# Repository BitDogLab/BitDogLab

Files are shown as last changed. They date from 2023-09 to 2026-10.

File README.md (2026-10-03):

<p align="center">
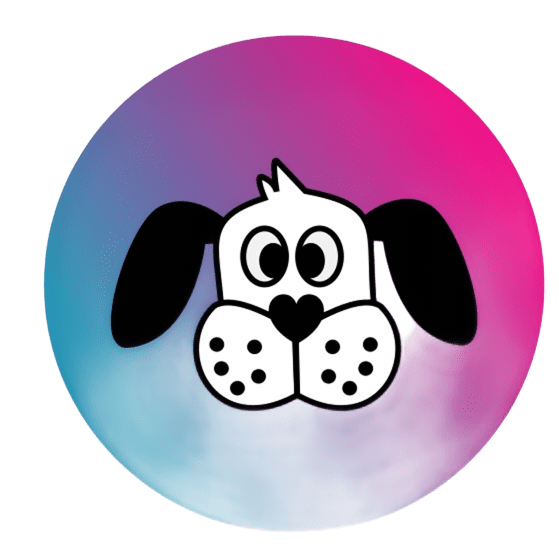
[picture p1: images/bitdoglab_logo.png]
BitDogLab logo
  
</p>

<h1 align="center">BitDogLab V7</h1>

<p align="center">
  Open-source educational hardware for embedded systems, programming, electronics, and physical computing.
</p>

<p align="center">
  <a href="README.md">English</a> |
  <a href="README.pt-BR.md">Português</a>
</p>

<p align="center">
  
  <br>
  <a href="https://comunidade-bitdoglab.web.app">https://comunidade-bitdoglab.web.app</a>
</p>

<p align="center">
  Não é da área de tecnologia? Este repositório é o espaço técnico do projeto — para professores e demais usuários, a <a href="https://comunidade-bitdoglab.web.app"><strong>Comunidade BitDogLab</strong></a> é uma porta de entrada mais amigável, com documentação, códigos e aplicações prontas.
</p>

BitDogLab is an initiative of the **Escola 4.0 project at FEEC/Unicamp**. It brings together the Raspberry Pi Pico ecosystem and the main peripherals used in embedded systems, providing a practical platform for education, experimentation, and project development.

The current board is **BitDogLab Version 7**, with support for Raspberry Pi Pico-compatible modules based on the **RP2040** and **RP2350** microcontrollers.

Its hands-on approach supports the development of scientific thinking, problem solving, collaboration, and digital culture, competencies emphasized by Brazil's National Common Curricular Base (BNCC).

---

## Board and Peripherals

<p align="center">
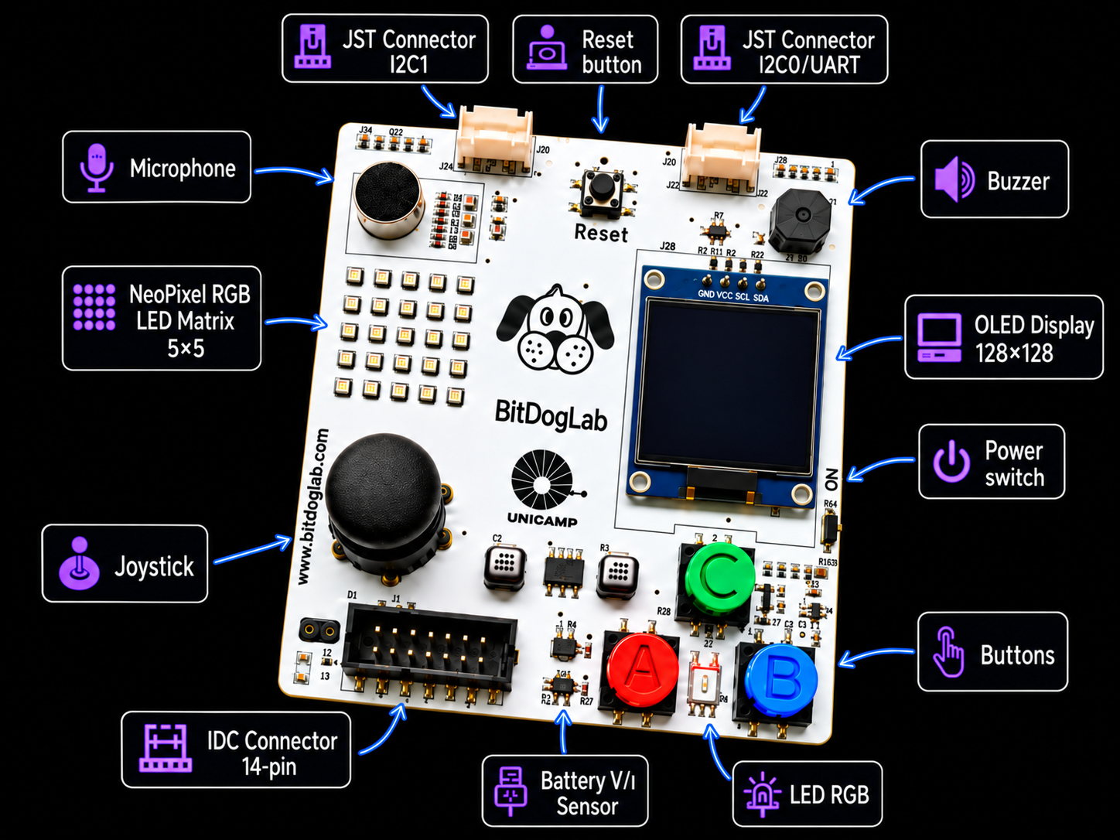
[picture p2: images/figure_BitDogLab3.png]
BitDogLab board and onboard peripherals
  
</p>

The board provides direct access to the main resources used in embedded-system education, including buttons, joystick, RGB LED, LED matrix, OLED display, microphone, buzzer, sensors, and expansion connectors.

---

## Recommended Learning Path

<p align="center">
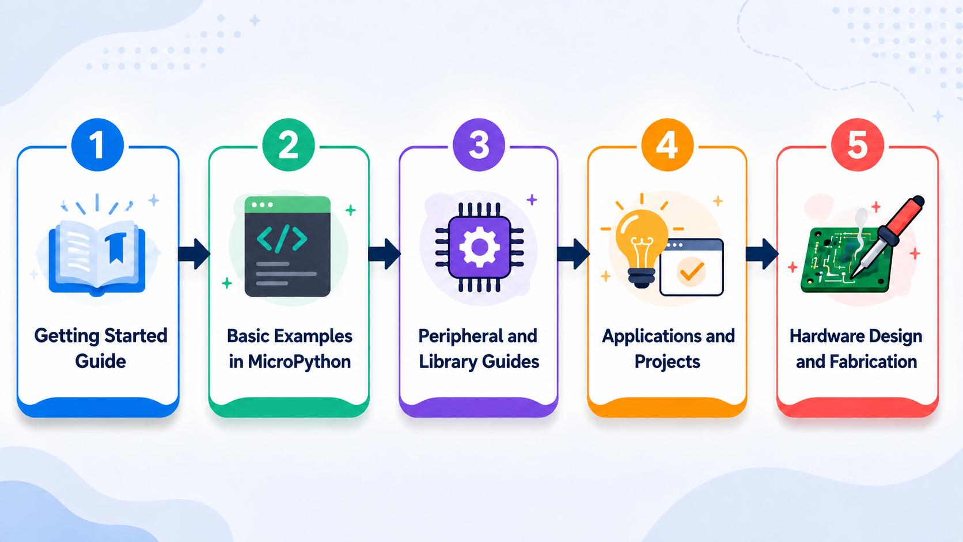
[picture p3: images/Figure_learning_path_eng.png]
Learning Path
  
</p>

```mermaid
flowchart LR
    A[Start Here guide] --> B[Basic MicroPython examples]
    B --> C[Peripheral guides and libraries]
    C --> D[Applications and projects]
    D --> E[Hardware design and fabrication]
```

1. Follow the [Start Here guide](COMECE_POR_AQUI_BitDogLab_V7_MicroPython.md) to prepare the board and run the first test.
2. Study the [`basic-examples/`](basic-examples/) directory, organized from simpler to more advanced peripherals.
3. Use the [V7 peripheral guides](doc/Bitdoglab%20V7/) and reusable [`libs_software/`](libs_software/) modules.
4. Explore and develop applications in [`projects/`](projects/).
5. Study or manufacture the board using the public files in [`pcb-prototyping/`](pcb-prototyping/).

---

## Start Programming

The fastest text-based path is MicroPython with Thonny:

- [Illustrated MicroPython start guide](COMECE_POR_AQUI_BitDogLab_V7_MicroPython.md)
- [60 basic peripheral examples](basic-examples/README.md)
- [Complete peripheral test](testar_perifericos_gerais.py)
- [MicroPython firmware](firmware/)
- [Reusable software libraries](libs_software/README.md)

---

## Active Programming Projects

Below are the tools currently being developed within the BitDogLab ecosystem to support different entry points into programming — from block-based logic to AI-assisted code generation.

### 🧩 Blockly for BitDogLab

Blockly is the easiest way to get started with BitDogLab. It is designed for students and beginners learning programming logic and embedded systems. The tool runs directly in the browser without requiring installation.

To use it:

[Open Blockly for BitDogLab](https://bitdoglab-blocos.github.io/BIPES-BITDOGLAB/ui/)

1. Connect the BitDogLab to the computer using a USB cable.
2. Open Blockly for BitDogLab, preferably in Chrome or Edge.
3. Select the serial port corresponding to the board.
4. Drag and connect blocks to create the program.
5. Click `Run` or `Upload` to send the program to the BitDogLab.

> **Important:** If the board already contains a file named `main.py`, remove it before using Blockly. This file can prevent the tool from communicating correctly with the microcontroller.

<br>

### 📄 BIH — Hardware Information Database

<p align="center">
  <a href="https://docs.google.com/document/d/13-68OqiU7ISE8U2KPRUXT2ISeBl3WPhXjGDFH52eWlU/edit?usp=sharing">
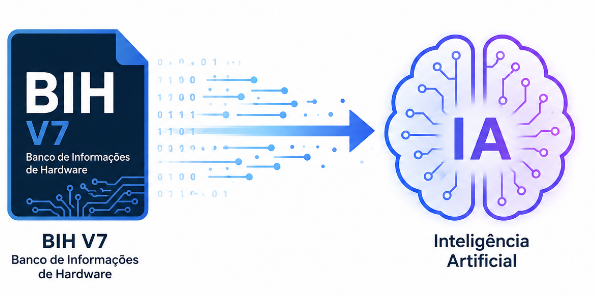
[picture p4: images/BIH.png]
BIH hardware information database for AI-assisted programming
    
  </a>
</p>

The **BIH** is a hardware information database designed to adapt the BitDogLab technical context for Large Language Models (LLMs), including ChatGPT, Gemini, and other AI assistants.

It describes the board's pin assignments, peripherals, interfaces, and hardware constraints. By providing the BIH to an LLM before requesting a program, the model can generate MicroPython or C/C++ code that better matches the BitDogLab hardware.

- [Open the BitDogLab V7 BIH](https://docs.google.com/document/d/13-68OqiU7ISE8U2KPRUXT2ISeBl3WPhXjGDFH52eWlU/edit?usp=sharing)
- [Open the visual hardware database](https://docs.google.com/document/d/1-2Eoo6H1gfTAlxZgFs26p7X4CeaLkS8X8hNTC96PetQ/edit?usp=sharing)

<br>

### 🔀 FluxCode

O BitDogLab FluxCode é um aplicativo Android que usa **IA multimodal** para transformar fluxogramas desenhados à mão em código **MicroPython** pronto para rodar na BitDogLab. A proposta é desplugada: o estudante primeiro desenvolve a lógica no papel usando símbolos de fluxograma, fotografa o desenho pelo app e recebe automaticamente o código correspondente, que pode ser executado ou salvo direto na placa.

Para usar:

[Baixar o BitDogLab FluxCode](https://drive.google.com/drive/folders/12xD7rVUsgQWKkneTLb5EA2QpiOx43nXb?usp=drive_link)

1. Conecte a BitDogLab ao smartphone via USB.
2. Desenhe o fluxograma em papel usando o gabarito de símbolos.
3. No app, toque em **Foto Código** e fotografe o fluxograma.
4. Revise o código MicroPython e o pseudocódigo gerados automaticamente.
5. Toque em **Executar** para rodar na placa, ou salve como `main.py` para execução automática ao ligar.

> Disponível apenas para Android. Requer MicroPython instalado na placa e um cabo USB compatível com transferência de dados (não apenas carregamento).

<br>

### 🎨 Pixel Art Application

**UNDER CONSTRUCTION**

---

## BitDogLab V7 Hardware

BitDogLab V7 integrates an RGB LED, a 5x5 WS2812B matrix, three buttons, analog joystick, buzzer, analog microphone, OLED display, power monitoring, and expansion connections around a Raspberry Pi Pico-compatible module.

The V7 hardware was developed in **Altium Designer**. Source files, schematic, PCB layout, BOM, pick-and-place data, STEP model, and public Gerber files for fabrication are available in [`pcb-prototyping/BitDogLab V7/`](pcb-prototyping/BitDogLab%20V7/).

<p align="center">
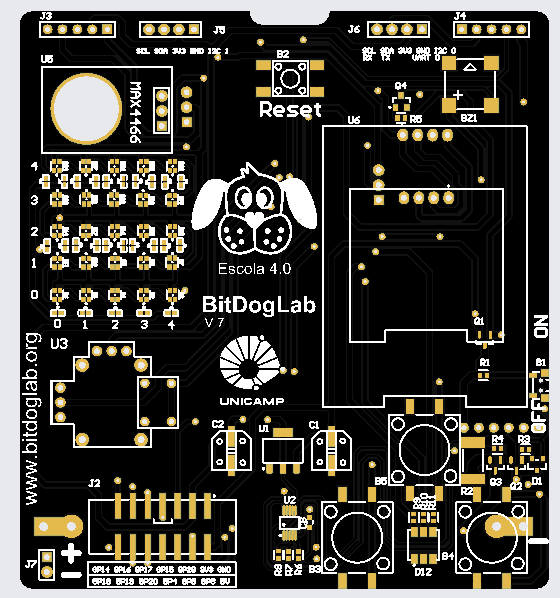
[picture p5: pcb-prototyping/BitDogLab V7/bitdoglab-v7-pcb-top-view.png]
BitDogLab V7 PCB top view
  
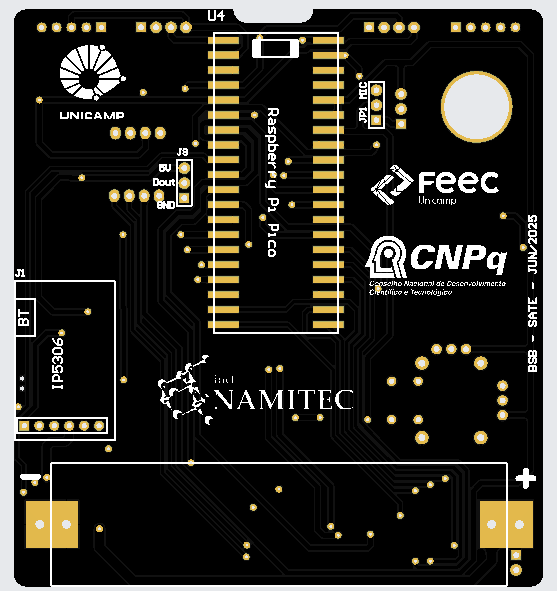
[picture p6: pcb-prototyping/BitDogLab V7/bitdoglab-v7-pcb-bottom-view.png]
BitDogLab V7 PCB bottom view
  
</p>

BitDogLab V6 was developed in **KiCad** and remains available for study and fabrication. See the complete [PCB and fabrication documentation](pcb-prototyping/README.md).

---

## Repository Structure

| Path | Content |
|---|---|
| [`basic-examples/`](basic-examples/) | Beginner-friendly MicroPython examples organized by peripheral. |
| [`doc/`](doc/) | BitDogLab V6 and V7 documentation and peripheral guides. |
| [`firmware/`](firmware/) | MicroPython firmware and installation resources. |
| [`libs_software/`](libs_software/) | Reusable MicroPython drivers and helper modules. |
| [`pcb-prototyping/`](pcb-prototyping/) | PCB source files and public manufacturing files. |
| [`projects/`](projects/) | Applications, sensors, IoT, tools, and hardware expansions. |

---

## Open Hardware and License

BitDogLab is open hardware. Its design and fabrication files are publicly available for study, modification, and manufacturing.

The project is licensed under the **CERN Open Hardware Licence Version 2 - Strongly Reciprocal (CERN-OHL-S v2.0)**. See [`LICENSE`](LICENSE).

---

## Initiative and Contributors

- Initiative: **Escola 4.0 - FEEC/Unicamp**
- Project coordination: **Prof. Dr. Fabiano Fruett**
- Contributors: students and collaborators from Escola 4.0 and FEEC/Unicamp
- Support: IEEE-EDS STEM outreach program and CNPq - INCT Namitec

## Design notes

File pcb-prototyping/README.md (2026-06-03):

# PCB Prototyping / Prototipagem de PCB

[English](#english) | [Portugues](#portugues)

## English

This directory contains the public PCB design and fabrication files for the BitDogLab boards.

The folder name is `pcb-prototyping` because not every file here was created in KiCad. It includes KiCad projects, Altium projects, manufacturing outputs, 3D models, images, BOM files and support libraries.

### Folder Structure

```text
pcb-prototyping/
+-- BitDogLab V6/
|   +-- bitdoglab-through-hole/
|   +-- bitdoglab-smd/
|   +-- component-libraries/
+-- BitDogLab V7/
    +-- Project Outputs for BitDogLab V7/
    +-- __Previews/
    +-- History/
    +-- bitdoglab-v7-pcb-top-view.png
    +-- bitdoglab-v7-pcb-bottom-view.png
```

### BitDogLab V6

BitDogLab V6 was developed in KiCad.

- `bitdoglab-through-hole/`: through-hole/DIY KiCad project files.
- `bitdoglab-smd/`: SMD KiCad project files, schematic, PCB layout, fabrication outputs and board images.
- `component-libraries/`: symbols, footprints, 3D models and support files used by the KiCad projects.

Common KiCad files found here:

- `.kicad_pro`: KiCad project file.
- `.kicad_sch`: schematic file.
- `.kicad_pcb`: PCB layout file.
- `.kicad_mod`: footprint file.
- `.kicad_sym`: symbol library file.
- `.step` / `.stp`: 3D model files.
- `.zip`: fabrication package when available.
- `.csv` / `.xlsx`: BOM or component data when available.

### BitDogLab V7

BitDogLab V7 was developed in Altium Designer.

<p align="center">
  BitDogLab V7 PCB top view
  BitDogLab V7 PCB bottom view
</p>

Main files:

- `BitDogLab V7.PrjPcb`: Altium PCB project.
- `BitDogLab V7.SchDoc`: Altium schematic document.
- `BitDogLab V7.PcbDoc`: Altium PCB layout document.
- `BitDogLab V7.OutJob`: Altium output job configuration.
- `BitDogLab V7.pdf`: exported schematic/documentation PDF.
- `BitDogLab V7_Lista de Materiais com Custo.xlsx`: bill of materials with cost information.
- `BitDogLab V7_Gerber.rar`: Gerber fabrication package.
- `Project Outputs for BitDogLab V7/`: manufacturing outputs exported from the project, including Gerber layers, drill reports, BOM, pick-and-place and 3D STEP model.
- `bitdoglab-v7-pcb-top-view.png`: technical top view image of the PCB.
- `bitdoglab-v7-pcb-bottom-view.png`: technical bottom view image of the PCB.

### Public Fabrication Files

Gerber files are publicly available for fabrication. They can be used by PCB manufacturers to produce the board.

Before ordering a board, review the fabrication package, BOM, drill files and pick-and-place data. Manufacturing settings can vary by supplier, so the files should always be checked in a Gerber viewer or CAM tool before production.

### Notes

- KiCad is recommended for opening and editing the BitDogLab V6 project files.
- Altium Designer is recommended for opening and editing the BitDogLab V7 source project files.
- Gerber and drill files can usually be inspected with vendor tools or independent Gerber viewers.
- Board images are provided as visual references and are not a replacement for fabrication data.

## Portugues

Esta pasta contem os arquivos publicos de projeto e fabricacao das placas BitDogLab.

O nome da pasta e `pcb-prototyping` porque nem todo arquivo aqui foi desenvolvido no KiCad. Ela inclui projetos KiCad, projetos Altium, arquivos de fabricacao, modelos 3D, imagens, listas de materiais e bibliotecas de apoio.

### Estrutura de Pastas

```text
pcb-prototyping/
+-- BitDogLab V6/
|   +-- bitdoglab-through-hole/
|   +-- bitdoglab-smd/
|   +-- component-libraries/
+-- BitDogLab V7/
    +-- Project Outputs for BitDogLab V7/
    +-- __Previews/
    +-- History/
    +-- bitdoglab-v7-pcb-top-view.png
    +-- bitdoglab-v7-pcb-bottom-view.png
```

### BitDogLab V6

A BitDogLab V6 foi desenvolvida no KiCad.

- `bitdoglab-through-hole/`: arquivos KiCad da versao through-hole/DIY.
- `bitdoglab-smd/`: arquivos KiCad da versao SMD, esquematico, layout da placa, saidas de fabricacao e imagens da placa.
- `component-libraries/`: simbolos, footprints, modelos 3D e arquivos de apoio usados pelos projetos KiCad.

Arquivos KiCad comuns nesta pasta:

- `.kicad_pro`: arquivo de projeto KiCad.
- `.kicad_sch`: arquivo de esquematico.
- `.kicad_pcb`: arquivo de layout da PCB.
- `.kicad_mod`: arquivo de footprint.
- `.kicad_sym`: biblioteca de simbolos.
- `.step` / `.stp`: modelos 3D.
- `.zip`: pacote de fabricacao quando disponivel.
- `.csv` / `.xlsx`: BOM ou dados de componentes quando disponiveis.

### BitDogLab V7

A BitDogLab V7 foi desenvolvida no Altium Designer.

<p align="center">
  Vista superior da PCB BitDogLab V7
  Vista inferior da PCB BitDogLab V7
</p>

Arquivos principais:

- `BitDogLab V7.PrjPcb`: projeto PCB do Altium.
- `BitDogLab V7.SchDoc`: documento de esquematico do Altium.
- `BitDogLab V7.PcbDoc`: documento de layout da PCB no Altium.
- `BitDogLab V7.OutJob`: configuracao de saidas do Altium.
- `BitDogLab V7.pdf`: PDF exportado com esquematico/documentacao.
- `BitDogLab V7_Lista de Materiais com Custo.xlsx`: lista de materiais com informacoes de custo.
- `BitDogLab V7_Gerber.rar`: pacote Gerber para fabricacao.
- `Project Outputs for BitDogLab V7/`: saidas de fabricacao exportadas do projeto, incluindo camadas Gerber, relatorios de furo, BOM, pick-and-place e modelo 3D STEP.
- `bitdoglab-v7-pcb-top-view.png`: imagem tecnica da face superior da PCB.
- `bitdoglab-v7-pcb-bottom-view.png`: imagem tecnica da face inferior da PCB.

### Arquivos Publicos para Fabricacao

Os arquivos Gerber estao disponiveis publicamente para fabricacao. Eles podem ser usados por fabricantes de PCB para produzir a placa.

Antes de encomendar uma placa, revise o pacote de fabricacao, a BOM, os arquivos de furo e os dados de pick-and-place. As configuracoes de fabricacao podem variar conforme o fornecedor, entao os arquivos devem sempre ser conferidos em um visualizador Gerber ou ferramenta CAM antes da producao.

### Observacoes

- O KiCad e recomendado para abrir e editar os arquivos da BitDogLab V6.
- O Altium Designer e recomendado para abrir e editar os arquivos fonte da BitDogLab V7.
- Arquivos Gerber e de furo normalmente podem ser inspecionados em ferramentas dos fabricantes ou em visualizadores Gerber independentes.
- As imagens da placa servem como referencia visual e nao substituem os arquivos de fabricacao.

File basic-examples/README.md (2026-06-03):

# Basic Examples - BitDogLab v7

Exemplos curtos em MicroPython, separados por periferico.

As pastas estao numeradas do mais simples para o mais avancado. Dentro de cada pasta, cada exemplo ja e um arquivo `.py` direto.

Para testar, abra o arquivo do exemplo na Thonny e salve na placa como `main.py`.

## Perifericos

- `01-led-rgb`: 10 exemplos
- `02-botoes`: 10 exemplos
- `03-buzzer`: 10 exemplos
- `04-matriz-led`: 10 exemplos
- `05-display-oled`: 10 exemplos
- `06-joystick`: 5 exemplos
- `07-microfone`: 5 exemplos

## Pinagem usada

- LED RGB: vermelho GPIO13, verde GPIO11, azul GPIO12
- Matriz 5x5 NeoPixel: GPIO7
- Display OLED: SDA GPIO2, SCL GPIO3
- Botoes: A GPIO5, B GPIO6, C GPIO10, joystick GPIO22
- Buzzer: GPIO21
- Joystick: X GPIO27, Y GPIO26
- Microfone: GPIO28

## Observacoes

- Exemplos com display usam `ssd1306.py` na placa.
- Exemplos com matriz usam a biblioteca `neopixel`.
- `read_u16()` retorna valores de 0 a 65535.
- `duty_u16()` tambem usa valores de 0 a 65535 para PWM.

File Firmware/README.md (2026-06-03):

# Firmware Beta v0.1 da BitDogLab com Micropython 1.22.1
### O Firmware da BitDogLab foi compilado em 04/02/2024 e já inclui as seguintes libs 3rd:
* ahtx0 (Sensor de temperatura/umidade AHT10 i2c)
* bh1750 (Sensor de luminosidade i2c)
* ssd1306 (Oled i2c)

## [Download do Firmware](https://github.com/Fruett/BitDogLab/tree/main/Firmware)

# Passo a passo para instalar o firmware da BitDogLab

### 1. Baixe o firmware de acordo com a versão da sua Raspberry pi pico
* [BitDogLab.uf2 para a Raspberry Pico](https://github.com/BitDogLab/BitDogLab/blob/main/Firmware/BitDogLab.uf2)  
* [BitDogLab_W.uf2 para a Raspberry Pico W](https://github.com/BitDogLab/BitDogLab/blob/main/Firmware/BitDogLab_W.uf2)

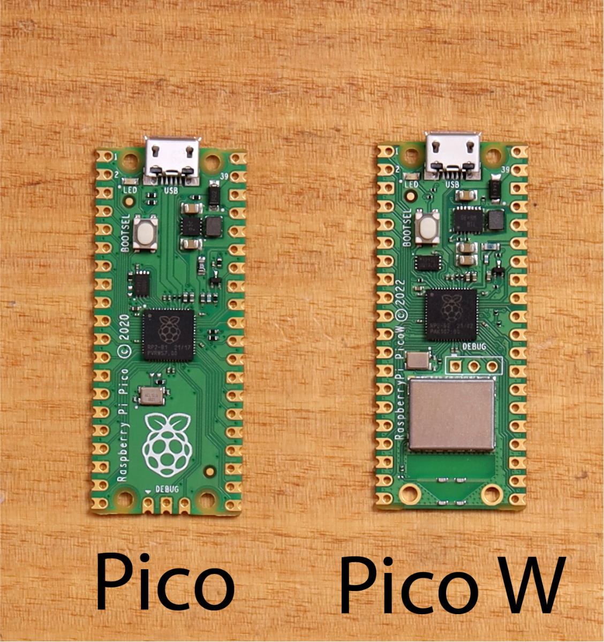
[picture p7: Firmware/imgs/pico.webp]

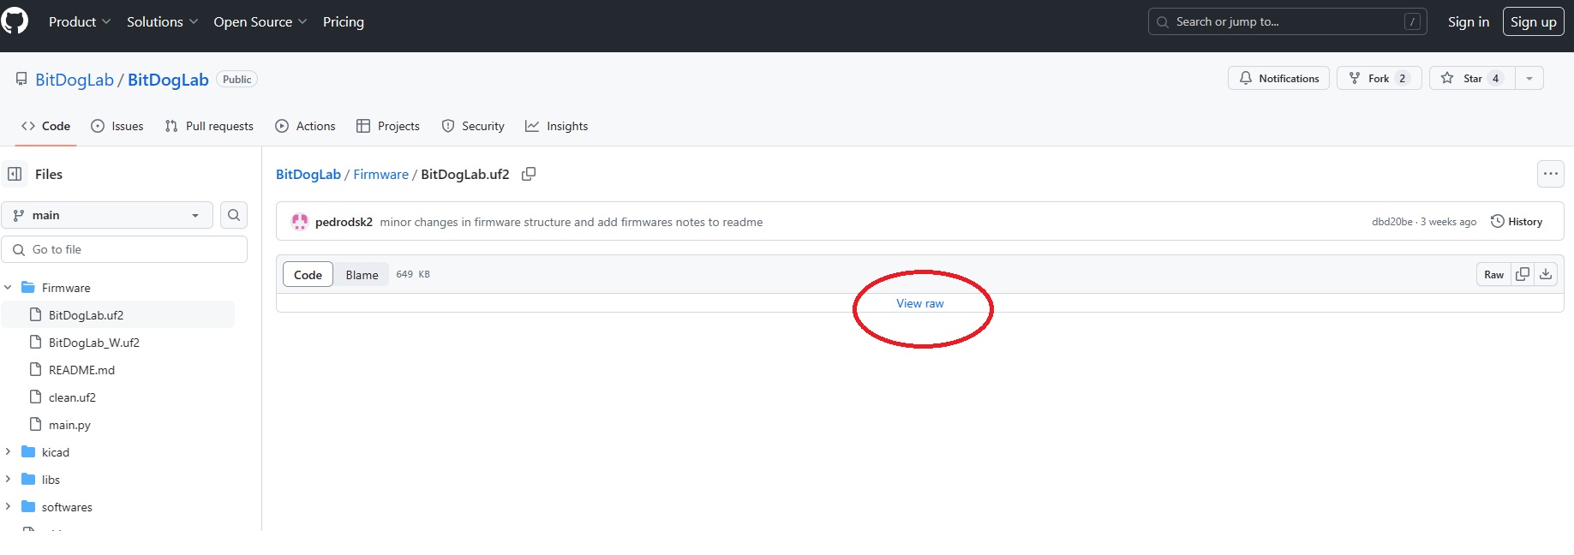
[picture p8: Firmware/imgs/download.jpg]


### 2. Entre no modo bootloader segurando o botão bootsel da raspberry pi, ainda com o botão pressionado, encaixe o cabo micro usb na raspberry pi pico e no computador.

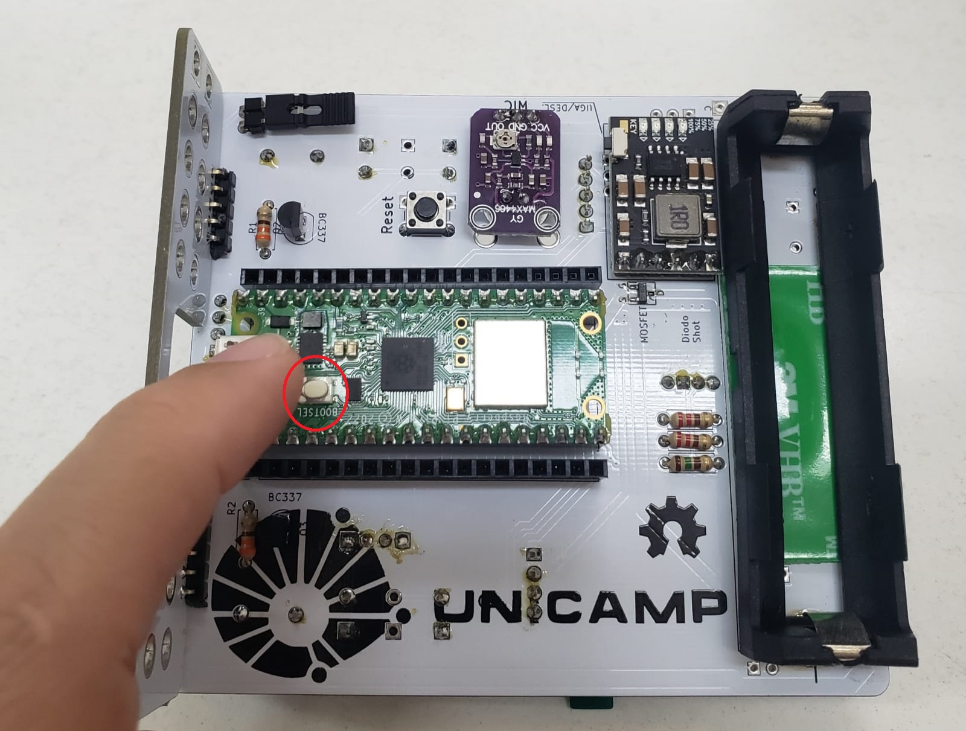
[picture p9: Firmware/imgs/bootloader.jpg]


### 3. Solte o botão e aguarde abrir uma nova janela do windows.

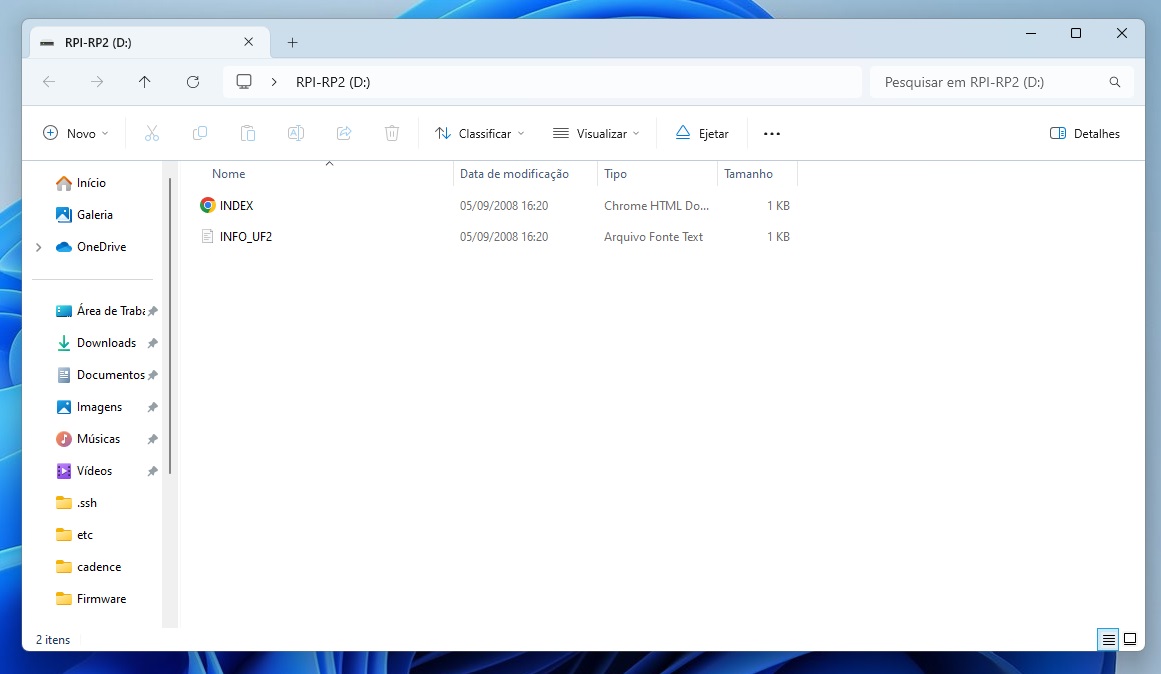
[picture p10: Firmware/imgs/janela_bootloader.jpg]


### 4. Copie o firmware baixado para a janela aberta no passo anterior

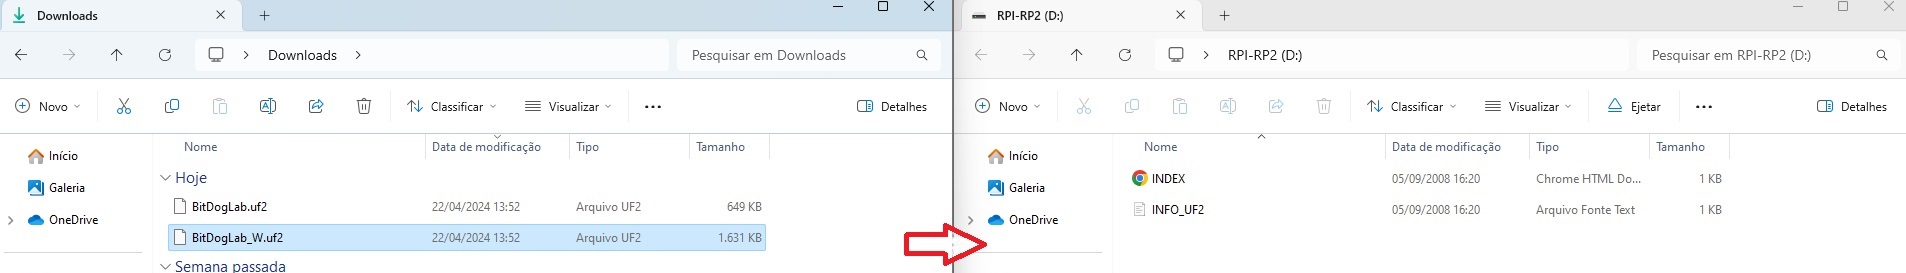
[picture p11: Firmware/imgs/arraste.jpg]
Copie o firmware para pasta de destino


### 5. Desfrute da sua BitDogLab (FIM)

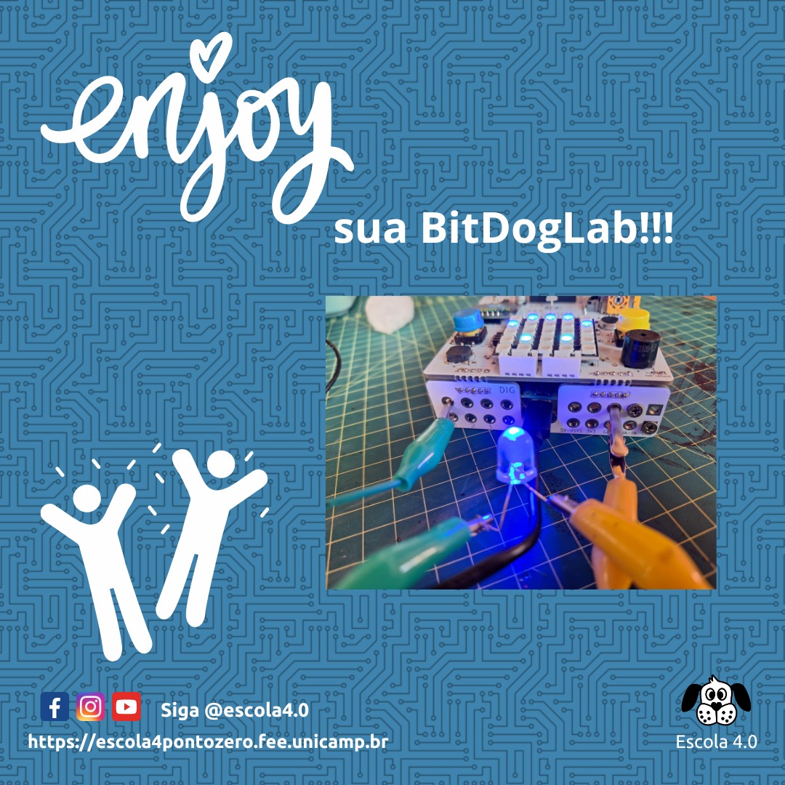
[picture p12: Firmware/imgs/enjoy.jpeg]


# Passo a passo para compilar o firmware da BitDogLab (opcional)
## Estes passos é para um usuário avançado que deseja fazer o build de uma nova versão do firmware com alguma nova personalização.
## Instalar as depedências na rpi4 (Precisa de um raspberry pi 4)
```
sudo apt update -y &
sudo apt install cmake build-essential libffi-dev git pkg-config gcc-arm-none-eabi -y
```
## Clonar os repositórios
```
cd ~/ &
git@github.com:Fruett/BitDogLab.git &
git clone https://github.com/micropython/micropython.git --branch master &
cd micropython &
make -C mpy-cross
```
### 1. Buid - Raspberry PI PICO
```
make -C ports/rp2 BOARD=RPI_PICO clean &
make -C ports/rp2 BOARD=RPI_PICO submodules &
make -C ports/rp2 BOARD=RPI_PICO FROZEN_MANIFEST=~/BitDogLab/libs_software/manifest.py
```
### 2. Build -Raspberry PI PICO W
```
make -C ports/rp2 BOARD=RPI_PICO_W clean
make -C ports/rp2 BOARD=RPI_PICO_W submodules
make -C ports/rp2 BOARD=RPI_PICO_W -j 16 FROZEN_MANIFEST=~/BitDogLab/libs_software/manifest_pico_w.py
```
## Pastas dos Firmwares
* ports/rp2/build-RPI_PICO/firmware.uf2
* ports/rp2/build-RPI_PICO_W/firmware.uf2

# Instalar as libs 3rd em um firmware já existente
```
sudo mpremote mip install github:Fruett/BitDogLab
```

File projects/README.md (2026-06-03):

# Projects

[English](#english) | [Portugues](#portugues)

## English

This folder contains BitDogLab projects, experiments, examples, tools, and hardware expansion projects. It is intended for complete or exploratory code that is larger than a clean beginner example.

Basic, beginner-friendly examples will be kept separately in the root `basic-examples/` folder.

### Folder structure

| Folder | Purpose |
|---|---|
| `hardware-examples/` | Existing examples focused on onboard hardware such as LEDs, buttons, buzzer, joystick, OLED display, microphone, I2C, and the LED matrix. |
| `sensor-examples/` | Existing examples focused on external or onboard sensors, such as accelerometers, light sensors, BME280/BME680, and presence sensors. |
| `hardware-expansion/` | Projects that involve custom hardware, expansion boards, shields, Gerber files, KiCad files, mechanical parts, or dedicated external modules. |
| `iot-communication/` | Projects and experiments related to IoT, LoRa, LoRaWAN, network communication, and connected devices. |
| `application-examples/` | Small application-oriented examples that combine multiple features for a specific use case. |
| `tools/` | Auxiliary software, web tools, visual interfaces, external examples, or support projects. |

### Hardware expansion projects

The `hardware-expansion/` folder includes projects that are not only software examples. These projects may include PCB files, Gerbers, CAD models, custom shields, expansion boards, or mechanical parts.

Current examples:

- `wireless-communication-module/`: wireless communication module previously stored as `WCM`.
- `RoboMovel/`: mobile robot project with code, mechanical files, and custom board files.
- `LoRa_Shield/`: LoRa shield related code and support files.
- `Expansao_PWM/`: software support for a PWM expansion board.

### IoT and communication projects

The `iot-communication/` folder groups projects focused on connectivity and networked applications. This includes LoRa, LoRaWAN, wireless communication experiments, and other IoT-oriented code that does not necessarily include custom hardware files.

### Notes

Some projects in this folder are legacy, experimental, or still being reviewed for BitDogLab v7. Before using them as official v7 examples, check the pin assignments, especially OLED I2C pins, buzzer pins, and any external sensor connections.

## Portugues

Esta pasta contem projetos, experimentos, exemplos, ferramentas e projetos com expansao de hardware da BitDogLab. Ela e destinada a codigos completos ou exploratorios, maiores do que um exemplo basico e limpo para iniciantes.

Os exemplos basicos e didaticos ficarao separados na pasta `basic-examples/`, na raiz do repositorio.

### Estrutura de pastas

| Pasta | Finalidade |
|---|---|
| `hardware-examples/` | Exemplos existentes focados no hardware da placa, como LEDs, botoes, buzzer, joystick, display OLED, microfone, I2C e matriz de LEDs. |
| `sensor-examples/` | Exemplos existentes focados em sensores externos ou embarcados, como acelerometros, sensores de luz, BME280/BME680 e sensores de presenca. |
| `hardware-expansion/` | Projetos que envolvem hardware proprio, placas expansoras, shields, arquivos Gerber, arquivos KiCad, partes mecanicas ou modulos externos dedicados. |
| `iot-communication/` | Projetos e experimentos relacionados a IoT, LoRa, LoRaWAN, comunicacao em rede e dispositivos conectados. |
| `application-examples/` | Pequenos exemplos de aplicacao que combinam varios recursos para um uso especifico. |
| `tools/` | Softwares auxiliares, ferramentas web, interfaces visuais, exemplos externos ou projetos de apoio. |

### Projetos com expansao de hardware

A pasta `hardware-expansion/` inclui projetos que nao sao apenas exemplos de software. Esses projetos podem conter arquivos de PCB, Gerbers, modelos CAD, shields personalizados, placas expansoras ou partes mecanicas.

Exemplos atuais:

- `wireless-communication-module/`: modulo de comunicacao sem fio que antes estava como `WCM`.
- `RoboMovel/`: projeto de robo movel com codigo, arquivos mecanicos e arquivos de placa propria.
- `LoRa_Shield/`: codigo e arquivos de apoio relacionados ao shield LoRa.
- `Expansao_PWM/`: suporte de software para uma placa expansora PWM.

### Projetos de IoT e comunicacao

A pasta `iot-communication/` agrupa projetos focados em conectividade e aplicacoes em rede. Isso inclui LoRa, LoRaWAN, experimentos de comunicacao sem fio e outros codigos voltados a IoT que nao necessariamente incluem arquivos de hardware proprio.

### Observacoes

Alguns projetos nesta pasta sao legados, experimentais ou ainda estao em revisao para a BitDogLab v7. Antes de usa-los como exemplos oficiais v7, confira a pinagem, principalmente os pinos I2C do display OLED, os pinos de buzzer e as conexoes de sensores externos.

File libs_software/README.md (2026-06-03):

# Software Libraries

[English](#english) | [Portugues](#portugues)

## English

This folder contains reusable software libraries for BitDogLab projects, mainly MicroPython modules used by examples, projects, and firmware running on Raspberry Pi Pico/Pico W/Pico 2.

These files are kept separate from project code so they can be copied to the board or imported by multiple examples without duplicating the same drivers in each project.

### Available libraries

- `ssd1306.py`: OLED display driver for SSD1306 displays.
- `neopixel.py`: NeoPixel/WS2812 LED matrix support.
- `matriz_bdl.py`: helper functions for the BitDogLab LED matrix.
- `ahtx0.py`: AHT20/AHTx0 temperature and humidity sensor driver.
- `bh1750.py` and `BH1750_alt.py`: BH1750 light sensor drivers.
- `bme280.py`: BME280 temperature, humidity, and pressure sensor driver.
- `mpu6500.py`, `mpu9250.py`, `ak8963.py`: motion sensor and magnetometer drivers.
- `micropyGPS.py`: GPS parsing library.
- `operator.py`: compatibility/helper module used by some MicroPython code.
- `manifest.py` and `manifest_pico_w.py`: MicroPython manifest files.

### I2C connections on BitDogLab v7

BitDogLab v7 uses two main I2C pin groups:

| Use | Bus | SDA | SCL |
|---|---:|---:|---:|
| External sensors | I2C0 | GPIO0 | GPIO1 |
| OLED display and expansion connector | I2C1 | GPIO2 | GPIO3 |

For the OLED display, use:

```python
from machine import Pin, I2C

i2c_display = I2C(1, sda=Pin(2), scl=Pin(3), freq=400000)
```

For external I2C sensors, use:

```python
from machine import Pin, I2C

i2c_sensors = I2C(0, sda=Pin(0), scl=Pin(1), freq=400000)
```

External sensors can also be connected to GPIO2/GPIO3 through the expansion connector. In BitDogLab v7, the OLED display is already connected to this I2C bus through PCB traces, so any extra device on GPIO2/GPIO3 must share the same bus and use a different I2C address.

When writing new BitDogLab v7 examples, prefer these pin assignments to avoid conflicts with older v6 examples.

## Portugues

Esta pasta contem bibliotecas de software reutilizaveis para projetos da BitDogLab, principalmente modulos MicroPython usados por exemplos, projetos e firmwares executados no Raspberry Pi Pico/Pico W/Pico 2.

Esses arquivos ficam separados dos codigos dos projetos para que possam ser copiados para a placa ou importados por varios exemplos sem duplicar os mesmos drivers em cada projeto.

### Bibliotecas disponiveis

- `ssd1306.py`: driver para display OLED SSD1306.
- `neopixel.py`: suporte para matriz NeoPixel/WS2812.
- `matriz_bdl.py`: funcoes auxiliares para a matriz de LEDs da BitDogLab.
- `ahtx0.py`: driver para sensor AHT20/AHTx0 de temperatura e umidade.
- `bh1750.py` e `BH1750_alt.py`: drivers para sensor de luz BH1750.
- `bme280.py`: driver para sensor BME280 de temperatura, umidade e pressao.
- `mpu6500.py`, `mpu9250.py`, `ak8963.py`: drivers para sensores de movimento e magnetometro.
- `micropyGPS.py`: biblioteca para interpretacao de dados GPS.
- `operator.py`: modulo auxiliar/de compatibilidade usado por alguns codigos MicroPython.
- `manifest.py` e `manifest_pico_w.py`: arquivos de manifesto do MicroPython.

### Conexoes I2C na BitDogLab v7

A BitDogLab v7 usa dois grupos principais de pinos I2C:

| Uso | Barramento | SDA | SCL |
|---|---:|---:|---:|
| Sensores externos | I2C0 | GPIO0 | GPIO1 |
| Display OLED e conector de expansao | I2C1 | GPIO2 | GPIO3 |

Para o display OLED, use:

```python
from machine import Pin, I2C

i2c_display = I2C(1, sda=Pin(2), scl=Pin(3), freq=400000)
```

Para sensores externos I2C, use:

```python
from machine import Pin, I2C

i2c_sensors = I2C(0, sda=Pin(0), scl=Pin(1), freq=400000)
```

Sensores externos tambem podem ser conectados aos GPIO2/GPIO3 pelo conector de expansao. Na BitDogLab v7, o display OLED ja esta conectado a esse barramento I2C pelas trilhas da placa, entao qualquer dispositivo extra em GPIO2/GPIO3 deve compartilhar o mesmo barramento e usar um endereco I2C diferente.

Ao escrever novos exemplos para a BitDogLab v7, prefira essa pinagem para evitar conflitos com exemplos antigos da v6.

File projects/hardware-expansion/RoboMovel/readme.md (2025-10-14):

# 🤖 Robô Móvel Skid-Steer — BitDogLab

Este projeto implementa o controle completo de um **robô móvel 4x4 tipo Skid-Steer** desenvolvido para a **placa BitDogLab (v6 ou v7)**.  
O robô é controlado via **Bluetooth** por aplicativos Android e utiliza um **Raspberry Pi Pico / Pico W** programado em **MicroPython**.

---

> ⚠️ **Importante:**  
> O arquivo no repositório se chama:
> ```
> movimentacaoBluetooth_buzina_luz.py
> ```
>  
> Ao enviar para a placa BitDogLab usando o **Thonny**, salve o arquivo com o nome:
> ```
> main.py
> ```
> Assim, o código será executado automaticamente quando o robô for ligado.

---

## 🧩 Lista de componentes

| Componente | Descrição |
|---|---|
| **Placa BitDogLab** | Versão v6 ou v7 com Raspberry Pi Pico / Pico W |
| **Motores TT DC** | 4 motores 3–6 V com redutor e rodas de 68 mm |
| **Conexões dos motores** | 2 traseiros (master) → JST-SH 2P + jumpers fêmea soldados<br>2 dianteiros (slave) → jumpers macho soldados |
| **Chassis** | Impressão 3D em ABS — modelo v4 |
| **Mãos-francesas (suportes laterais)** | Impressas em ABS — modelo v3<br>Fixadas com **fita dupla-face** |
| **Parafusos e porcas** | 4x M3x25 + 4x M3 |
| **Ponte H** | Módulo **TB6612FNG** (integrado à PCB BitDogLab) |
| **Cabo flat IDC 2x7** | Conecta placa BitDogLab à ponte H |
| **Suporte de bateria** | 2x células 18650 Li-ion |
| **Baterias** | 2x 18650 (3.7 V) — total ~7.4 V |
| **Conector de energia** | XT30 macho |
| **Módulo Bluetooth** | HC-05 |
| **Adesivo dupla-face** | Para fixação dos suportes |

---

## 📱 Aplicativos Android compatíveis

O robô é controlado via **Bluetooth UART** usando os seguintes aplicativos (disponíveis no Google Play):

- **Arduino Bluetooth Controller** (por *Giristudio*)  
- **BT Car Controller - Arduino/ESP** (por *Giristudio*)

Ao apertar botões no aplicativo, ambos enviam comandos seriais simples (`F`, `B`, `L`, `R`, etc.) via Bluetooth.

---

## 🧠 Funcionalidades principais

| Função | Descrição |
|---|---|
| 🔄 **Movimento Skid-Steer 4x4** | Controle diferencial de dois lados independentes (esquerdo e direito). |
| 💡 **Controle de LEDs NeoPixel** | Iluminação RGB com ajuste de brilho e modos de luz. |
| 🔊 **Buzina sonora** | Alterna entre sons “Beep Beep” e “Foon Foon”. |
| 🔌 **Comunicação Bluetooth (UART)** | Recebe comandos em tempo real de um app Android. |
| ⚙️ **Controle de velocidade** | Ajustável de 0 a 9 (PWM). |

---

## 🪄 Sub-rotinas principais no código

O código **`movimentacaoBluetooth_buzina_luz.py`** é estruturado em funções que organizam o comportamento do robô.  
Algumas das subrotinas mais relevantes são:

| Função | Descrição |
|---|---|
| `configura_pwm_motores()` | Inicializa o PWM dos motores e define o duty cycle padrão. |
| `move_frente()`, `move_tras()`, `vira_esquerda()`, `vira_direita()` | Controlam os quatro motores de forma coordenada. |
| `para_motores()` | Envia duty 0 para todos os motores (freio eletrônico). |
| `beep()` e `foon()` | Geram dois tipos distintos de som no buzzer PWM. |
| `alterna_som()` | Alterna entre os modos de buzina (“Beep” ↔ “Foon”). |
| `acende_leds(cor, brilho)` | Define a cor e intensidade dos LEDs NeoPixel. |
| `alterna_modo_luz()` | Cicla entre quatro modos de iluminação: apagado → fraco → apagado → forte. |
| `ajusta_brilho(delta)` | Aumenta ou diminui o brilho manualmente via comandos `+` e `-`. |
| `processa_comando_uart(cmd)` | Lê e executa os comandos recebidos via Bluetooth. |

---

## 🔤 Comandos via Bluetooth

| Comando | Ação |
|---|---|
| `F` | Avança |
| `B` | Recuo |
| `L` | Vira à esquerda |
| `R` | Vira à direita |
| `S` | Para |
| `0–9` | Define velocidade (PWM) |
| `W` | Liga luz branca |
| `i` | Desliga luz |
| `I` / `X` | Alterna modos de luz |
| `+` / `-` | Ajusta brilho manualmente |
| `Y` | Alterna som da buzina |

---

## 🧱 Modelos 3D (impressão)

Os arquivos STL do robô estão disponíveis para **impressão 3D em ABS**:

| Arquivo | Função |
|---|---|
| `ABS_1.0070_chassis_para_4x4_v4.STL` | Chassis principal |
| `ABS_dir_1.0071_suporteBitDog_MaoFrancesa_v3.STL` | Suporte lateral direito (“mão francesa”) |
| `ABS_esq_1.0071_suporteBitDog_MaoFrancesa_v3.STL` | Suporte lateral esquerdo (“mão francesa”) |

As mãos francesas são fixadas ao chassis com **fita dupla-face**.

---

## ⚡ Alimentação

- 2x baterias **Li-ion 18650 (3.7 V)** em série → **7.4 V nominal**
- Conector **XT30**
- Corrente típica: 0.5–2 A total
- Pode ser recarregado externamente com carregador balanceado ou módulo BMS

---

## 🧰 Como gravar o programa

1. Abra o **Thonny IDE**.  
2. Conecte o Raspberry Pi Pico (BitDogLab).  
3. Abra o arquivo `movimentacaoBluetooth_buzina_luz.py`.  
4. Salve-o no dispositivo com o nome **`main.py`**.  
   - Menu: *Arquivo → Salvar como... → Raspberry Pi Pico → main.py*  
5. Reinicie a BitDogLab — o programa iniciará automaticamente.

---

## 🧪 Teste rápido

1. Conecte o módulo **HC-05** ao smartphone Android.  
2. Abra um dos aplicativos Bluetooth acima.  
3. Aperte botões da buzina e luz
4. Observe a resposta luminosa/sonora do robô.
5. Se funcionar, então você pode usar a movimentação normalmente.

---

## 🧑‍🔬 Créditos

**Projeto BitDogLab — Robô Móvel Skid-Steer**  
Campinas – SP 🇧🇷

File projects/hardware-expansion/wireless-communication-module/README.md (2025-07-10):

# Wireless Communication Module

This document aims to describe the open-source hardware of the wireless communication module used in the BitDogLab project.

It is based on the ESP32-C3 microcontroller (RISC-V), developed by Seeed Studio XIAO, as well as an RFM95W LoRa transceiver.

## Github Structure
```bash
└─── Gerber Files "the following files contain the PCB Fabrication data"
```

## Hardware Description

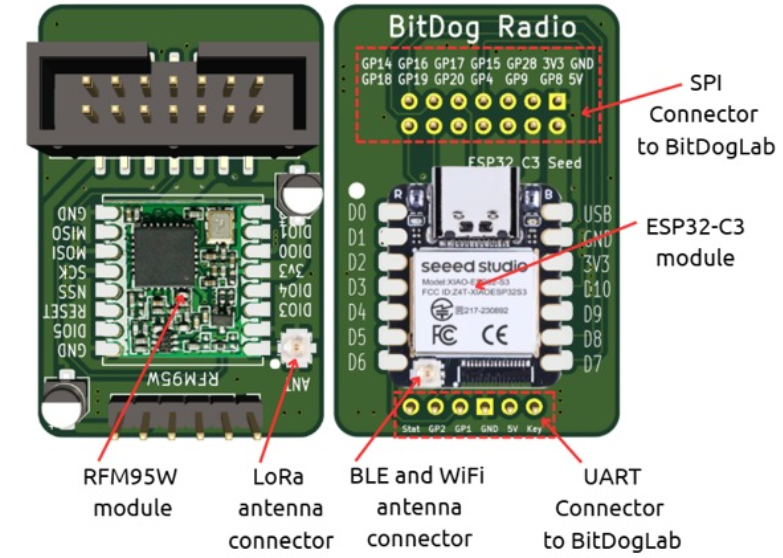
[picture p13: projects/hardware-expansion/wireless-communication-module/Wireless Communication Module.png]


The developed module, based on the ESP32-C3 (RISC-V) and the RFM95W (SX1276 chip), is designed so that both components are connected via the SPI interface (MOSI, MISO, SCK, RST), along with additional auxiliary pins (DIO0, DIO1, and DIO2), all of which are required to enable full LoRaWAN communication functionality.

The following table shows the pin mapping between the ESP32-C3 and the RFM95W.

| ESP32-C3 | RFM95W |
|---|---|
| GND | GND |
| 3,3V | 3,3V |
| D10/MOSI | MOSI |
| D9/MISO | MISO |
| D8/SCK | SCK |
| D0/CS | NSS |
| D2 | RESET |
| D1 | DIO0 |
| D5 | DIO1 |
| D4 | DIO2 |

Regarding the D0/CS pin, it is necessary to use a pull-up resistor (e.g., 10 Ω). This prevents unintended communication with the RFM95W during the ESP32-C3’s startup.

## Physical Connections

The WCM (Wireless Communication Module) enables connection to the BitDogLab through UART and SPI communication when using the 14-pin IDC header, or through UART only when using the 6-pin connector.

For SPI communication, the ESP32-C3 must act as the Master, since the communication between the ESP32-C3 and the RFM95W is SPI-based.

The following table shows the IDC pinout in relation to the ESP32-C3.

<table>
  <tr>
    <td>ESP32-C3</td>
    <td>D8/SCK</td>
    <td>D7/RX</td>
    <td>D6/TX</td>
    <td>D10/MOSI</td>
    <td></td>
    <td>3,3V</td>
    <td>GND</td>
  </tr>
  <tr>
    <td>IDC 14 pins</td>
    <td>GPIO14</td>
    <td>GPIO16</td>
    <td>GPIO17</td>
    <td>GPIO15</td>
    <td>GPIO28</td>
    <td>3,3 V</td>
    <td>GND</td>
  </tr>
  <tr>
    <td></td><td></td><td></td><td></td><td></td><td></td><td></td><td></td>
  </tr>
  <tr>
    <td>IDC 14 pins</td>
    <td>GPIO18</td>
    <td>GPIO19</td>
    <td>GPIO20</td>
    <td>GPIO4</td>
    <td>GPIO9</td>
    <td>GPIO8</td>
    <td>5 V</td>
  </tr>
  <tr>
    <td>ESP32-C3</td>
    <td>D4/SDA</td>
    <td>D5/SCL</td>
    <td></td>
    <td>D3/CS_RP</td>
    <td>D2/RESET_LORA</td>
    <td>D9/MISO</td>
    <td>5 V</td>
  </tr>
</table>

Next, the following table shows the 6-pin connector configuration.

<table>
  <tr>
    <td>Raspberry Pi Pico</td>
    <td>Key</td>
    <td>5 V</td>
    <td>GND</td>
    <td>GPIO1</td>
    <td>GPIO0</td>
    <td>Stat</td>
  </tr>
  <tr>
    <td>ESP32-C3</td>
    <td></td>
    <td>5 V</td>
    <td>GND</td>
    <td>D6/TX</td>
    <td>D7/RX</td>
    <td></td>
  </tr>
</table>

## Wireless Connections

This module supports three types of wireless connections: BLE and Wi-Fi through the ESP32-C3 chip, and LoRa via the RFM95W module. Both the ESP32-C3 and the RFM95W module have antenna connectors, as shown in the "Hardware Description" section.

The RFM95W module is fully connected to the ESP32-C3. Therefore, in order to use it, the ESP32-C3 must run a code that handles this connection. In other words, the ESP32-C3 is responsible for all network management, which is its main function. Developing a unified library capable of managing all networks within the same code is entirely feasible and is one of the main goals of this module.

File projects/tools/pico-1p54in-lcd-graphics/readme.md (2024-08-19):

# BitDogLab Pico Tela LCD 1.54 inch Colorida SPI

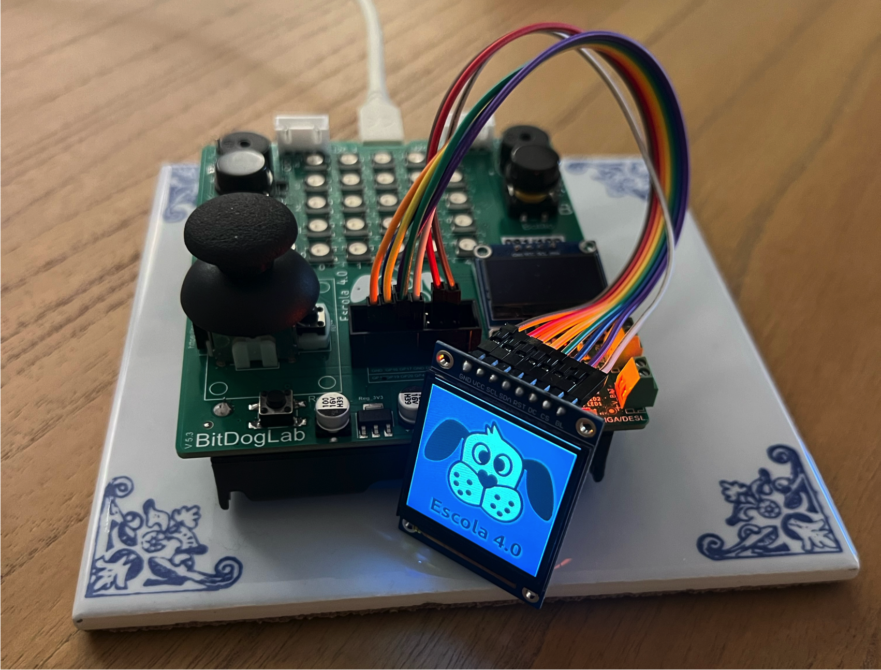
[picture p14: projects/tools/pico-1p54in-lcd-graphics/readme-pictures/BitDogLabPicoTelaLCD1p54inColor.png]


Adicione a sua BitDogLab uma tela de 220 ppi (240x240 pixels) com 16-bit de cores, ou seja 65536 entre RGB (Red/Vermelho, Blue/Azul e Green/Verde) como um display IPS (in plane switching LCD) usando protocolo SPI (serial peripheral interface). 

Devido ao display utilizado nesse artigo possuir comunicação SPI e ser de baixo custo, a empresa [Pimoroni](https://shop.pimoroni.com/products/1-54-spi-colour-square-lcd-240x240-breakout) adaptou um driver que pode ser utilizado para controlar esse display com uma raspberry pi, o driver foi originalmente criado por [Libdriver](https://github.com/libdriver/st7789) que controla o chip ST7786 da empresa [Sitronix](https://github.com/libdriver/st7789/blob/master/datasheet/st7789_datasheet.pdf), um chip capaz de controlar até 240x320 pixels com 18bit de cores (262k cores) com memoria em frame para display TFT (transistor de película fina).

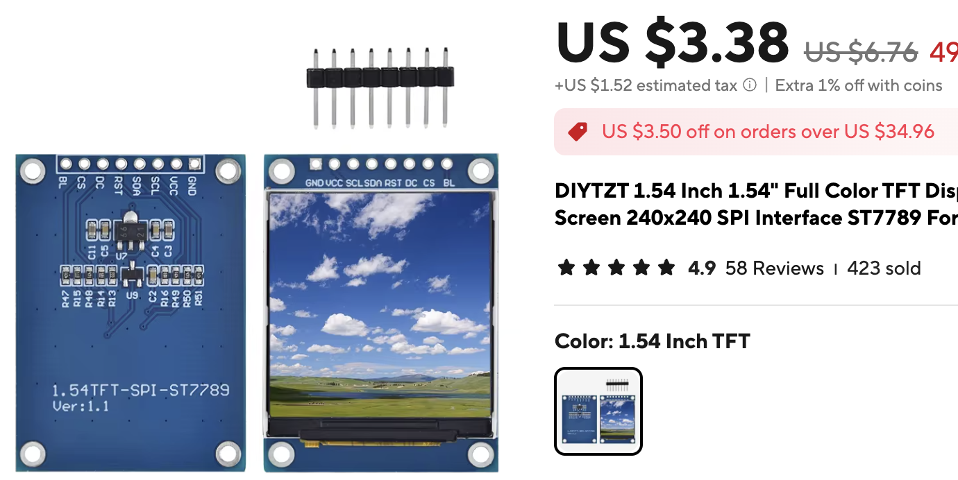
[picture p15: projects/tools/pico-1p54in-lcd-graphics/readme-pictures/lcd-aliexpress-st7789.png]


> [!NOTE]
> Apesar de ser mencionado o baixo custo, a alternativa da Pimoroni é bem cara (**£19.80 ou ~R$139.00 considerando R$7.0=£1.0**), contudo consegui adaptar uma solução realmente de baixo custo [1.54 Inch Full Color TFT Display Module HD IPS LCD LED Screen 240x240 SPI Interface ST7789](https://www.aliexpress.com/item/1005006953775674.html?spm=a2g0o.order_list.order_list_main.16.21ef18022WjQ8F) no Aliexpress ($3.38 ou ~R$18.50 considerando R$5.49=$1.0). 

> [!WARNING]
> É de extrema importância selecionar um display que externalize em seus pinos o chip select (CS), devido a ter opções desse display para Arduino que funcionam sem o pino CS para Raspberry pi pico e/ou variantes é necessário ter o pino CS para que o display funcione corretamente. 

Seguem as características do display: 
* Display LCD colorido de 1.54" (240x240 pixels)
* Interface SPI
* Compatível com 3.3V ou 5V
* Proteção de polaridade reversa
* Compatível com qualquer modelo de Raspberry Pi ([Python library](https://github.com/pimoroni/st7789-python)))
* Compativel com qualquer modelo de Raspberry Pi Pico ([C++/MicroPython libraries](https://github.com/pimoroni/pimoroni-pico))

Seguem as especificações do display:
* 240x240 pixels (~220 PPI)
* Area ativa de 27.72mm x 27.72mm 
* Brilho: 250 cd/m^2
* Razão de contraste 900:1
* Ângulo de visão de 160° (horizontal e vertical)
* Chip driver ST7789V
* Dimensões aproximadas: 44mm x 32mm x 5mm

Esse apaixonante Display é uma das melhores maneiras de adicionar algo pequeno e colorido com boa qualidade de brilho a qualquer projeto usando raspberry pi pico. Como o display usar comunicação 4-wire SPI e possui seu próprio frame buffer endereçado pixel-a-pixel, ele pode ser usado com qualquer micrcontrolador. Mesmo um microcontrolador com memória muito pequena e poucos pinos é possível usar o display de 1.54" display IPS com 240x240 e 16-bit de cores por pixel, as cores se apresentam bem até 80 graus de inclinação da pessoa que visualiza o mesmo em qualquer direção. O driver TFT (ST7789) é bem similar ao popular ST7735 que possui várias bilbiotecas que o suportam bem.

O módulo tem o display soldado a placa (por meio de um conector flexivel) assim como possui um regulador de ultra-baixa voltagem de drop 3.3V e conversores de sinais para lógica e alimentaçào de 3/5V.

## Preparação: 

Neste artigo vamos usar a biblioteca de gráficos open source [pico graphics](https://github.com/pimoroni/pimoroni-pico/tree/main/micropython/modules/picographics) escrita pela Pimoroni, que permite desenhar pixels, linhas, rectângulos, circulos, texto and bitmaps assim como imprimir JPG, PNG, QR-codes. Os exemplos escritos aqui foram feitos em Micropython, dessa forma recomendamos que além dos exemplos o usuário use o [binário da pimoroni](https://github.com/pimoroni/pimoroni-pico/releases) que já está compilado para as diversas versões da raspberry pi pico.

* Pimoroni Raspberry Pi Pico [Compiled uf2 Micropython with picographics and ST7789 Driver](https://github.com/pimoroni/pimoroni-pico/releases/download/v1.23.0-1/pico_usb-v1.23.0-1-pimoroni-micropython.uf2)
* Pimoroni Raspberry Pi Pico W [Compiled uf2 Micropython with picographics and ST7789 Driver](https://github.com/pimoroni/pimoroni-pico/releases/download/v1.23.0-1/picow-v1.23.0-1-pimoroni-micropython.uf2)

> [!WARNING]
> Carregue o firmware acima na bitdoglab executando os passos do [manual de gravação de firwmare](https://github.com/BitDogLab/BitDogLab/tree/main/doc#grava%C3%A7%C3%A3o-do-firmware)

O porte dos códigos desse repositório para compatibilidade com a bitdoglab foi feita por [Juliano Oliveira](https://github.com/jrfo-hwit)

Antes de começar a executar o tutorial sugiro passar antes pelo [manual do BitDogLab](https://github.com/BitDogLab/BitDogLab/tree/main/doc) que vai te ajudar a entender como montar a placa e preparar a mesma para receber os códigos em microphyton desse repositório.

### Conexão de hardware do display com a bitdoglab

Antes de conectar o display com a bitdoglab certifique-se que a barra de pinos macho 1x8 está soldada como na figura abaixo.

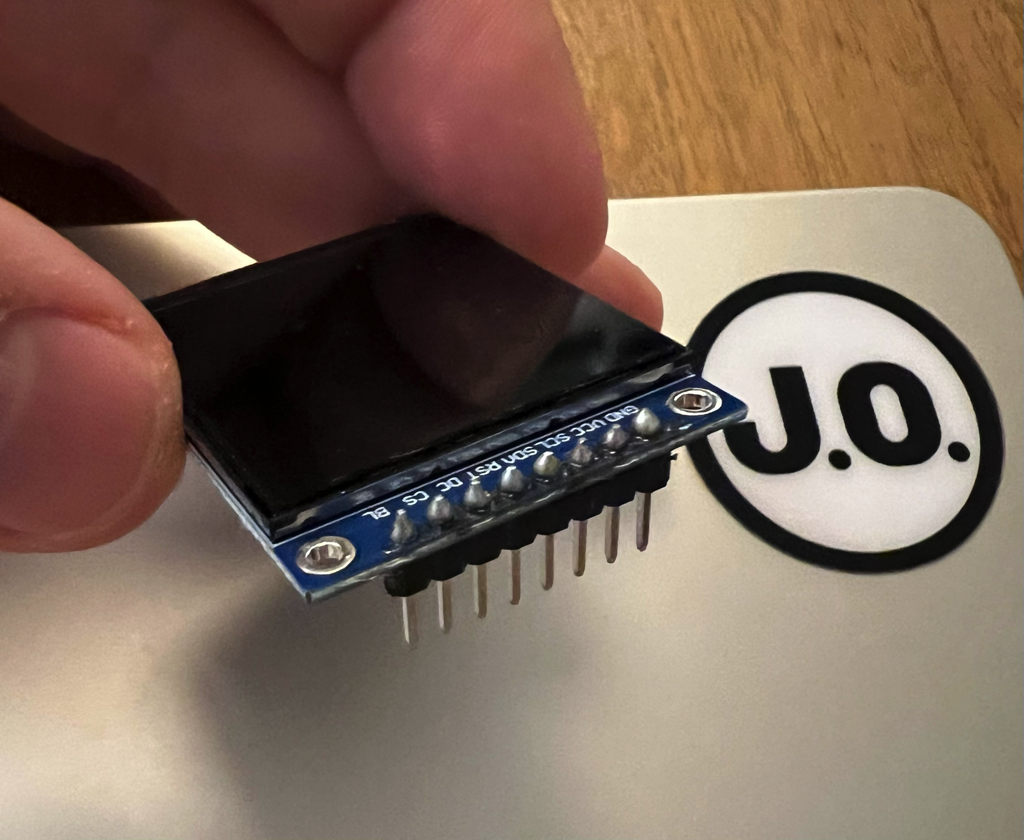
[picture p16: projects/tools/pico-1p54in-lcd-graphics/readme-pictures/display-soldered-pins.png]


Uma vez com a barra de pinos soldada, use jumpers coloridos do tipo [fêmea-fêmea](https://www.makerhero.com/produto/jumpers-femea-femea-x40-unidades/) para conectar o display direto no conector IDC da bitdoglab como ilustrado abaixo.

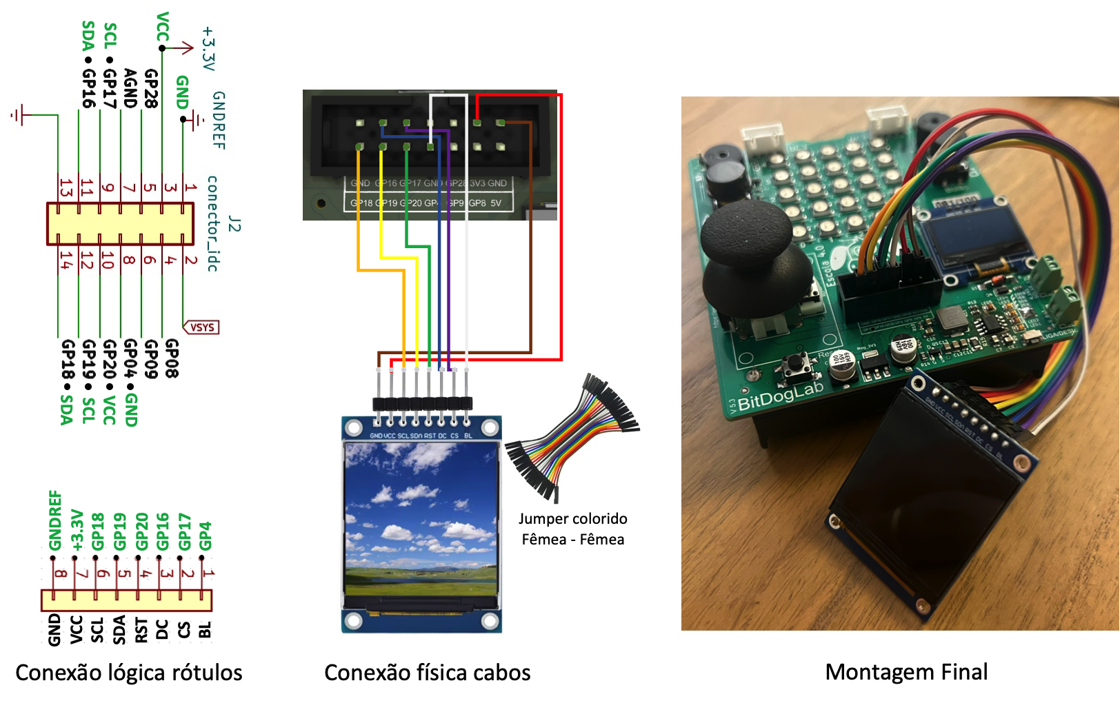
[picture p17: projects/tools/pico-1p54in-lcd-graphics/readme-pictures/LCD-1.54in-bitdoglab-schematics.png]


As conexões são as seguintes (Raspberry pi Pico -> Display):
* GP4 -> Pino IO BackLigth (BL)
* GP16 -> Pino IO Data Command (DC)
* GP17 -> Pino SPI chip select (CS)
* GP18 -> Pino SPI system clock (SCK / SCL) 
* GP19 -> Pino SPI saida de dados (SDA / MOSI)
* GP20 -> Pino IO Reset (RST)
* GND -> GNDREF
* +3v3 -> +3v3

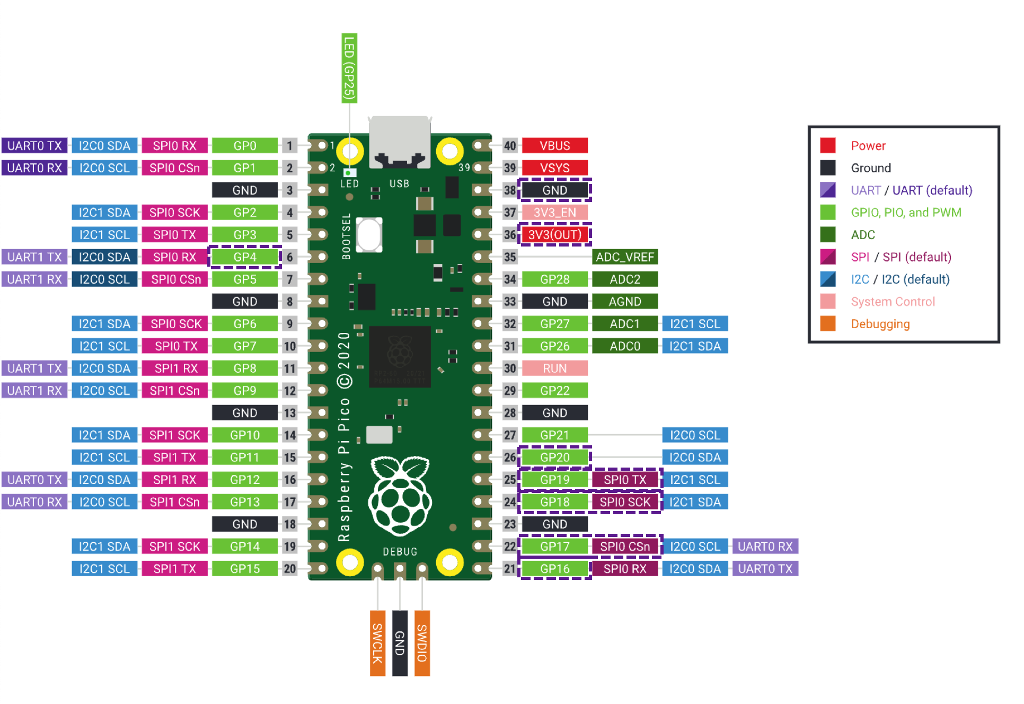
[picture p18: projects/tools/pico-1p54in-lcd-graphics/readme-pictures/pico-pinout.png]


Para concluir a preparação é necessário copiar o arquivo LCD.py (arquivo que contém a diferença do display genérico para o display pimoroni, que basicamete é o procedimento de reset do mesmo) para a sua bitdoglab (raspberry pi pico).

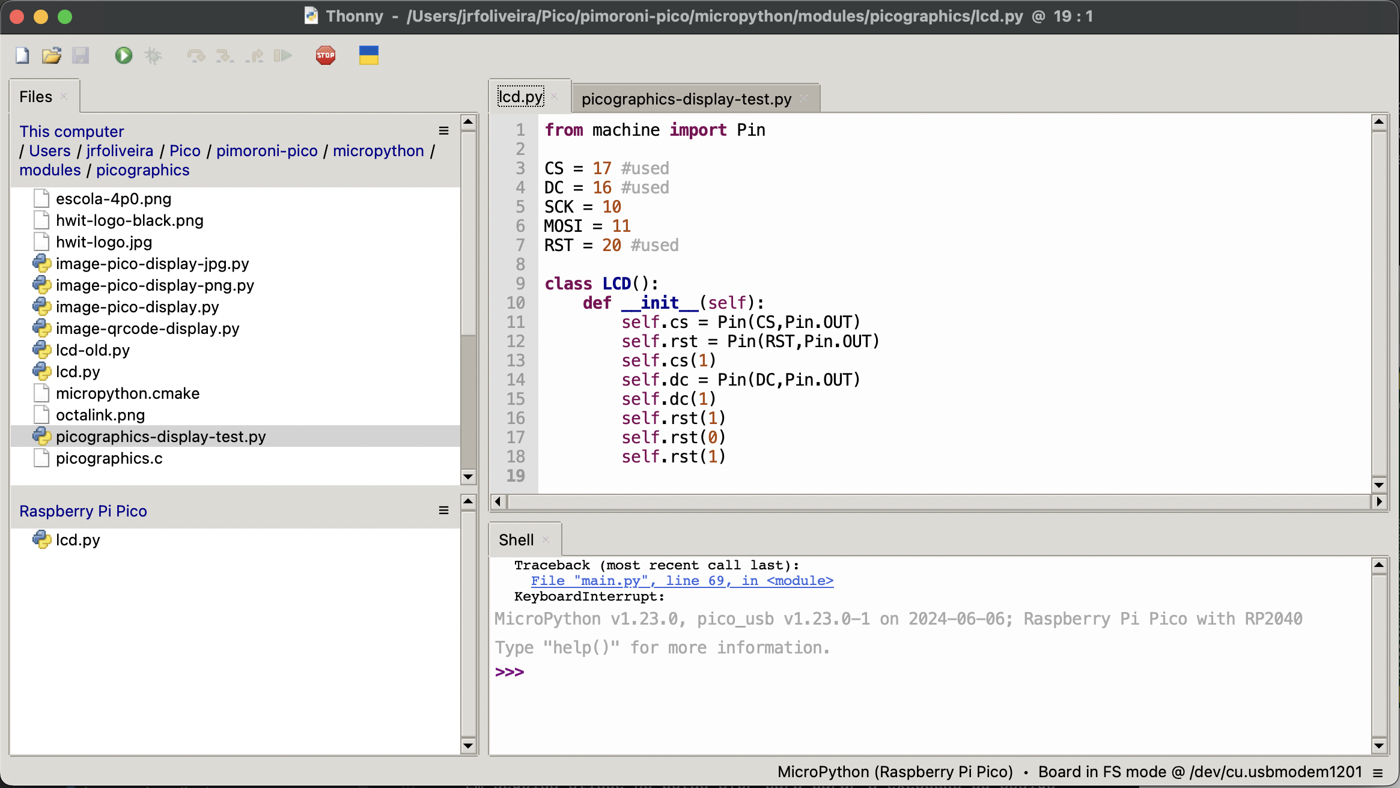
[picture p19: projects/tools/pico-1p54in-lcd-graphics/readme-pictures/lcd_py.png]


Pronto, agora você pode usar os exemplos abaixo para testar como enviar imagens para o display.

## Exemplo 1: PicoGraphics Bouncing Balls (Bolas Saltitantes)

O exemplo picographics-display-test.py basicamente utiliza bibliotecas para criar 100 bolas randômicas tanto em posição quanto em raio na tela, e realizar a animação das mesmas saltitando e mudando de direção ao chocarem-se com as bordas da tela.

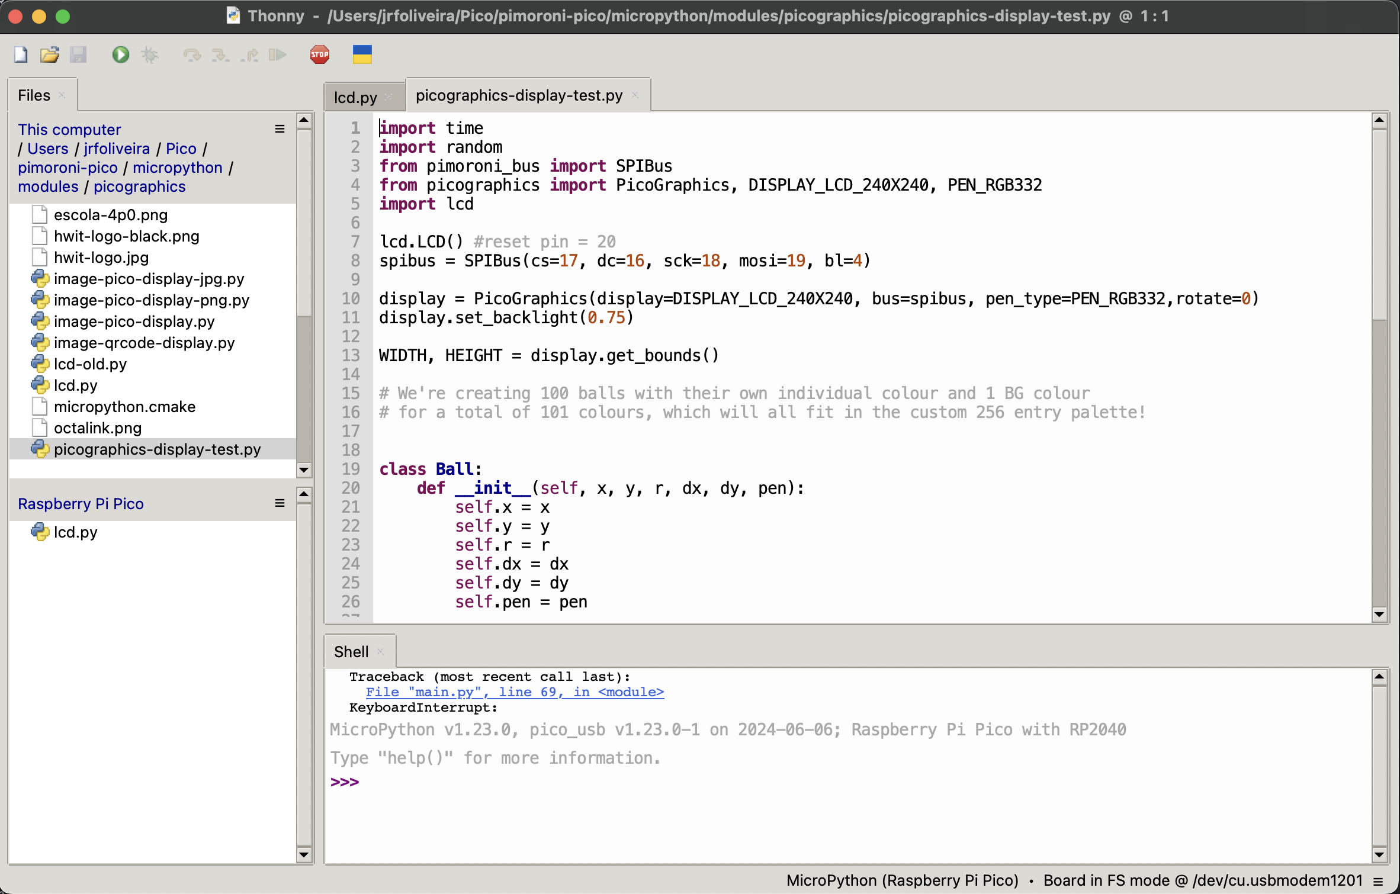
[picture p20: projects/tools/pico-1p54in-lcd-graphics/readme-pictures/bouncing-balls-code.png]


O código inicia com o carregamento das bibliotecas (time, random, SPIBus, PicoGraphics com definição do display usado + tipo de paleta RGB de 8-bits para economizar memoria do framebuffer, e a biblioteca de inicialização do lcd genérico).

```python
import time
import random
from pimoroni_bus import SPIBus
from picographics import PicoGraphics, DISPLAY_LCD_240X240, PEN_RGB332
import lcd
```

Em seguida inicializamos o LCD genérico (basicamente estabelecemos níveis não ativos nos pinos CS e DC, seguido de um pulso de reset RST no LCD), configuramos o barramento SPI (cs=17, dc=16, sck=18, mosi=19, bl=4), inicializamos a biblioteca PicoGraphics com as configurações do nosso display (DISPLAY_LCD_240X240 = 240x240 pixels, PEN_RGB332 = paleta de cores de 8 bits visando economizar memoria da pi pico, sendo 3 bits Red, 3 bits Green e 2 Bits Blue), finalizando com o ajuste do backlight em 75% (0.75, da faixa de 0.0 a 1.0) e leitura dos limites do nosso display (WIDTH, HEIGHT).

```python
lcd.LCD() #reset pin = 20
spibus = SPIBus(cs=17, dc=16, sck=18, mosi=19, bl=4)

display = PicoGraphics(display=DISPLAY_LCD_240X240, bus=spibus, pen_type=PEN_RGB332,rotate=0)
display.set_backlight(0.75)

WIDTH, HEIGHT = display.get_bounds()
```

Em seguida o trecho de código abaixo realiza um loop criando a classe e gerando lógicamente as 100 bolas (Ball: posição x, posição y, raio, velocidade x e velocidade y, cor), considerando posições, raios e cores randômicas, dentro dos limites do nosso LCD, seguindo da definição da cor do background (BG) por meio da função create_pen.

```python
class Ball:
    def __init__(self, x, y, r, dx, dy, pen):
        self.x = x
        self.y = y
        self.r = r
        self.dx = dx
        self.dy = dy
        self.pen = pen

# initialise shapes
balls = []
for i in range(0, 100):
    r = random.randint(0, 10) + 3
    balls.append(
        Ball(
            random.randint(r, r + (WIDTH - 2 * r)),
            random.randint(r, r + (HEIGHT - 2 * r)),
            r,
            (14 - r) / 2,
            (14 - r) / 2,
            display.create_pen(random.randint(0, 255), random.randint(0, 255), random.randint(0, 255)),
        )
    )
BG = display.create_pen(0, 0, 0)
```

Para concluir temos o loop principal que seta a cor do background, e realiza o loop de animação com o dicionário das bolas lógicas criadas anteriormente, ajustando a nova posiçào da bola e desenhando todas por meio da função circle, note que temos dois condicionantes que checam se a bola atingiu a borda do nosso LCD, se isso ocorrer, a velocidade é invertida, gerando o evento de bounce (salto) na borda do LCD. O sleep de 10 ms é inserido para desacelerar a animação e tornar mais agradável para visualização (FPS máximo = 100).

```python
while True:
    display.set_pen(BG)
    display.clear()

    for ball in balls:
        ball.x += ball.dx
        ball.y += ball.dy

        xmax = WIDTH - ball.r
        xmin = ball.r
        ymax = HEIGHT - ball.r
        ymin = ball.r

        if ball.x < xmin or ball.x > xmax:
            ball.dx *= -1

        if ball.y < ymin or ball.y > ymax:
            ball.dy *= -1

        display.set_pen(ball.pen)
        display.circle(int(ball.x), int(ball.y), int(ball.r))

    display.update()
    time.sleep(0.01)
```

Segue a baixo um vídeo demonstrando a aplicação no youtube. 

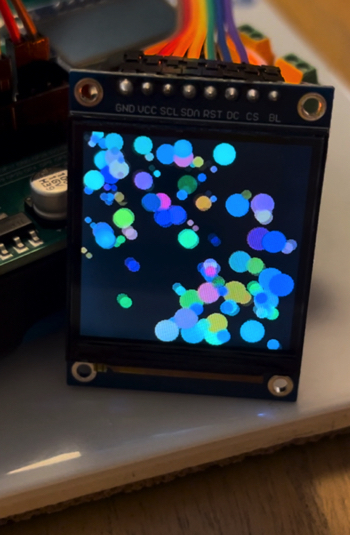
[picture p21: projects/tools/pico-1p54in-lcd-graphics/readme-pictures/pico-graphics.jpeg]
IMAGE ALT TEXT HERE (https://www.youtube.com/shorts/nRjf7dAn3zw)


## Exemplo 2: Gerador e display de código QR

Esse exemplo visa gerar qr-codes e mostrar no display de LCD para aplicações de comunicação visual com reconhecimento da mensagem via celular.

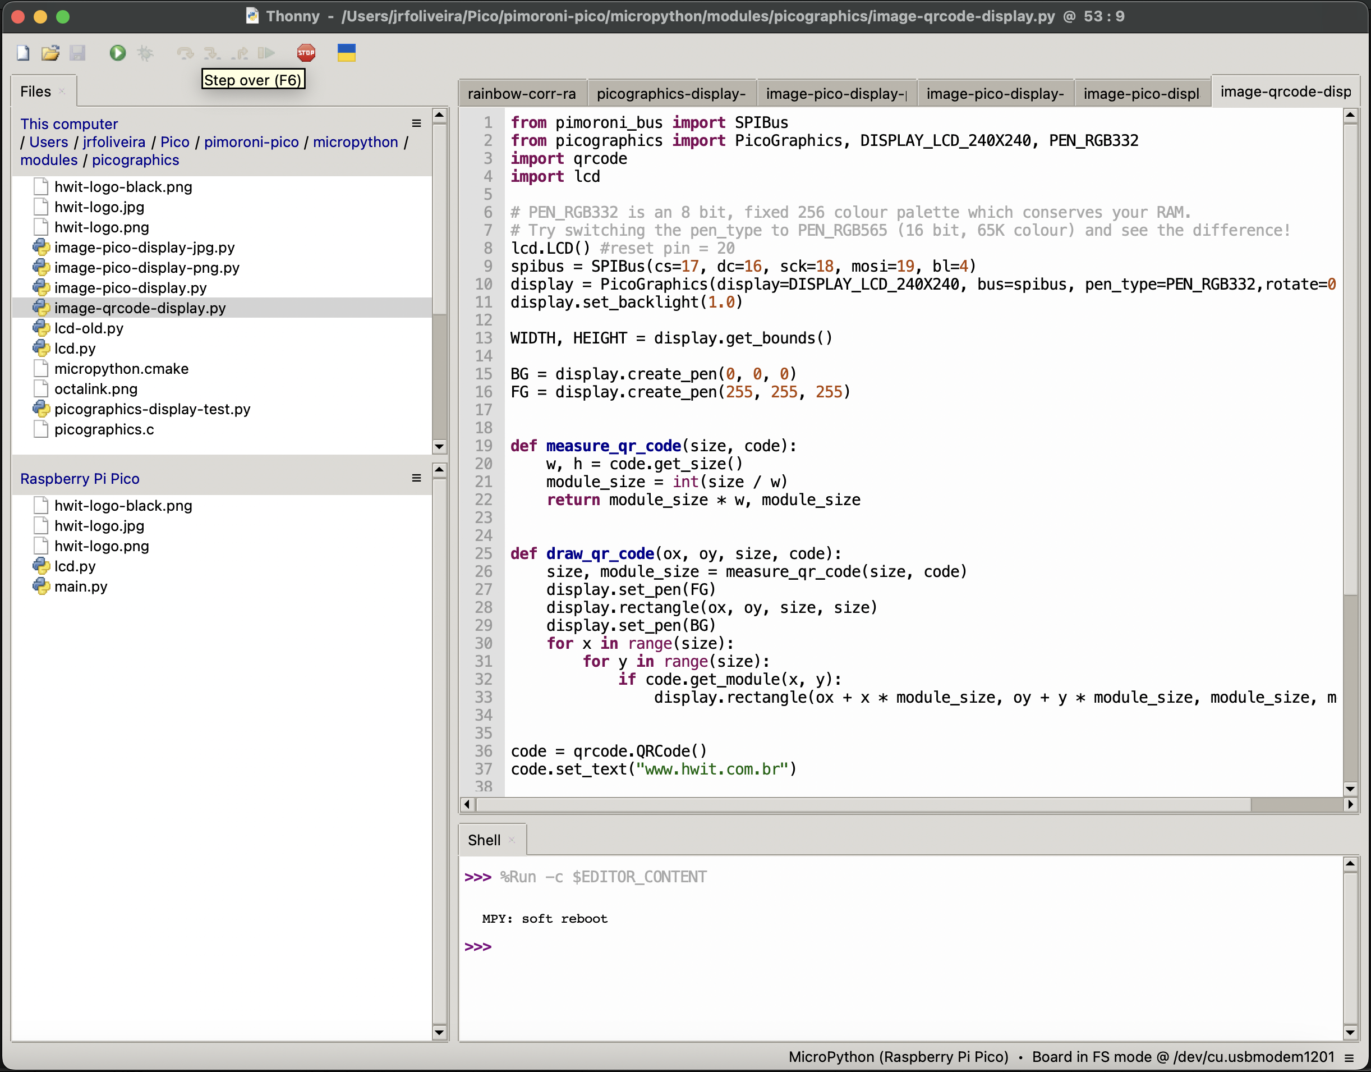
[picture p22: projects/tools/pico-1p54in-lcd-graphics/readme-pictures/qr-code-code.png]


O arquivo image-qrcode-display.py usa a biblioteca LCD para iniciar o LCD genérico que estamos usando, PicoGraphics para configurar o display/paleta de cores e rotação, ajusta o backlight (1.0 = máximo brilho), cria um background preto e foreground branco e define duas funções que medem o qrcode via função _measure_qr_code_ versus o tamanho da tela (retornando medida escalonada), e a função _draw_qr_code_ que pega os pontos e top e left (inicio da imagem a ser desenhada no lcd) e desenha o qr-code no LCD de forma escalonada.

```python
from pimoroni_bus import SPIBus
from picographics import PicoGraphics, DISPLAY_LCD_240X240, PEN_RGB332
import qrcode
import lcd

# PEN_RGB332 is an 8 bit, fixed 256 colour palette which conserves your RAM.
# Try switching the pen_type to PEN_RGB565 (16 bit, 65K colour) and see the difference!
lcd.LCD() #reset pin = 20
spibus = SPIBus(cs=17, dc=16, sck=18, mosi=19, bl=4)
display = PicoGraphics(display=DISPLAY_LCD_240X240, bus=spibus, pen_type=PEN_RGB332,rotate=0)
display.set_backlight(1.0)

WIDTH, HEIGHT = display.get_bounds()

BG = display.create_pen(0, 0, 0)
FG = display.create_pen(255, 255, 255)

def measure_qr_code(size, code):
    w, h = code.get_size()
    module_size = int(size / w)
    return module_size * w, module_size

def draw_qr_code(ox, oy, size, code):
    size, module_size = measure_qr_code(size, code)
    display.set_pen(FG)
    display.rectangle(ox, oy, size, size)
    display.set_pen(BG)
    for x in range(size):
        for y in range(size):
            if code.get_module(x, y):
                display.rectangle(ox + x * module_size, oy + y * module_size, module_size, module_size)
                
code = qrcode.QRCode()
code.set_text("www.hwit.com.br")

display.set_pen(FG)
display.clear()
display.set_pen(BG)

max_size = min(WIDTH, HEIGHT)

size, module_size = measure_qr_code(max_size, code)
left = int((WIDTH // 2) - (size // 2))
top = int((HEIGHT // 2) - (size // 2))
draw_qr_code(left, top, max_size, code)

display.update()

while True:
    pass
```

Em seguida o código cria um qrcode apontando para uma string qualquer, nesse caso colocamos uma string indicando para um site na world wide web.

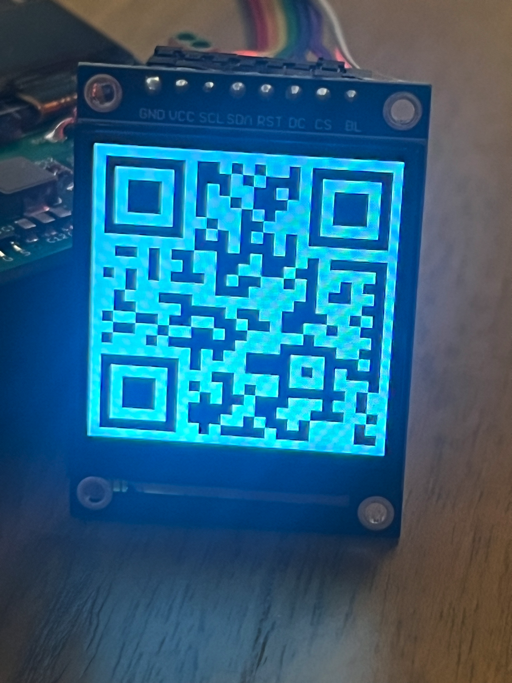
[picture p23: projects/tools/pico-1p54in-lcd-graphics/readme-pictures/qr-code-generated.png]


No caso de um endereço de site o mesmo será reconhecido visualmente por câmeras de celulares android/apple podendo ser aberto diretamente em browse de celulares ou tablets.

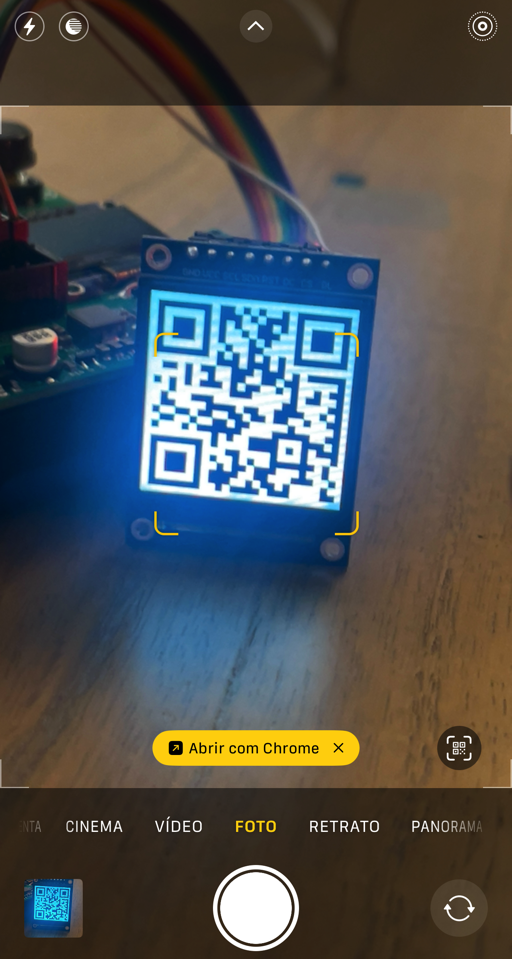
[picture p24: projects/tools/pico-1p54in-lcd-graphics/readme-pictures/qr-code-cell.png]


## Exemplo 3: Display imagens JPG e PNG

Para mostrar imagens JPG e/ou PNG é necessário primeiramente processar a imagem alvo a ser mostrada no display LCD.

Isso pode ser realizado com qualquer processador de imagens, abaixo segue como realizar o processo com o Paint do Windows 11.

Primeiramente abra a imagem alvo de ser processada, selecione toda a imagem com ctrl+a.

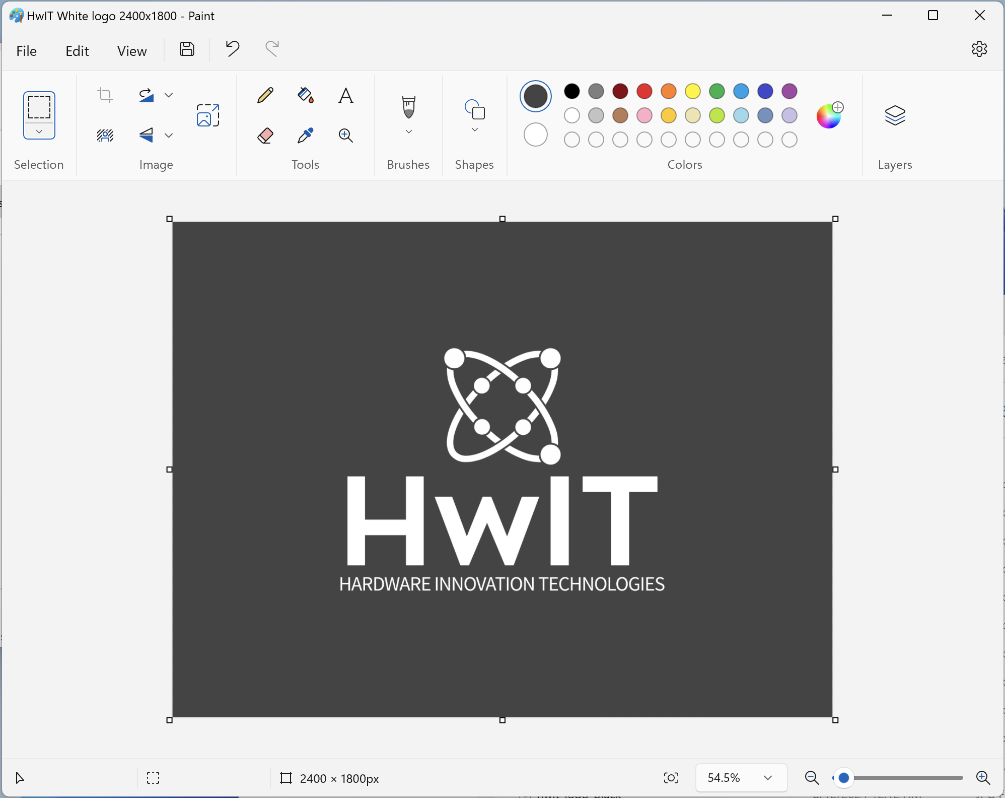
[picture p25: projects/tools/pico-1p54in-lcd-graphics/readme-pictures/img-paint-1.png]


Reposicione relativo ao canto extremo esquerdo, e busque mudar o tamanho da imagem (clique nos limites da mesma e redimensionando manualmente) com objetivo de obter dimensões iguais em x e y (imagem quadrada, tal como nosso LCD).

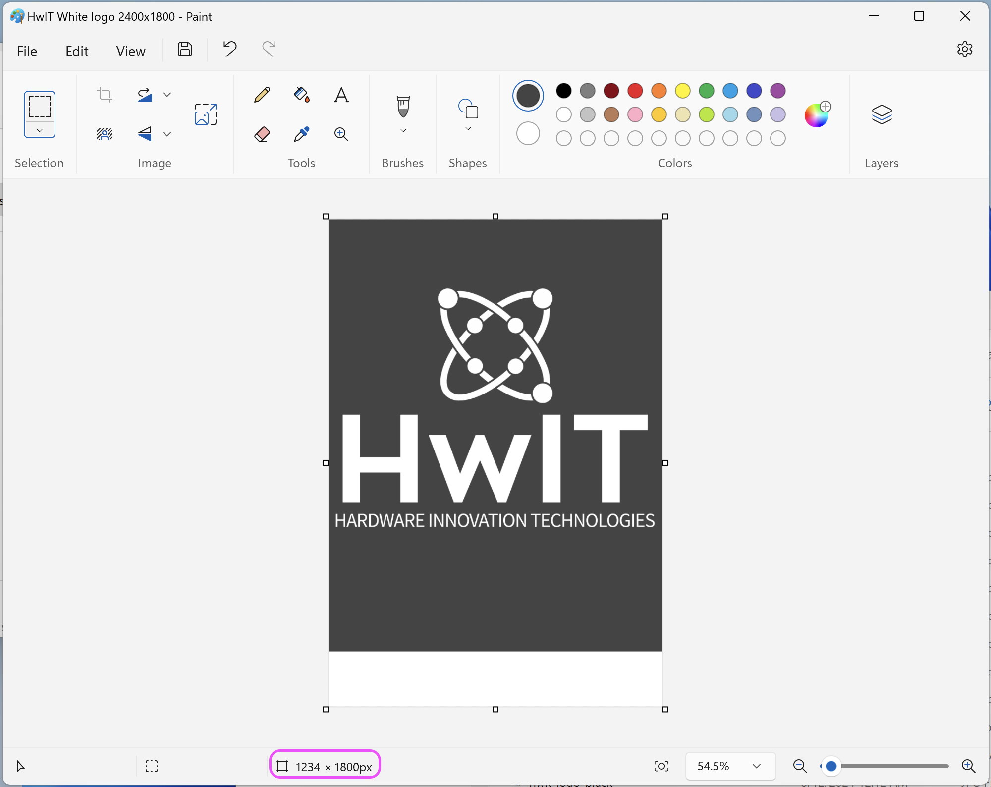
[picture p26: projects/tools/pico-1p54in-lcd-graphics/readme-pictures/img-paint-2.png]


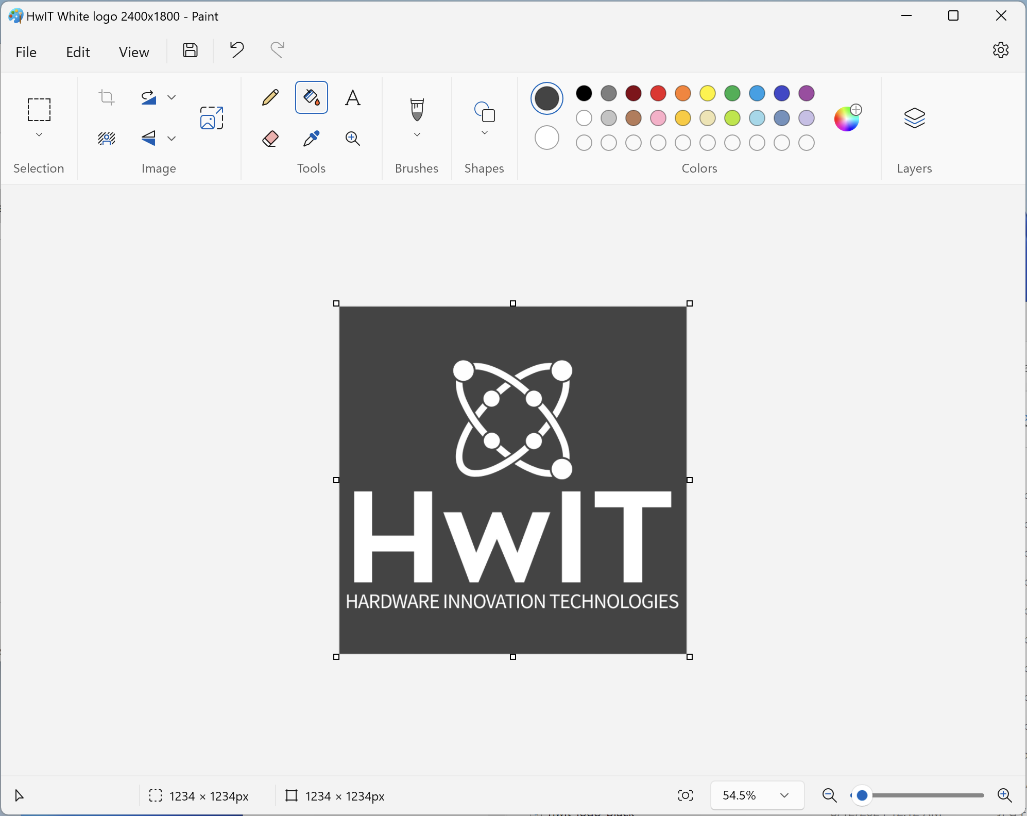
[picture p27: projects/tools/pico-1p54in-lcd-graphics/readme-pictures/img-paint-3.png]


Após conseguir ajustar a imagem em um tamanho quadrado, clique como marcado na ilustração abaixo em redimensionamento de imagem (resize and skew).

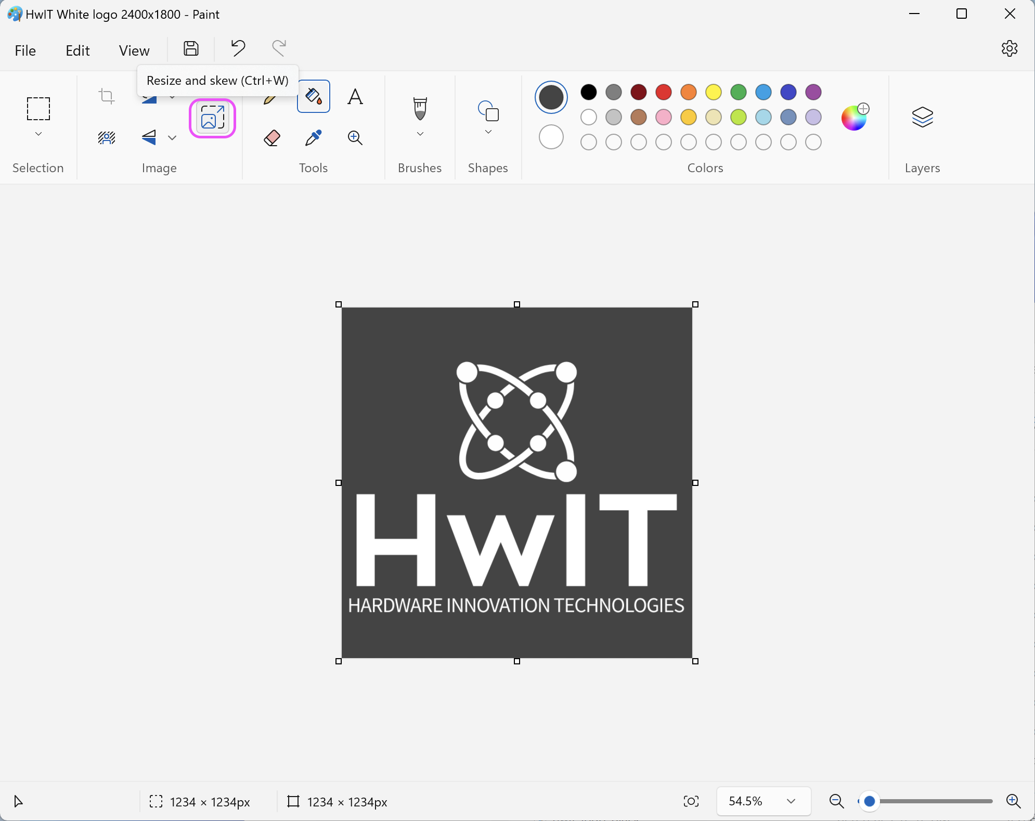
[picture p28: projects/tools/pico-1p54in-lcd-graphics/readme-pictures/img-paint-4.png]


Selecione o resize em pixels e coloque o tamanho igual a nosso display (240x240).

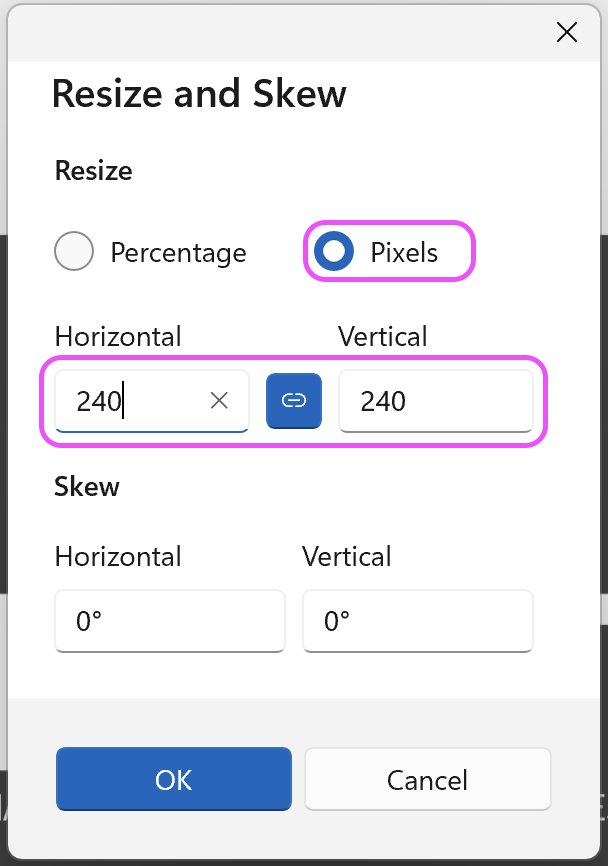
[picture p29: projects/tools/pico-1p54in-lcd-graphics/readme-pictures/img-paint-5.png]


Após redimensionamento, salve a figura como desejar, JPEG ou PNG como ilustrado abaixo no menu arquivo (file). Salve de preferência na mesma pasta onde o thonny visualiza o arquivo do código deste exemplo qr-code.

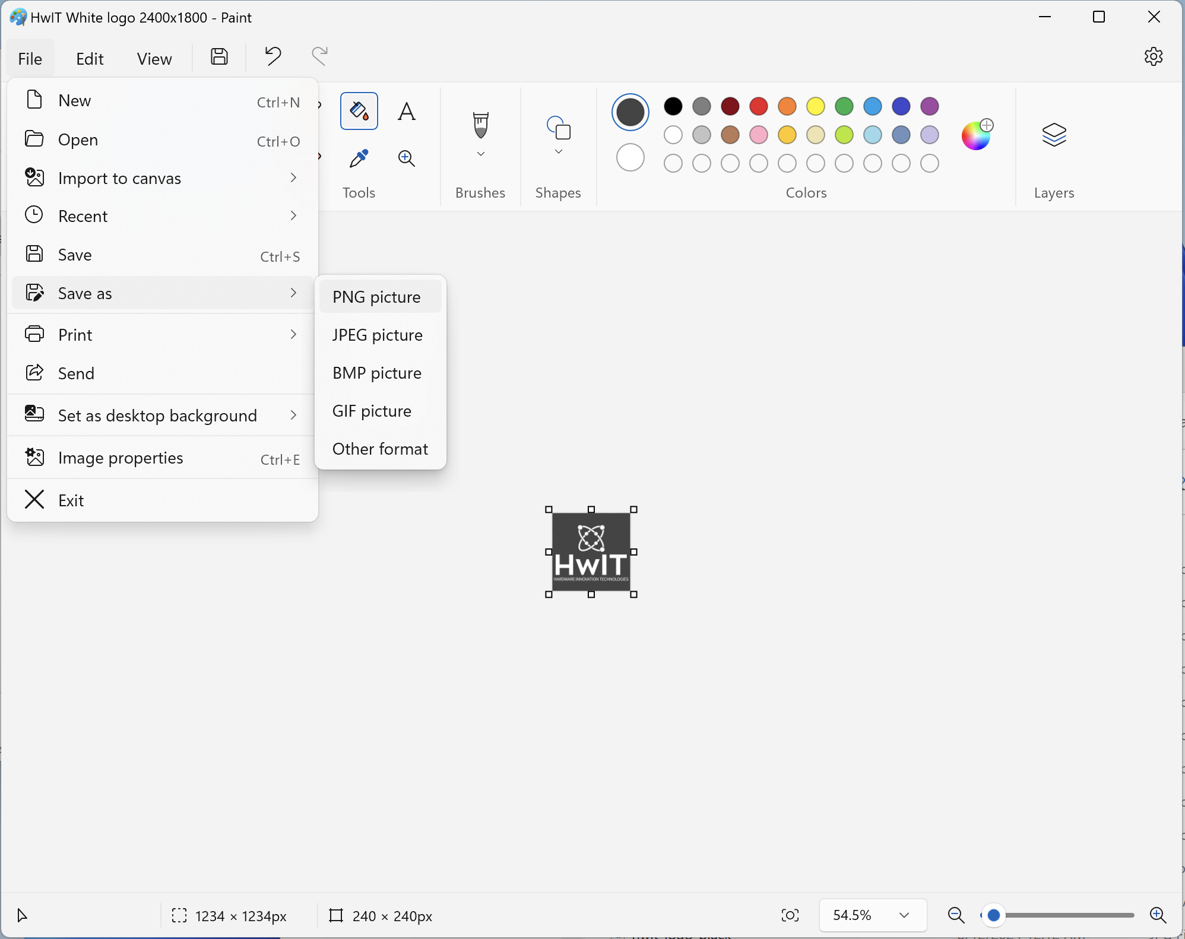
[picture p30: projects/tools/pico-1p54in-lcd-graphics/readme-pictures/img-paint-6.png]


Em seguida use o Thonny para fazer upload da imagem como ilustrado abaixo (clique no botão direito no arquivo _hwit-logo.jpg_ e seleção da _opção Upload to /_).





### Display imagem JPEG

Para mostrar imagens jpeg no display (extensão jpg), devemos fazer o upload da imagem referente com resolução 240x240 pixels na raspberry pi pico da bitdoglab via thonny como mostrado acima, em seguida basta usar o código abaixo indicando o nome da imagem salva corretamente.

O código basicamente importa as bibliotecas SPIBus e PicoGraphics considerando o display 240x240 e paleta de cores RGB332 (3 bits vermelho, 3 bits verde e 2 bits azul), bilbioteca de decodificação de JPEG (jpegdec) e nossa biblioteca de reset do lcd genérico que estamos usando.

Em seguida basicamente resetamos o lcd, criamos o barramento SPI indicando os pinos do nosso LCD conectado na bitdoglab, criamos o display com a biblioteca picographics, e setamos 75% do backlight.

```python
from pimoroni_bus import SPIBus
from picographics import PicoGraphics, DISPLAY_LCD_240X240, PEN_RGB332
import jpegdec
import lcd

# PEN_RGB332 is an 8 bit, fixed 256 colour palette which conserves your RAM.
# Try switching the pen_type to PEN_RGB565 (16 bit, 65K colour) and see the difference!
lcd.LCD() #reset pin = 20
spibus = SPIBus(cs=17, dc=16, sck=18, mosi=19, bl=4)

display = PicoGraphics(display=DISPLAY_LCD_240X240, bus=spibus, pen_type=PEN_RGB332,rotate=0)
display.set_backlight(0.75)

# Create a new JPEG decoder for our PicoGraphics
j = jpegdec.JPEG(display)

# Open the JPEG file
j.open_file("hwit-logo.jpg")

# Decode the JPEG
j.decode(0, 0, jpegdec.JPEG_SCALE_FULL)

# Display the result
display.update()
```

Para decodificar a figura JPEG criamos um objeto j e passamos o objeto display como monitor alvo, então abrimos o arquivo via método open_file do objeto j, executamos a decodificação do jpeg chamando o método decode do objeto j indicando o ponto inicial como o a coordenada 0,0 (canto esquerdo superior) do LCD, em seguida atualizamos o display com a imagem decodificada via método update do objeto display.

Segue a imagem base para demo abaixo.



Segue a imagem no lcd abaixo.



### Display imagem PNG

Para mostrar imagens PNG no display (extensão png), o processo é muito semelhando ao do jpeg mostrado anteriormente, onde devemos fazer o upload da imagem referente com resolução 240x240 pixels na raspberry pi pico da bitdoglab via thonny como mostrado acima, em seguida basta usar o código abaixo indicando o nome da imagem salva corretamente.

O código basicamente importa as bibliotecas SPIBus e PicoGraphics considerando o display 240x240 e paleta de cores RGB332 (3 bits vermelho, 3 bits verde e 2 bits azul), bilbioteca de decodificação de PNG (pngdec) e nossa biblioteca de reset do lcd genérico que estamos usando.

Em seguida basicamente resetamos o lcd, criamos o barramento SPI indicando os pinos do nosso LCD conectado na bitdoglab, criamos o display com a biblioteca picographics, e setamos 100% do backlight (brilho máximo).

```python
from pimoroni_bus import SPIBus
from picographics import PicoGraphics, DISPLAY_LCD_240X240, PEN_RGB332
from pngdec import PNG
import lcd

# PEN_RGB332 is an 8 bit, fixed 256 colour palette which conserves your RAM.
# Try switching the pen_type to PEN_RGB565 (16 bit, 65K colour) and see the difference!
lcd.LCD() #reset pin = 20
spibus = SPIBus(cs=17, dc=16, sck=18, mosi=19, bl=4)

display = PicoGraphics(display=DISPLAY_LCD_240X240, bus=spibus, pen_type=PEN_RGB332,rotate=0)
display.set_backlight(1.0)

png = PNG(display)
png.open_file("escola-4p0.png")
png.decode(0, 0)

# Display the result
display.update()
```

Para decodificar a figura PNG criamos um objeto png e passamos o objeto display como monitor alvo, então abrimos o arquivo via método open_file do objeto png com o endereço da imagem alvo a ser mostrada, executamos a decodificação do jpeg chamando o método decode do objeto png indicando o ponto inicial como o a coordenada 0,0 (canto esquerdo superior) do LCD, em seguida atualizamos o display com a imagem decodificada via método update do objeto display.

Segue a imagem base para demo abaixo.



Segue a imagem no lcd abaixo.



**... a ser documentado ...**

## Exemplo 4: Faixa de cores

...

## Exemplo 5: Fundo de tela arco-iris em degrade

...

## Exemplo 6: Arco-iris degrade com uso reduzido de memoria

...

## Exemplo 7: Display de gráfico de temperatura

...

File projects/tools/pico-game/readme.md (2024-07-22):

# BitDogLab Pico Retro Game



Torne sua BitDogLab em uma ferramenta de desenvolvimento de jogos de video game. 

:warning: Caso queria somente carregar o firmware direto na bitdoglab com todos os arquivos do pico-game já embarcados, execute os passos do [manual de gravação de firwmare](https://github.com/BitDogLab/BitDogLab/tree/main/doc#grava%C3%A7%C3%A3o-do-firmware) e grave o firmware contido [na pasta build](https://github.com/BitDogLab/BitDogLab/blob/main/softwares/pico-game/build/) listado abaixo (raspberry pi pico ou raspberry pi pico W) :warning:

- Raspberry Pi Pico game firmware: [pico-game-rpi-pico.uf2](https://github.com/BitDogLab/BitDogLab/blob/main/softwares/pico-game/build/pico-game-rpi-pico.uf2)
- Raspberry Pi Pico W game firmware: [pico-game-w.uf2](https://github.com/BitDogLab/BitDogLab/blob/main/softwares/pico-game/build/pico-game-w.uf2)

Adaptamos os controles da BitDogLab (joystick analógico, botões e buzzer) e portamos alguns jogos (código fonte disponível nesse repositório) listados abaixo:



- PicoPong.py: Um jogo simples do tipo Pong
- PicoInvaders.py: A simplified Space Invaders game
     - PicoInvadersPnp: Space Invaders por Print N'Play ([código fonte original](https://github.com/printnplay/Pico-MicroPython))
- PicoSnake.py: Jogo da cobra feitor por Twan37 ([código fonte original](https://github.com/Twan37/PicoSnake))
- PicoDino.py: Jogo do dinossauro (parecido com o do google chrome quando está sem internet) por tyrkelko
- Pico2048.py: Jogo 2048 feito por tyrkelko
- PicoTetris.py: Jogo clone de tetris feito por tyrkelko
- PicoFullSpeed.py: Jogo de corrida de moto feito por Kuba & Stepan ([código fonte original](https://github.com/Hellmole/Raspberry-pi-pico-games))
- PicoLunarModule.py: Jogo de pouso de capsula lunar feitor por Kuba & Stepan ([código fonte original](https://github.com/Hellmole/Raspberry-pi-pico-games))
- PicoGame.py: Uma classe facil de usar para escrever jogos para Raspberry Pi Pico RetroGaming System (usado por alguns games listados acima)
ss1306py.py: Driver oficial em MicroPython do OLED display SSD1306 (interfaces I2C e SPI)

Fonte base da maioria dos games portados para o bitdoglab: [Raspberry Pi Pico RetroGaming System](https://github.com/YouMakeTech/PicoRetroGamingSystem)

O porte do controle, botões e buzzer foi feito por [Juliano Oliveira](https://github.com/jrfo-hwit)

Antes de começar a executar o tutorial sugiro passar antes pelo [manual do BitDogLab](https://github.com/BitDogLab/BitDogLab/tree/main/doc) que vai te ajudar a entender como montar a placa e preparar a mesma para receber os códigos em microphyton dos jogos portados nesse repositório.

## Como carregar os jogos

Após ter lido o [manual do BitDogLab](https://github.com/BitDogLab/BitDogLab/tree/main/doc), montado e carregado o firmware micropython na raspberry pi pico da BitDogLab, abra a IDE Thonny, e conecte-se a sua Pi Pico clicando no canto extremo inferior direito, e selecionando sua placa como ilustrado abaixo.



Em seguida clique no botão STOP para parar a execução do código atual e reiniciar o backend como ilustrado abaixo.



Identifique que a placa entrou no modo onde você poderá carregar arquivos e códigos quando a mesma apresentar no "Shell" a mensagem "MPY: soft reboot" e você conseguir visualizar no canto inferior esquerdo os arquivos presentes em sua Pi Pico, como ilustrado abaixo.



Agora comece a criar as pastas onde vamos por os arquivos de suporte aos jogos que estamos carregando na BitDogLab "DinoGame", "P2048", "TetrisGame", clicando no ambiente de arquivos da sua Pi Pico e selecionando "new directory" como indicado abaixo.



Insira o nome do diretório (exemplo "DinoGame"), e clique em "OK" como ilustrado abaixo.



Abra os arquivos que vão ser salvos na pasta "DinoGame" (Bird.py, Cactus.py, Dino.py, Dirt.py e Resources.py) clique no primeiro a ser salvo (Bird.py) e clique no menu arquivo (File) - salvar como (Save as), como ilustrado abaixo.



Selecione para savar na sua Pi Pico como ilustrado abaixo.



Em seguida seleciona a pasta alvo a ser salvo o arquivo (pasta DinoGame), como ilustrado abaixo.



Digite o nome do arquivo a ser salvo na pasta (Bird.py) como ilustrado abaixo.



Em seguida repita os passos anteriores para salvar o restante dos arquivos na pasta DinoGame (Cactus.py, Dino.py, Dirt.py e Resources.py), e execute os mesmos passos para salvar os arquivos nas pastas "P2048" (Logic.py e Resources.py), "TetrisGame" (Logic.py e Resources.py), até que a estrutura de arquivos de suporte esteja na sua Pi Pico como ilustrado abaixo.



Agora abra apenas os arquivos principais dos jogos com o objetivo de salva-los direto na Pi Pico (main.py, P2048.py, PicoDino.py, PicoFullSpeed.py, PicoGame.py, PicoInvaders.py, PicoLunarModule.py, PicoPong.py, PicoSnake.py, PicoTetris.py, ssd1306.py), e vá realizando os memsos passos anteriores para salvar cada arquivo direto na Pi Pico, como ilustrado abaixo.



Em seguida quando, todos os arquivos estiverem carregados, sua estrutura de arquivos na Pi Pico da BitDogLab deve estar como ilustrado abaixo (dentro da caixa verde).



Em seguida basta selecionar o arquivo main.py e executar o botão Run para rodar o código.



### Se divirta e fique a vontade para programar jogos analisando e evoluindo os códigos fontes desse repositório

Video Youtube

IMAGE ALT TEXT HERE (https://www.youtube.com/watch?v=d3d3uuJCRDc)

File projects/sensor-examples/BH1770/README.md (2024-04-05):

# BH1750
Micropython module for BH1750 ambient light sensor.

Just connect your BH1750 board to Arduino, ESP or any other board with MicroPython firmware.

Supply voltage BH1750 3.3 or 5.0 volts! Use four wires to connect (I2C).
1. +VCC (Supply voltage)
2. GND
3. SDA
4. SCL

Upload micropython firmware to the NANO(ESP, etc) board, and then four *.py files: main.py, bh1750.py,
bus_service.py, base_sensor.py. 
Then open main.py in your IDE and run it.

# Pictures
## IDE

## Breadboard


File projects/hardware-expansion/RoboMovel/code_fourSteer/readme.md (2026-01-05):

Codigo de teste FourSteer <br>
Passado de Arthur para Vinicius em 26nov2025 <br>
Este codigo é para BitDogLab conectada ao módulo i2c-pwm pca9685. Serve para testar comandos de movimentação dos servos SG90 e motores tt. <br>
Código criado por Arthur Pereira Sousa Andrade durante seu TCC orientado pro Fabiano Fruett e coorientado por Vinicius Emanoel Ares. <br>
Video de apresentacao final: <br>
https://eduplay.rnp.br/app/video/368232

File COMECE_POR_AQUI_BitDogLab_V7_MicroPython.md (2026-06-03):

# COMECE POR AQUI: BitDogLab v7 com MicroPython

[Português](#português) | [English](#english)

## Português

**Table of Contents**

- [COMECE POR AQUI: BitDogLab v7 com MicroPython](#comece-por-aqui-bitdoglab-v7-com-micropython)
  - [Objetivo](#objetivo)
  - [Antes de começar](#antes-de-começar)
  - [Instalando a Thonny IDE](#instalando-a-thonny-ide)
  - [Configurando o interpretador MicroPython](#configurando-o-interpretador-micropython)
  - [Gravação do firmware](#gravação-do-firmware)
  - [Alternativas de gravação de firmware](#alternativas-de-gravação-de-firmware)
  - [Executando o primeiro teste da placa](#executando-o-primeiro-teste-da-placa)
  - [Salvando o código como main.py](#salvando-o-código-como-mainpy)
  - [O que observar durante o teste](#o-que-observar-durante-o-teste)

## Objetivo

Este guia apresenta o fluxo inicial para começar a usar a **BitDogLab v7** com **MicroPython** e a **Thonny IDE**.

Ao final deste procedimento, a placa estará pronta para receber códigos Python. O primeiro teste recomendado é copiar o código de verificação geral dos periféricos, colar na Thonny IDE e salvar na placa com o nome `main.py`.

Neste repositório, o código de teste está em:

```text
testar_perifericos_gerais.py
```

Esse arquivo funciona como o teste geral de periféricos da BitDogLab v7.

## Antes de começar

Você vai precisar de:

- uma placa BitDogLab v7;
- um cabo USB compatível com a Raspberry Pi Pico/Pico W/Pico 2 usada na placa;
- um computador com Windows, Linux ou macOS;
- a Thonny IDE instalada;
- o arquivo de teste geral dos periféricos.

Antes de instalar o firmware, localize o botão `BOOTSEL` da Raspberry Pi Pico/Pico W/Pico 2 instalada na BitDogLab.



O botão `BOOTSEL` é usado para colocar a placa em modo de gravação de firmware. Para executar programas normalmente, conecte a placa sem pressionar esse botão.

## Instalando a Thonny IDE

Para programar a BitDogLab com MicroPython, o primeiro passo é instalar a Thonny IDE. Ela é o ambiente onde escrevemos, salvamos e executamos o código na placa.

Acesse a página oficial:

https://thonny.org/

Em seguida, escolha a opção correta para o seu sistema operacional.

Windows:



Mac:



Linux:



Com o arquivo baixado, instale a Thonny IDE seguindo os passos do instalador. Assim que a instalação for concluída, abra a IDE.

## Configurando o interpretador MicroPython

A configuração principal da Thonny é a escolha do interpretador usado para executar os códigos.

Na Thonny IDE, acesse:

```text
Tools > Options
```



Na janela de configurações, acesse a aba `Interpreter` e selecione:

```text
MicroPython (Raspberry Pi Pico)
```



A porta serial da placa normalmente é detectada automaticamente pela Thonny. Se houver mais de uma placa conectada, selecione manualmente a porta correspondente à BitDogLab.

## Gravação do firmware

Com a Thonny configurada, é necessário gravar o firmware MicroPython na placa.

Para isso:

1. Desconecte a BitDogLab do computador.
2. Pressione e segure o botão `BOOTSEL`.
3. Mantendo o botão pressionado, conecte o cabo USB ao computador.
4. Depois que a placa for reconhecida, solte o botão.





Esse procedimento faz com que a placa entre em modo de gravação de firmware. O computador deve reconhecê-la como um disco removível chamado `RPI-RP2`.



Com a placa em modo bootloader, volte à aba `Interpreter` da Thonny. A janela deve mostrar a opção para instalar ou atualizar o firmware.



Clique em:

```text
Install or update firmware
```

Na janela seguinte, confira se o dispositivo selecionado é a Raspberry Pi Pico/Pico W/Pico 2 correta.



Em seguida, instale a versão desejada do MicroPython.



Aguarde até que a instalação termine. Ao final, feche a janela de instalação, desconecte a placa e conecte novamente sem pressionar `BOOTSEL`.

Agora a BitDogLab está pronta para receber códigos Python.

## Alternativas de gravação de firmware

Também é possível gravar o firmware manualmente por drag-and-drop.

Nesse método, a placa deve estar em modo bootloader e aparecer como disco `RPI-RP2`. Depois, basta copiar o arquivo `.uf2` do firmware para esse disco.

Firmware oficial MicroPython:

- Raspberry Pi Pico: https://micropython.org/download/RPI_PICO/
- Raspberry Pi Pico W: https://micropython.org/download/RPI_PICO_W/

## Executando o primeiro teste da placa

Com a configuração finalizada e o firmware MicroPython instalado, o próximo passo é executar o teste geral dos periféricos.

Abra o arquivo:

```text
testar_perifericos_gerais.py
```

Copie todo o conteúdo do arquivo e cole na área principal da Thonny IDE.



Esse teste foi pensado para validar, em sequência, os principais recursos da BitDogLab v7, incluindo:

- LED RGB;
- matriz de LEDs RGB 5x5;
- botões A e B;
- botão do joystick;
- joystick analógico;
- buzzer;
- display OLED;
- microfone.

## Salvando o código como main.py

Para que a placa execute o teste automaticamente, salve o código na memória da Raspberry Pi Pico/Pico W/Pico 2 com o nome `main.py`.

Na Thonny, clique em:

```text
File > Save as...
```

Escolha salvar no dispositivo:

```text
Raspberry Pi Pico
```



Na janela de nome do arquivo, digite:

```text
main.py
```



Depois de salvar, confira se o arquivo aparece na lista de arquivos da placa.



O nome `main.py` é importante porque o MicroPython executa automaticamente esse arquivo quando a placa inicia.

## Executando o código

Com o arquivo salvo na placa, pressione o botão `Run` da Thonny para executar o código.



Se o arquivo foi salvo como `main.py`, a BitDogLab também executará esse teste automaticamente sempre que for ligada ou reiniciada.

## O que observar durante o teste

Durante a execução, observe se:

- a matriz de LEDs exibe animações;
- o LED RGB muda de cor;
- o display OLED mostra mensagens;
- o buzzer emite sons;
- os botões A e B respondem quando pressionados;
- o joystick altera o comportamento esperado;
- o botão do joystick responde;
- o microfone altera a visualização de intensidade sonora.

Se algo não funcionar, confira:

- se a placa correta está selecionada na Thonny;
- se o firmware MicroPython foi instalado corretamente;
- se a placa foi reconectada sem pressionar `BOOTSEL`;
- se o arquivo foi salvo exatamente como `main.py`;
- se as bibliotecas necessárias, como `ssd1306.py` e `neopixel.py`, estão disponíveis na placa.

As bibliotecas reutilizáveis do repositório estão organizadas em:

```text
libs_software/
```

Depois de validar a placa com esse teste geral, o próximo passo é estudar exemplos menores e isolados em:

```text
basic-examples/
```

Essa pasta deve conter exemplos curtos, didáticos e focados em um periférico por vez.

## English

**Table of Contents**

- [Start Here: BitDogLab v7 with MicroPython](#start-here-bitdoglab-v7-with-micropython)
  - [Goal](#goal)
  - [Before You Start](#before-you-start)
  - [Installing Thonny IDE](#installing-thonny-ide)
  - [Configuring the MicroPython Interpreter](#configuring-the-micropython-interpreter)
  - [Flashing the MicroPython Firmware](#flashing-the-micropython-firmware)
  - [Alternative Firmware Flashing Method](#alternative-firmware-flashing-method)
  - [Running the First Board Test](#running-the-first-board-test)
  - [Saving the Code as main.py](#saving-the-code-as-mainpy)
  - [What to Check During the Test](#what-to-check-during-the-test)

## Start Here: BitDogLab v7 with MicroPython

This guide shows the initial workflow for using **BitDogLab v7** with **MicroPython** and the **Thonny IDE**.

At the end of this procedure, the board will be ready to receive Python code. The recommended first test is to copy the general peripheral test code, paste it into Thonny IDE, and save it on the board as `main.py`.

In this repository, the test code is:

```text
testar_perifericos_gerais.py
```

This file works as the general peripheral self-test for BitDogLab v7.

## Goal

This guide explains how to:

- install and open Thonny IDE;
- configure Thonny for MicroPython;
- put the board into bootloader mode;
- install or update MicroPython;
- copy the BitDogLab v7 peripheral test code;
- save the code on the board as `main.py`;
- run and observe the first hardware test.

## Before You Start

You will need:

- a BitDogLab v7 board;
- a USB cable compatible with the Raspberry Pi Pico/Pico W/Pico 2 used on the board;
- a Windows, Linux, or macOS computer;
- Thonny IDE installed;
- the general peripheral test file.

Before installing MicroPython, locate the `BOOTSEL` button on the Raspberry Pi Pico/Pico W/Pico 2 installed on BitDogLab.



The `BOOTSEL` button is used to put the board into firmware flashing mode. To run programs normally, connect the board without pressing this button.

## Installing Thonny IDE

To program BitDogLab with MicroPython, first install Thonny IDE. It is the environment used to write, save, and run code on the board.

Open the official page:

https://thonny.org/

Choose the correct installer for your operating system.

Windows:



Mac:



Linux:



After downloading the installer, install Thonny IDE and open it.

## Configuring the MicroPython Interpreter

In Thonny IDE, open:

```text
Tools > Options
```



In the settings window, open the `Interpreter` tab and select:

```text
MicroPython (Raspberry Pi Pico)
```



Thonny usually detects the board serial port automatically. If more than one board is connected, manually select the port that belongs to BitDogLab.

## Flashing the MicroPython Firmware

With Thonny configured, install MicroPython on the board.

1. Disconnect BitDogLab from the computer.
2. Press and hold the `BOOTSEL` button.
3. While holding the button, connect the USB cable to the computer.
4. Once the board is detected, release the button.





The computer should recognize the board as a removable drive named `RPI-RP2`.



With the board in bootloader mode, return to the `Interpreter` tab in Thonny. The window should show the option to install or update the firmware.



Click:

```text
Install or update firmware
```

Confirm that the selected device is the correct Raspberry Pi Pico/Pico W/Pico 2.



Then install the desired MicroPython version.



Wait until the installation finishes. Then close the installation window, disconnect the board, and reconnect it without pressing `BOOTSEL`.

BitDogLab is now ready to receive Python code.

## Alternative Firmware Flashing Method

You can also install firmware manually by drag-and-drop.

In this method, the board must be in bootloader mode and appear as the `RPI-RP2` drive. Then copy the `.uf2` firmware file to that drive.

Official MicroPython firmware:

- Raspberry Pi Pico: https://micropython.org/download/RPI_PICO/
- Raspberry Pi Pico W: https://micropython.org/download/RPI_PICO_W/

## Running the First Board Test

After installing MicroPython, run the general peripheral test.

Open the file:

```text
testar_perifericos_gerais.py
```

Copy the whole file and paste it into the main editor area in Thonny IDE.



This test validates the main BitDogLab v7 resources, including:

- RGB LED;
- 5x5 RGB LED matrix;
- buttons A and B;
- joystick button;
- analog joystick;
- buzzer;
- OLED display;
- microphone.

## Saving the Code as main.py

To make the board run the test automatically, save the code on the Raspberry Pi Pico/Pico W/Pico 2 memory as `main.py`.

In Thonny, click:

```text
File > Save as...
```

Choose:

```text
Raspberry Pi Pico
```



Name the file:

```text
main.py
```



After saving, check that the file appears in the board file list.



The name `main.py` is important because MicroPython automatically runs this file when the board starts.

## Running the Code

With the file saved on the board, press Thonny's `Run` button.



If the file was saved as `main.py`, BitDogLab will also run this test automatically whenever it is powered on or restarted.

## What to Check During the Test

During the test, check whether:

- the LED matrix shows animations;
- the RGB LED changes color;
- the OLED display shows messages;
- the buzzer emits sounds;
- buttons A and B respond when pressed;
- the joystick changes the expected behavior;
- the joystick button responds;
- the microphone changes the sound intensity visualization.

If something does not work, check:

- whether the correct board is selected in Thonny;
- whether MicroPython was installed correctly;
- whether the board was reconnected without pressing `BOOTSEL`;
- whether the file was saved exactly as `main.py`;
- whether required libraries such as `ssd1306.py` and `neopixel.py` are available on the board.

Reusable software libraries from this repository are organized in:

```text
libs_software/
```

After validating the board with this general test, continue with smaller isolated examples in:

```text
basic-examples/
```

This folder should contain short educational examples focused on one peripheral at a time.

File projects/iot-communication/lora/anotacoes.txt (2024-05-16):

LORA LORA - Bitdog SMD IDC
1  - GND -> GND
3  - 3v3 -> 3V3
5  - RESET -> GP28
7  - GND -> GND
9  - NSS -> GP17   (CSn)
11 - MISO -> GP16 (MISO)
13 - GND -> GND
2  - VSYS -> 5V
4  - DIO1 -> GP10
6  - X -> GP9
8  - X -> GP4
10 - DIO0 -> GP20
12 - MOSI -> GP19 (MOSI)
14 - SCK -> GP18  (SCK)

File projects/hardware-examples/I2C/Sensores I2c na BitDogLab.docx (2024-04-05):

Experimento com I2C Scan

Objetivo:

Sensores I2C comerciais:

Programa funcionando.

# Objetivo:

Criar um protocolo para que assim que um sensor for conectado aos slots I2C0 ou I2C1, o reconhecimento seja automático, indicando o tipo de sensor e seu endereço Hexa.

Para isto, já teremos alguns sensores cabeados. O usuário conecta nos slots I2C e a BitDogLab reconhece automaticamente.

# Sensores I2C comerciais:

Tipo | Código | Endereço Hexa
Sensor de Luz (https://www.makerhero.com/produto/sensor-de-luz-bh1750fvi-lux/?gad_source=1) | BH1750FVI (https://www.makerhero.com/img/files/download/BH1750fvi-Datasheet.pdf) GY-302 | 0x23 com ADDR Low or open 0x5C com ADDR Hgh
Sensor De Pressão e Temperatura (https://www.makerhero.com/produto/sensor-de-pressao-e-temperatura-bmp280/) | bmp280 (https://makerhero.com/img/files/download/BMP280-Datasheet.pdf) | 0x76
Acelerômetro e Giroscópio 3 Eixos 6 DOF (https://www.makerhero.com/produto/acelerometro-e-giroscopio-3-eixos-6-dof-mpu-6050/) | MPU-6050 GY-521 | 0x68
Sensor de Temperatura e Umidade (https://www.usinainfo.com.br/sensor-de-temperatura/sensor-aht10-de-alta-precisao-para-medir-temperatura-e-umidade-5691.html) | AHT10 (https://server4.eca.ir/eshop/AHT10/Aosong_AHT10_en_draft_0c.pdf) | 0x38
Acelerômetro 3 Eixos (https://www.makerhero.com/produto/acelerometro-3-eixos-mma8452/) | MMA8452 (https://www.makerhero.com/img/files/download/MMA8452Q-Datasheet.pdf) | 0x1C (SA0 = 0), 0x1D (SA0 = 1)
Sensor de Batimento Cardíaco e Oxímetro (https://www.makerhero.com/produto/sensor-de-batimento-cardiaco-e-oximetro-max30100/) | MAX30100 (https://www.makerhero.com/img/files/download/MAX30100-Datasheet.pdf) | 0xAF Endereço de leitura 0xAE Endereço de escrita
Sensor de Corrente DC (https://www.makerhero.com/produto/sensor-de-corrente-dc-ina219-i2c/) | INA219 (https://www.makerhero.com/img/files/download/INA219-Datasheet.pdf) | 0x40 padrão com A0 e A1 no GND porém permite config. ver datasheet (https://www.makerhero.com/img/files/download/INA219-Datasheet.pdf) p.14.
Sensor de Temperatura e Umidade (https://www.makerhero.com/produto/sensor-de-temperatura-e-umidade-hdc1080-alta-precisao/) precisão | HDC1080 (https://www.makerhero.com/img/files/download/HDC1080-Datasheet.pdf) | 0x40 padrão
Bússola Eletrônica (https://www.makerhero.com/produto/modulo-bussola-eletronica-hmc5883l/) | HMC5883L (https://www.makerhero.com/img/files/download/QMC5883L-Datasheet.pdf) | 0x0D padrão
Sensor de Cor (https://www.makerhero.com/produto/sensor-de-cor-tcs34725/) | TCS34725 (https://makerhero.com/img/files/download/datasheet-modulo-sensor-de-cor-tcs34725.pdf)
Sensor de Luz e Proximidade (https://www.makerhero.com/produto/sensor-de-gestos-e-proximidade/) | APDS-9900 (https://makerhero.com/img/files/download/APDS-9900-Datasheet.pdf)
Sensor de Temperatura IR (https://www.makerhero.com/produto/sensor-de-temperatura-ir-mlx90614/) | MLX90614 (https://www.makerhero.com/img/files/download/MLX90614-Datasheet.pdf)
Acelerômetro e Giroscópio 9 Eixos 10 DOF (https://www.makerhero.com/produto/acelerometro-e-giroscopio-9-eixos-10-dof-mpu-9250-com-bmp180/) | MPU-9250 (https://www.makerhero.com/img/files/download/Datasheet_MPU9250_REV1.0.pdf) com BMP280
Sensor de Distância a Laser (https://pt.aliexpress.com/item/1005006035148235.html?curPageLogUid=NSeEdo0cJFgF) | VL53L0X (https://www.st.com/en/imaging-and-photonics-solutions/vl53l0x.html)
Sensor de Dióxido De Carbono, Sensor De Gás, TVOC Qualidade Do Ar (https://pt.aliexpress.com/item/1005003980133652.html?curPageLogUid=n5SNRIwBOBeX) | CJMCU-811, CCS811, CO2, eCO2
ADC 4 Canais com Amplificador Pro Gain | ADS1115

# Programa funcionando. (https://drive.google.com/open?id=189uN20G1-Iwpo2TuFN-r0aV5dVbA8M0q&usp=drive_fs)

Programa pata a BitDogLab fazer a varredura dos canais I2C:

from machine import Pin, I2C

i2c0 = I2C(0, scl=Pin(1), sda=Pin(0), freq=400000)

i2c1 = I2C(1, scl=Pin(3), sda=Pin(2), freq=400000)

devices0 = i2c0.scan()

devices1 = i2c1.scan()

print("Endereços dos dispositivos I2C conectados:")

print("I2C0:")

for device in devices0:

print(" ",hex(device))

print("I2C1:")

for device in devices1:

print(" ",hex(device))

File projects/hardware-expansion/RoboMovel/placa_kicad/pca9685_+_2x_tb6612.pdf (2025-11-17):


pwm servo direção roda 1
pwm servo direção roda 2
pwm servo direção roda 3
pwm servo direção roda 4

tração
roda 1 | tração
| roda 2

tração
roda 3

tração
roda 4
tb6612fng (1) | tb6612fng (2)

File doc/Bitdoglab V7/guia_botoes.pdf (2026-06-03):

Guia Rapido - Botoes Tacteis | BitDogLab

# Guia Rapido - Botoes Tacteis

### Chip: Omron B3F | Tactile Switch SPST-NO 6x6mm

## 1. O que e esse hardware?

Chaves tacteis (push button) Omron B3F do tipo SPST-NO (Normalmente Aberto). Os terminais ficam DESCONECTADOS em repouso e se CONECTAM ao pressionar. O RP2040 usa resistor de pull-up interno: pino le HIGH solto e LOW pressionado.

Solto: | pino = HIGH (3.3V via pull-up interno do RP2040)
Pressionado: pino = LOW (curto com GND da placa)

Logica: value() == 0 -> pressionado
| value() == 1 -> solto

## 2. Conexao na BitDogLab

Botao | GPIO | Observacao
Botao A | GPIO5 | Uso geral
Botao B | GPIO6 | Uso geral
Botao C | GPIO10 | Disponivel somente na v7
Botao RESET | RUN | Reinicia o RP2040 (pino 30)

## 3. O problema do bounce (trepidacao)

Ao pressionar um botao mecanico, o contato vibra por alguns ms antes de estabilizar (bounce time maximo: 5ms segundo datasheet). Isso gera multiplas leituras falsas. Solucao: aguardar 10-20ms apos detectar a primeira borda.

import time

def debounce(pin, ms=15):
if pin.value() == 0: | # detectou pressionado
time.sleep_ms(ms) | # aguarda estabilizar
return pin.value() == 0 | # confirma leitura
return False

## 4. Codigo base em MicroPython

from machine import Pin
import time

btn_a = Pin(5, Pin.IN, Pin.PULL_UP)
btn_b = Pin(6, Pin.IN, Pin.PULL_UP)
btn_c = Pin(10, Pin.IN, Pin.PULL_UP) # v7 apenas

while True:
if btn_a.value() == 0:

Guia Rapido - Botoes Tacteis | BitDogLab

print('Botao A pressionado!') time.sleep_ms(200) # debounce simples if btn_b.value() == 0:
print('Botao B pressionado!') time.sleep_ms(200)

## 5. Usando interrupcao (IRQ)

### Para reagir ao botao sem bloquear o loop principal, use IRQ:

def ao_pressionar(pin):
print('Acionado!')

btn_a.irq(trigger=Pin.IRQ_FALLING, handler=ao_pressionar)
# IRQ_FALLING = borda de descida (HIGH -> LOW = botao pressionado) # IRQ_RISING = borda de subida (LOW -> HIGH = botao solto)

## 6. Caracteristicas Omron B3F

Parametro | Valor
Tipo de contato | SPST-NO (Normalmente Aberto)
Corrente / tensao max | 50mA, 24VDC
Resistencia de contato | 100 mohm max (inicial)
Bounce time | 5ms max
Durabilidade | 1.000.000 operacoes minimo
Forca de acionamento | 0.98 N a 2.55 N
Temperatura de operacao | -25 a +70 graus C

## 7. Aplicacoes praticas

- Contador de cliques: incrementar variavel a cada pressionada confirmada.
- Navegacao de menu: A=proximo item, B=selecionar/confirmar.
- Pausar/retomar: alternar flag bool com cada pressionada.
- Dois botoes simultaneos: verificar btn_a.value()==0 and btn_b.value()==0.
Ref: Omron B3F Datasheet | BitDogLab v7: A=GPIO5, B=GPIO6, C=GPIO10 | v6: A=GPIO5, B=GPIO6 (sem C)

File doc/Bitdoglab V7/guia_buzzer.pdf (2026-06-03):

Guia Rapido - Buzzer Passivo | BitDogLab

# Guia Rapido - Buzzer Passivo

### Tipo: Buzzer Piezoeletrico Passivo | Controlado por PWM

## 1. O que e esse hardware?

O buzzer da BitDogLab e um buzzer PASSIVO (piezoeletrico). Diferente do buzzer ATIVO (que bipa sozinho ao receber 3.3V), o passivo precisa de um sinal PWM oscilando na frequencia desejada para gerar som. Isso permite tocar qualquer nota musical ou criar efeitos sonoros variando a frequencia do PWM.

Buzzer ATIVO: recebe 3.3V -> bipa em frequencia fixa (sem controle de tom)
Buzzer PASSIVO: recebe PWM -> frequencia do PWM = frequencia do som gerado

Regra: freq(440) -> LA (nota A4)
freq(262) -> DO (nota C4)
duty_u16(0) -> silencio (sem cortar o PWM)

## 2. Conexao na BitDogLab

Buzzer | GPIO | Versao | Observacao
Buzzer A | GPIO21 | v7 | Via transistor NPN (maior potencia)
Buzzer B | GPIO10 | v7 | Conexao direta ao GPIO
Buzzer | GPIO10 | v6 | Unico buzzer (GPIO10 nao e botao C)

O Buzzer A usa um transistor como amplificador de corrente: o GPIO21 aciona a base do transistor, que por sua vez aciona o buzzer com mais corrente do que o GPIO sozinho forneceria. O Buzzer B e controlado diretamente pelo GPIO10.

## 3. Como o PWM gera som

O buzzer piezoeletrico vibra na mesma frequencia do sinal eletrico aplicado. Essa vibracao mecanica move o ar e gera o som. O duty cycle (largura do pulso) controla o VOLUME: 50% (32768) e o ponto de maior amplitude, valores acima ou abaixo reduzem o volume. duty_u16=0 = silencio total sem desligar o pino.

Frequencia (freq) -> define o TOM (nota musical)
Duty cycle (duty) -> define o VOLUME

50% duty (32768) = volume maximo
25% duty (16384) = volume medio
duty_u16(0) | = silencio (buzzer quieto, PWM ativo)

## 4. Codigo base em MicroPython

from machine import Pin, PWM
import time

buzzer = PWM(Pin(21)) # Buzzer A (v7)
# buzzer = PWM(Pin(10)) # Buzzer B (v7) ou unico (v6)

def tocar(freq_hz, duracao_ms, volume=32768): buzzer.freq(freq_hz)
buzzer.duty_u16(volume)
time.sleep_ms(duracao_ms)
buzzer.duty_u16(0) | # silencio entre notas
time.sleep_ms(20)

def silencio():
buzzer.duty_u16(0)
tocar(440, 300) | # LA por 300ms
tocar(523, 300) | # DO
tocar(659, 300) | # MI
silencio()

## 5. Notas musicais - frequencias

Nota | Freq (Hz) | Nota | Freq (Hz) | Nota | Freq (Hz)
DO (C4) | 262 | FA (F4) | 349 | SI (B4) | 494
RE (D4) | 294 | SOL (G4) | 392 | DO (C5) | 523
MI (E4) | 330 | LA (A4) | 440 | --- | ---

# Dicionario de notas para facil uso:

NOTAS = {
'C4':262, 'D4':294, 'E4':330, 'F4':349, 'G4':392, 'A4':440, 'B4':494, 'C5':523, 'C3':131, 'G3':196, 'A3':220, 'B3':247, }

# Exemplo: toca a melodia de Parabens

melodia = [('C4',200),('C4',200),('D4',400),('C4',400), ('F4',400),('E4',800)]
for nota, ms in melodia:
tocar(NOTAS[nota], ms)

## 6. Efeitos sonoros uteis

# Alarme (dois tons alternados) for _ in range(5):

tocar(880, 200) | # tom agudo
tocar(440, 200) | # tom grave

# Bip de confirmacao

tocar(1000, 100)

# Bip de erro (tom descendente) for f in [800, 600, 400]:

tocar(f, 150)

# Sirene (sweep de frequencia) import time

for f in range(300, 1500, 20): buzzer.freq(f)
buzzer.duty_u16(32768)
time.sleep_ms(10)
buzzer.duty_u16(0)

## 7. O que ajustar na pratica

- Se o som estiver muito fraco: aumentar volume (duty_u16 ate 32768 = 50%).
- Frequencias audiveis: 100Hz (grave) a 4000Hz (agudo). Acima de 4kHz pode nao ser audivel no buzzer.
- Faixa mais clara na maioria dos buzzers piezo: 1kHz a 4kHz.
- Use duty_u16(0) para silencio (mantem PWM ativo) em vez de deinit() entre notas.
- Para musica: deixe um pequeno intervalo entre notas (20-50ms) para separa-las.
Ref: BitDogLab HDB (Unicamp) | v7: BuzzerA=GPIO21(transistor), BuzzerB=GPIO10 | v6: Buzzer=GPIO10

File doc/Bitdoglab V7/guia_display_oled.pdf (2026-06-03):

Guia Rapido - Display OLED | BitDogLab

# Guia Rapido - Display OLED 128x64

Chip: SSD1306 (Solomon Systech) | I2C | 0.96 polegadas

### 1. O que e esse hardware?

Display OLED monocromatico de 128x64 pixels controlado pelo chip SSD1306. Cada pixel pode ser ligado (branco) ou desligado (preto). A comunicacao e feita via I2C com apenas 2 fios (SDA e SCL). O SSD1306 possui GDDRAM (memoria grafica interna): voce escreve na RAM e chama show() para transferir para o display.

Display: 128 colunas x 64 linhas = 8192 pixels
Coordenadas: x=0..127 (esquerda->direita), y=0..63 (topo->base)
I2C address: 0x3C (60 decimal)
Biblioteca: ssd1306.py (deve estar no RP2040)

### 2. Conexao na BitDogLab

Sinal | v7 (GPIO) | v6 (GPIO) | Funcao
SDA | GPIO2 | GPIO14 | Dados I2C
SCL | GPIO3 | GPIO15 | Clock I2C
VCC | 3.3V | 3.3V | Alimentacao
GND | GND | GND | Terra

Frequencia I2C recomendada: 400kHz (Fast mode). O barramento I2C do RP2040 e hardware (I2C0 na v7, I2C1 na v6).

### 3. Como funciona o GDDRAM

O SSD1306 tem um framebuffer interno (GDDRAM). A biblioteca ssd1306.py mantem uma copia desse buffer em RAM. Voce desenha/escreve no buffer e so quando chamar oled.show() os dados sao enviados via I2C para o display. Isso evita flickering e melhora a performance.

Fluxo: oled.fill(0) | # limpa buffer
oled.text('Ola!', 0, 0) # escreve no buffer
oled.show() | # envia para o display

### 4. Codigo base em MicroPython

from machine import Pin, I2C
from ssd1306 import SSD1306_I2C

# BitDogLab v7

i2c = I2C(0, scl=Pin(3), sda=Pin(2), freq=400000)
# BitDogLab v6

# i2c = I2C(1, scl=Pin(15), sda=Pin(14), freq=400000)

oled = SSD1306_I2C(128, 64, i2c)

oled.fill(0) | # limpa tela

Guia Rapido - Display OLED | BitDogLab
oled.text('BitDogLab', 0, 0) | # texto na linha 0
oled.text('OLED 128x64', 0, 10) | # texto na linha 10
oled.rect(0, 20, 128, 30, 1) | # retangulo
oled.hline(0, 32, 128, 1) | # linha horizontal
oled.pixel(64, 48, 1) | # pixel individual
oled.show() | # envia para o display

### 5. Primitivas graficas disponiveis

Funcao | Parametros | Descricao
oled.fill(c) | c: 0=preto, 1=branco | Preenche tela inteira
oled.pixel(x,y,c) | x,y: coordenada | Acende/apaga pixel
oled.text(s,x,y,c) | s: string, x,y: posicao | Texto 8x8 pixels
oled.hline(x,y,w,c) | w: largura | Linha horizontal
oled.vline(x,y,h,c) | h: altura | Linha vertical
oled.rect(x,y,w,h,c) | w,h: dimensoes | Retangulo (contorno)
oled.fill_rect(x,y,w,h,c) | w,h: dimensoes | Retangulo preenchido
oled.show() | - | Envia buffer para display

### 6. Caracteristicas SSD1306

Parametro | Valor
Resolucao | 128 x 64 pixels
Interface | I2C (ou SPI)
Endereco I2C | 0x3C (padrao BitDogLab)
Tensao de alimentacao | 1.65V a 3.3V (logica)
Memoria GDDRAM | 128x64 / 8 = 1024 bytes
Tamanho da fonte padrao | 8x8 pixels por caractere

### 7. O que observar na pratica

- Sempre chamar oled.fill(0) antes de redesenhar para evitar sobreposicao de texto.
- oled.show() e lento (~50ms): evite chamar a cada frame em animacoes rapidas.
- Texto padrao: 16 colunas (128/8) e 8 linhas (64/8). y=0,8,16,24,32,40,48,56.
- Se o display nao inicializar, verifique a versao (v6 vs v7) e os pinos I2C.
- Use i2c.scan() para confirmar que o endereco 60 (0x3C) aparece na lista.
Ref: SSD1306 Datasheet Rev 1.1 Solomon Systech 2008 | v7: I2C0 GPIO2/3 | v6: I2C1 GPIO14/15

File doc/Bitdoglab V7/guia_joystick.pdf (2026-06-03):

Guia Rapido - Joystick Analogico | BitDogLab

# Guia Rapido - Joystick Analogico

### Modulo: KY-023 | 2 eixos analogicos + botao digital

## 1. O que e esse hardware?

O joystick KY-023 e composto por dois potenciometros (resistores variaveis) para os eixos X e Y, mais um botao digital (SW) que e acionado ao pressionar o cabo. Os potenciometros geram tensoes analogicas entre 0V e 3.3V conforme a posicao. O RP2040 le esses valores via ADC (conversor analogico-digital).

Centro (repouso): VRx = VRy = ~1.65V -> ADC = ~32767
Maximo (eixo +): VRx ou VRy = 3.3V -> ADC = 65535
Minimo (eixo -): VRx ou VRy = 0V -> ADC = 0

SW (botao): PULL_UP interno -> 1 = solto, 0 = pressionado

## 2. Conexao na BitDogLab

Sinal | GPIO | Tipo | Descricao
VRy | GPIO26 | ADC0 (analogico) | Eixo Y (vertical) 0-3.3V
VRx | GPIO27 | ADC1 (analogico) | Eixo X (horizontal) 0-3.3V
SW | GPIO22 | Digital (entrada) | Botao de pressao (pull-up)

GPIO26=ADC0 e GPIO27=ADC1 sao os unicos pinos ADC disponiveis para o joystick. GPIO28=ADC2 e usado pelo microfone.

## 3. Zona morta (deadzone)

O centro mecanico do joystick raramente le exatamente 32767. Ha uma variacao natural de +/-2000 a +/-5000 unidades mesmo em repouso. Sempre implemente uma zona morta para evitar movimento involuntario quando o joystick esta solto.

CENTER = 32767
DEADZONE = 4000

def em_zona_morta(valor):
return abs(valor - CENTER) < DEADZONE

## 4. Codigo base em MicroPython

from machine import Pin, ADC import time

jx = ADC(Pin(27)) | # eixo X
jy = ADC(Pin(26)) | # eixo Y
jsw = Pin(22, Pin.IN, Pin.PULL_UP) # botao

CENTER = 32767
DEADZONE = 4000

Guia Rapido - Joystick Analogico | BitDogLab

while True:
x = jx.read_u16() # 0 a 65535
y = jy.read_u16()
sw = jsw.value() | # 0 = pressionado
dx = x - CENTER | # deslocamento X (-32767 a +32767)
dy = y - CENTER | # deslocamento Y

if abs(dx) > DEADZONE:
print('X:', 'direita' if dx > 0 else 'esquerda') if abs(dy) > DEADZONE:
print('Y:', 'baixo' if dy > 0 else 'cima')
if sw == 0:
print('Botao pressionado!') time.sleep(0.05)

## 5. Mapear para faixa customizada

### Para converter o valor ADC para uma faixa util (ex: posicao 0-4 numa matriz 5x5):

def mapear(valor, min_in, max_in, min_out, max_out):
return int((valor - min_in) / (max_in - min_in) * (max_out - min_out) + min_out)
col = mapear(jx.read_u16(), 0, 65535, 0, 4) | # 0 a 4
lin = mapear(jy.read_u16(), 0, 65535, 0, 4) | # 0 a 4

## 6. Especificacoes do modulo KY-023

Parametro | Valor
Eixos analogicos | 2 (X e Y), potenciometros
Faixa de saida | 0V a VCC (0 a 65535 no ADC)
Resolucao ADC (RP2040) | 12-bit (0-4095) interno, 16-bit via read_u16()
Botao SW | SPST-NO, pull-up, ativo em LOW
Tensao de operacao | 3.3V (compativel com RP2040)

## 7. Aplicacoes praticas

- Mover cursor ou personagem numa matriz/display.
- Controlar velocidade: velocidade proporcional ao deslocamento do eixo.
- Selecionar opcao de menu: direita/esquerda para navegar.
- Controle de angulo: mapear ADC para graus (0-180) para servomotor.
Ref: BitDogLab HDB | v7 e v6: VRy=GPIO26 (ADC0), VRx=GPIO27 (ADC1), SW=GPIO22

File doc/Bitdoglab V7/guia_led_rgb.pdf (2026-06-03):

Guia Rapido - LED RGB | BitDogLab

# Guia Rapido - LED RGB

Chip: Kingbright WP154A4SUREQBFZGC | Catodo Comum 5mm Full Color

### 1. O que e esse hardware?

LED de 5mm com tres cores (R/G/B) num unico encapsulamento de catodo comum. Cada cor e controlada de forma independente via PWM, permitindo misturar qualquer tonalidade do espectro RGB. Catodo comum = pino negativo compartilhado, conectado ao GND.

Pino 1 (mais comprido) = Catodo Comum (GND)
Pino 2 = Anodo VERMELHO
Pino 3 = Anodo AZUL
Pino 4 = Anodo VERDE

### 2. Conexao na BitDogLab v7

Cor | GPIO | Resistor | Vf tipico @ 20mA | Comprimento onda
VERMELHO | GPIO13 | 220 ohm | 1.9 V (max 2.5V) | 645 nm
VERDE | GPIO11 | 220 ohm | 3.3 V (max 4.1V) | 515 nm
AZUL | GPIO12 | 150 ohm | 3.3 V (max 4.0V) | 460 nm
GND | GND | - | Catodo comum | -

Corrente maxima: Vermelho=30mA, Verde=25mA, Azul=30mA. Angulo de visao: 50 graus.

### 3. Como funciona o controle PWM

O RP2040 usa PWM (modulacao por largura de pulso) para variar o brilho de cada cor. duty_u16=0 = apagado, duty_u16=65535 = brilho maximo. Combinando as tres cores obtem-se 16 milhoes de cores possiveis.

### 4. Codigo base em MicroPython

from machine import Pin, PWM

led_r = PWM(Pin(13)); led_r.freq(1000) led_g = PWM(Pin(11)); led_g.freq(1000) led_b = PWM(Pin(12)); led_b.freq(1000)

def cor(r, g, b): | # r, g, b: 0 a 255
led_r.duty_u16(r * 257)
led_g.duty_u16(g * 257)
led_b.duty_u16(b * 257)
cor(255, | 0, | 0) # vermelho
cor( 0, 255, | 0) # verde
cor( 0, | 0, 255) # azul
cor(255, 255, | 0) # amarelo
cor(255, 255, 255) # branco
cor( 0, | 0, | 0) # apagado

Guia Rapido - LED RGB | BitDogLab

### 5. Aplicacoes praticas

Aplicacao | Logica
Indicador de status | verde=ok, amarelo=aviso, vermelho=erro
Fade suave de cor | incrementar duty_u16 em loop com time.sleep
Ciclo arco-iris | variar R->G->B ciclicamente
Reagir ao microfone | brilho proporcional ao volume captado

### 6. Parametros importantes

Parametro | Vermelho | Azul | Verde
Intensidade tipica (mcd) @ 20mA | 1300 | 900 | 3600
Corrente maxima (mA) | 30 | 30 | 25
Dissipacao maxima (mW) | 75 | 120 | 102.5

### 7. O que observar na pratica

- Azul e verde aparecem mais fracos que vermelho (Vf similar a VCC=3.3V, menos corrente).
- Para branco equilibrado: ajuste empiricamente, ex. cor(255, 120, 80).
- freq(1000) e suficiente. Minimo recomendado: 50Hz para evitar flickering visivel.
- Nao conecte sem resistor em serie - pode queimar o LED e o pino GPIO.
Ref: Kingbright WP154A4SUREQBFZGC Datasheet Rev V.11 2025 | BitDogLab v7: R=GPIO13, G=GPIO11, B=GPIO12

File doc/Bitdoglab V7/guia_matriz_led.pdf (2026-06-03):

Guia Rapido - Matriz LED 5x5 | BitDogLab

# Guia Rapido - Matriz de LED 5x5

Chip: WS2812B (WorldSemi) | NeoPixel RGB Inteligente 5050

### 1. O que e esse hardware?

A matriz 5x5 da BitDogLab e composta por 25 LEDs WS2812B. Cada LED e um modulo completo com chip de controle integrado, LEDs R/G/B e driver de corrente tudo num pacote SMD 5050. Todos os 25 LEDs sao controlados por um UNICO pino digital usando protocolo serie NZR (1 fio).

Cascata: GPIO7 -> LED[0] -> LED[1] -> ... -> LED[24]

Cada LED recebe 24 bits de dados: 8 bits G + 8 bits R + 8 bits B Ordem dos dados: GRB (atencao: NAO e RGB!)
Resolucao: 256 niveis por canal = 16.777.216 cores possiveis

### 2. Conexao na BitDogLab

Sinal | GPIO | Descricao
DIN (dados) | GPIO7 | Sinal de controle NZR para o primeiro LED
VDD | 5V | Alimentacao dos LEDs (via placa)
VSS | GND | Terra

O protocolo NZR opera a 800kbps. O RP2040 usa o bloco PIO (I/O programavel) para gerar os pulsos com timing preciso - tudo gerenciado automaticamente pela biblioteca neopixel.

### 3. Mapeamento da matriz 5x5

Os 25 LEDs sao numerados de 0 a 24 em ordem serpentina (snake) ou linear, dependendo do layout fisico da placa. Na BitDogLab o mapeamento e:

Linha 0: LED 0 1 2 3 4 (topo)
Linha 1: LED 5 6 7 8 9
Linha 2: LED 10 11 12 13 14
Linha 3: LED 15 16 17 18 19
Linha 4: LED 20 21 22 23 24 (base)

Formula: indice = linha * 5 + coluna
Exemplo: linha=2, coluna=3 -> indice = 2*5+3 = 13

### 4. Codigo base em MicroPython

import neopixel
from machine import Pin
import time

NUM_LEDS = 25
np = neopixel.NeoPixel(Pin(7), NUM_LEDS)

# Acender LED individual (linha, coluna, R, G, B)

Guia Rapido - Matriz LED 5x5 | BitDogLab

def pixel(linha, col, r, g, b): np[linha * 5 + col] = (r, g, b) np.write()

# Apagar todos

def limpar():
np.fill((0, 0, 0))
np.write()
pixel(0, 0, 255, 0, 0) | # LED [0,0] vermelho
pixel(2, 2, 0, 255, 0) | # LED central verde
np.fill((0, 0, 50)) | # todos azul fraco
np.write()

### 5. Controle de brilho

O brilho e controlado diretamente pelos valores R, G, B (0-255). Para brilho geral, escale os valores. Evite usar brilho 255 em muitos LEDs ao mesmo tempo: cada WS2812B consome ate 60mA em brilho maximo (todos brancos = 25 x 60mA = 1.5A!).

BRILHO = 30 # 0 a 255 (30 = ~12%, seguro para uso escolar)

def pixel_brilho(linha, col, r, g, b):
escala = BRILHO / 255
np[linha*5+col] = (int(r*escala), int(g*escala), int(b*escala)) np.write()

### 6. Caracteristicas WS2812B

Parametro | Valor
Tensao de alimentacao | 3.5V a 5.3V (VDD)
Corrente por LED (max) | 60mA (branco total)
Protocolo | NZR serial, 800 kbps
Dados por pixel | 24 bits (GRB, 8 bits cada)
Frequencia de varredura | minimo 400 Hz
Temperatura de operacao | -25 a +80 graus C

### 7. Aplicacoes praticas

- Emojis e icones: definir matriz de pixels com cores.
- Animacoes: atualizar np e chamar np.write() em cada frame.
- Indicador de direcao: acender linha ou coluna conforme joystick.
- Jogo da vida ou Snake: logica celular com refresh a cada 100-200ms.
Ref: WS2812B Datasheet (WorldSemi) | BitDogLab v7 e v6: GPIO7 | 25 LEDs (5x5)

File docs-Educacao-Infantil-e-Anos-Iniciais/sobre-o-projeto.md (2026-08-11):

🚀 Desafio na Lua

**Status do Projeto:** 🚧 Em desenvolvimento

Sobre o projeto

Com a implementação da **BNCC da Computação** nas escolas brasileiras, torna-se cada vez mais importante oferecer recursos pedagógicos que auxiliem professores no desenvolvimento das competências previstas para a Educação Infantil e o Ensino Fundamental – Anos Iniciais.

Pensando nisso, estamos desenvolvendo um conjunto de materiais didáticos voltados para crianças de **4 a 9 anos**, utilizando uma abordagem lúdica, investigativa e baseada em desafios. O objetivo é promover o desenvolvimento do **Pensamento Computacional**, estimulando também habilidades relacionadas à resolução de problemas, raciocínio lógico, criatividade, colaboração, comunicação, autonomia, pensamento científico e matemático.

A proposta busca integrar conceitos da Computação com outras áreas do conhecimento, favorecendo experiências significativas de aprendizagem por meio do brincar, da experimentação e da construção coletiva do conhecimento.

---

🎮 Gamificação como estratégia de aprendizagem

O projeto utiliza princípios da **gamificação** para tornar a aprendizagem mais envolvente e motivadora.

Os estudantes são convidados a resolver desafios progressivos, trabalhar em equipe, elaborar estratégias, testar hipóteses e encontrar diferentes soluções para um mesmo problema. Dessa forma, cada atividade transforma-se em uma missão, incentivando a participação ativa, a cooperação e o protagonismo dos alunos.

Mais do que alcançar respostas corretas, o foco está no processo de investigação, na experimentação e no desenvolvimento das competências previstas pela BNCC da Computação.

---

🌕 Kit Desafio na Lua

O material, atualmente em desenvolvimento, será composto por três recursos principais:

* 🌕 Tapete Desafio na Lua;
* 🃏 Cartas de Desafios;
* 👨‍🚀 Personagens.

Os três elementos trabalham de forma integrada para proporcionar atividades desplugadas de Computação, podendo ser utilizados em diferentes espaços da escola.

---

🌕 1. Tapete Desafio na Lua

O **Tapete Desafio na Lua** é um recurso pedagógico desenvolvido para ensinar conceitos iniciais de Robótica Educacional e Pensamento Computacional de maneira concreta, divertida e acessível.

Por meio da movimentação sobre o tapete, as crianças exploram conceitos como:

* sequenciamento;
* algoritmos;
* planejamento;
* orientação espacial;
* lateralidade;
* decomposição de problemas;
* identificação de padrões;
* elaboração e teste de estratégias;
* resolução de problemas.

O principal objetivo é garantir que a aprendizagem aconteça **sem deixar de lado o brincar**, respeitando as características da infância e valorizando a exploração, a curiosidade e a interação entre os estudantes.

---

🃏 2. Cartas de Desafios

O kit contará com **12 cartas de desafios**, organizadas para estimular diferentes níveis de complexidade.

As atividades deverão ser realizadas em equipes de **2 ou 3 estudantes**, dependendo da quantidade de alunos da turma.

Cada desafio incentiva os participantes a:

* analisar situações-problema;
* planejar soluções;
* construir algoritmos;
* discutir estratégias;
* testar possibilidades;
* identificar erros e realizar correções;
* trabalhar de forma colaborativa;
* comunicar suas ideias e justificar suas decisões.

Essa dinâmica fortalece competências cognitivas, sociais e emocionais, promovendo uma aprendizagem significativa e colaborativa.

---

👨‍🚀 3. Personagens

Os personagens fazem parte da estratégia de **gamificação** do projeto.

O professor poderá imprimir os personagens (preferencialmente plastificados) e posicioná-los sobre diferentes quadrantes do tapete para representar os objetivos de cada desafio.

Como são móveis, esses elementos permitem criar inúmeras configurações, aumentando a variedade das atividades e possibilitando novos desafios sem necessidade de modificar o tapete.

Além de tornar as aulas mais envolventes, os personagens contribuem para o desenvolvimento de competências previstas na BNCC da Computação, como:

* Pensamento Computacional;
* resolução de problemas;
* criação e execução de algoritmos;
* abstração;
* decomposição de problemas;
* reconhecimento de padrões;
* raciocínio lógico;
* criatividade;
* colaboração;
* comunicação;
* tomada de decisões;
* persistência diante de desafios;
* autonomia;
* cultura digital.

---

🎯 Público-alvo

* Pré-Escola (4 e 5 anos)
* Ensino Fundamental – Anos Iniciais (1º ao 4º ano)

---

📚 Alinhamento

O projeto foi concebido considerando as competências da **BNCC da Computação**, integrando atividades desplugadas, aprendizagem baseada em desafios, cultura maker, robótica educacional e metodologias ativas.

Nosso objetivo é oferecer um material acessível, divertido e fundamentado pedagogicamente, auxiliando professores na implementação da Computação na Educação Básica.

---

🚧 Em desenvolvimento

Este repositório encontra-se em constante evolução. Novos materiais, desafios, personagens, orientações pedagógicas e recursos para impressão serão disponibilizados nas próximas versões.

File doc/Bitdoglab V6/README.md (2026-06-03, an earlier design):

# [PT-BR] Manual BitDogLab (Iniciando com Micropython)

**Table of Contents**

- [[PT-BR] Manual BitDogLab (Iniciando com Micropython)](https://github.com/BitDogLab/BitDogLab/tree/main/doc#pt-br-manual-bitdoglab-iniciando-com-micropython)

	- [Conteúdo material](https://github.com/BitDogLab/BitDogLab/tree/main/doc#conte%C3%BAdo-material)

	- [Montando a BitDogLab](https://github.com/BitDogLab/BitDogLab/tree/main/doc#montando-a-bitdoglab)

	- [Especificação/Periféricos da BitDogLab v5.3](https://github.com/BitDogLab/BitDogLab/tree/main/doc#especifica%C3%A7%C3%A3operif%C3%A9ricos-da-bitdoglab-v53)

	- [Iniciando com MicroPython](https://github.com/BitDogLab/BitDogLab/tree/main/doc#iniciando-com-micropython)

		- [Gravação do firmware](https://github.com/BitDogLab/BitDogLab/tree/main/doc#grava%C3%A7%C3%A3o-do-firmware)

			- [Alternativas de gravação de firmware](https://github.com/BitDogLab/BitDogLab/tree/main/doc#alternativas-de-grava%C3%A7%C3%A3o-de-firmware)

	- [Executando primeiro exemplo de código](https://github.com/BitDogLab/BitDogLab/tree/main/doc#executando-primeiro-exemplo-de-c%C3%B3digo)

A **BitDogLab**, é uma iniciativa que partiu do projeto escola 4.0 na Unicamp, uma ferramenta educacional voltada para o aprendizado de computação embarcada e eletrônica. Baseada no dispositivo Raspberry Pi Pico H ou W (wifi/bluetooth), a BitDogLab permite ao usuário explorar, montar e programar usando componentes montados nesta placa além de componentes adicionais externos (periféricos) conectados em uma forma organizada e estruturada. Meticulosamente selecionados, os componentes fomentam o aprendizado com "mãos na massa", encorajando os usuários a evoluírem suas habilidades em programação embarcada e eletrônica de forma progressiva e sinérgica. Essa plataforma rica oferece uma experiência vibrante, This enriching platform offers a vibrant experience, provendo imersão dos usuários em um ambiente de aprendizado colorido, autoral e sinestésico. Adicionalmente a BitDogLab é otimizada para programação assistida por meio de large language models (LLM), como o GPT-4o, facilitando uma aprendizagem mais intuitiva guiada por um tutor incansável.

Objetivando a educação pré-universitária (12+), BitDogLab busca catalizar e incorporar a educação tecnológica, provendo uma ferramenta robusta e flexível únicamente integrada com a jornada de aprendizado dos estudantes.

## Conteúdo material

A bitdoglab vem uma caixa padrão de correio (16x11x5 cm) como a ilustrada abaixo.



Dentro da caixa você encontra a BitDogLab envolta em um envelope anti-estático, um cabo tipo micro-usb para usb-a e a capa do joystick analógico da BitDogLab.



Cabo tipo micro-usb para usb-a



Capa do joystick



## Montando a BitDogLab

Retire a placa do envelope anti-estático.



Plugue a capa do joystick na BitDogLab como ilustrado abaixo.



Dessa forma a BitDogLab estará pronta para uso



## Especificação/Periféricos da BitDogLab v5.3

A placa BitDogLab possui as seguintes dimensões: 99 x 89 x 25 mm (comprimento, largura e altura).




A Placa BitDogLab é uma plataforma completa indicada para ensino de software/sistemas embarcados.
O módulo Microcontrolador é o cérebro da placa, composto pelo microcontrolador [Raspberry Pi Pico W](https://www.raspberrypi.com/documentation/microcontrollers/raspberry-pi-pico.html "Raspberry Pi Pico W") com as seguintes especificações:
- Microcontrolador RP2040 microcontroller
- Módulo castelado para soldagem direta na placa base BitDogLab
- Processador Dual-core Arm Cortex-M0+, clock flexivel até 133 MHz
- 264kB SRAM e 2MB QSPI flash embarcado
- Rede sem fio do tipo LAN 2.4GHz 802.11n
- Bluetooth 5.2
- 26 pinos multifuncionais (GPIO), incluindo 3 pinos analógicos
- Controladores: 2 × UART, 2 × SPI, 2 × I2C e 16 canais PWM 
- Controlador USB 1.1 com PHY, suportando modos host e device
- 8x I/Os programáveis (PIO) por meio de máquinas de estado para periféricos customizados
- Tensão de entrada de 1.8–5.5V DC
- Temperatura de operação de -20°C to +70°C
- Programação do tipo Drag-and-drop usando mass storage USB
- Modo de operação de baixo consumo e dormente
- Clock preciso e sensor de temperatura embarcado
- Bibliotecas de aceleração de cálculos inteiros e de ponto flutuante no chip

Pinout Raspberry Pi Pico W



Lista de periféricos embarcados na placa BitDogLab:
1) A BitDogLab possui uma Bateria 3.7V 2200Mah Li-Ion CR18650 e seu devido suporte de bateria.



2) LED Colorido (SMD5050 RGB LEDs ROHS)



3) Display OLED (0.96 polegadas I2C 128x64 oled display)



4) Matriz de LEDs coloridos (LED-RGB 5x5 5050 WS2812)



5) Microfone com amplificador de áudio (MAX4466EXK)



6) Joystick Analógico (Plugin 13x13mm Multi-Dir ROHS)



7) Botões (A e B) - Chave Táctil 12x12x7.5 mm



8) Buzzers (Esquerdo e Direito) - 80dB Externally Driven Magnetic 2.7kHz SMD, 8.5x8.5mm Buzzers ROHS



9) Conectores de sensores de expansão I2C (1 e 0) - 2.5mm Plugin,P=2.5mm Wire To Board Connector ROHS
- I2C1 (pino 1 – esquerda)
	- 1: GP3 (SCL I2C1)
	- 2: GP2 (SDA I2C1)
	- 3: 3.3V
	- 4: GND referencia
- I2C0 (pino 1 – esquerda)
	- 1: GP1 (SCL I2C0)
	- 2: GP0 (SDA I2C0)
	- 3: 3.3V
	- 4: GND referencia



10) Circuito de gerenciamento de energia - IP5306 ESOP-8 Battery Management ICs ROHS (Fully-Integrated Power Bank System-On-Chip with 2.1A charger, 2.4A discharger)



11) Conector de expansão de GPIOs (pino 1 canto superior esquerdo) - 2.54mm Straight Gold Brass 2x7P 7 Push - Pull P=2.54mm IDC Connectors ROHS
- 1: GND referencia
- 2: VSYS (5V)
- 3: 3.3V
- 4: GP8
- 5: GP28
- 6: GP9
- 7: AGND
- 8: GP4
- 9: GP17
- 10: GP20
- 11: GP16
- 12: GP19
- 13: GND referencia
- 14: GP18



12) Botão de reset - 8mm Round Button Brick nogging SPST SMD Tactile Switches ROHS



13) Conector para painel solar (6V) - 1x2P -40℃~+105℃ 8A 130V Green 18~26 Straight 2.54mm 0.5~1 1 2 Plugin,P=2.54mm Screw terminal ROHS


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

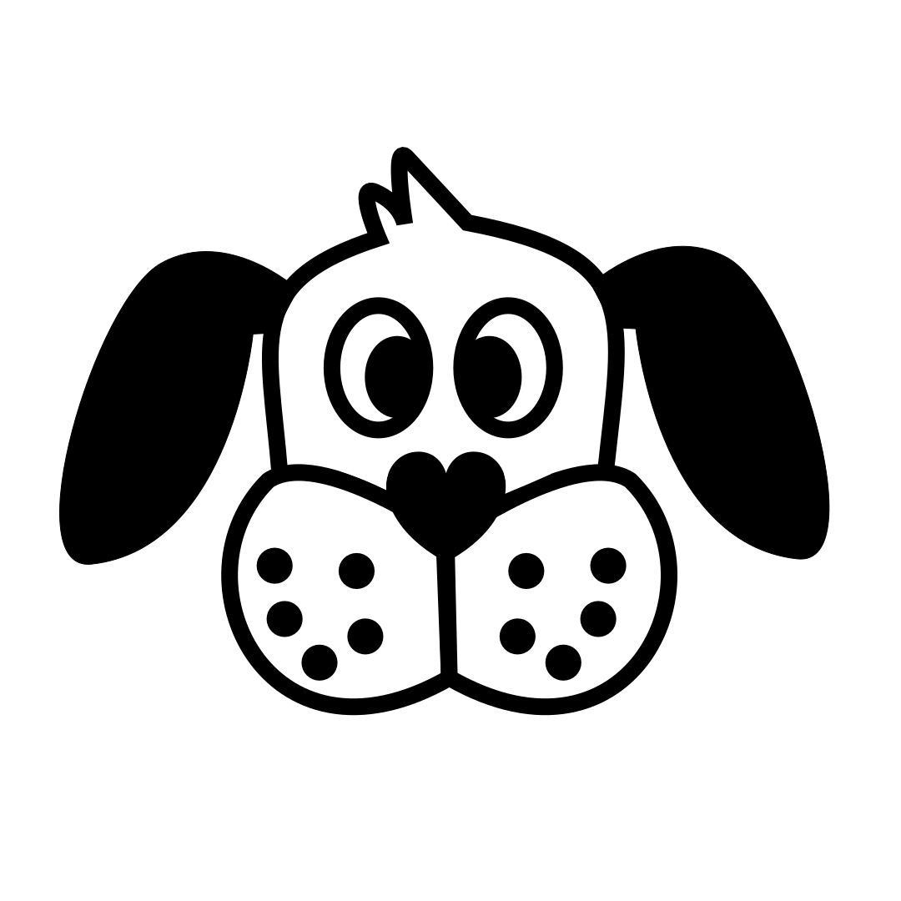
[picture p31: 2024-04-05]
projects/hardware-examples/Display OLED/Figuras/exemplo.png

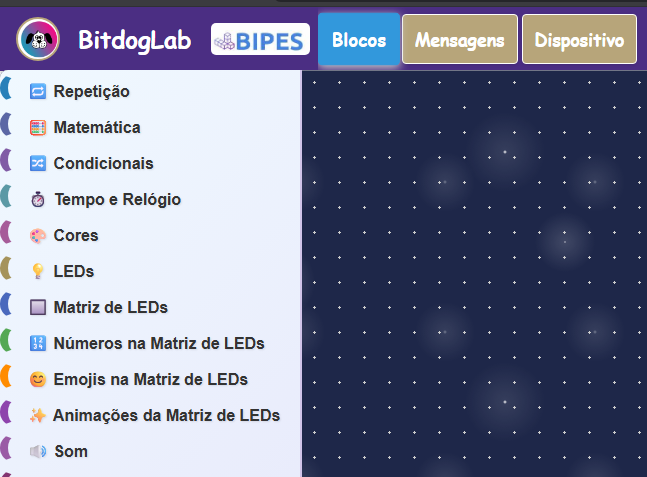
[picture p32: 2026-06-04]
images/Bipes-bitdoglab.png

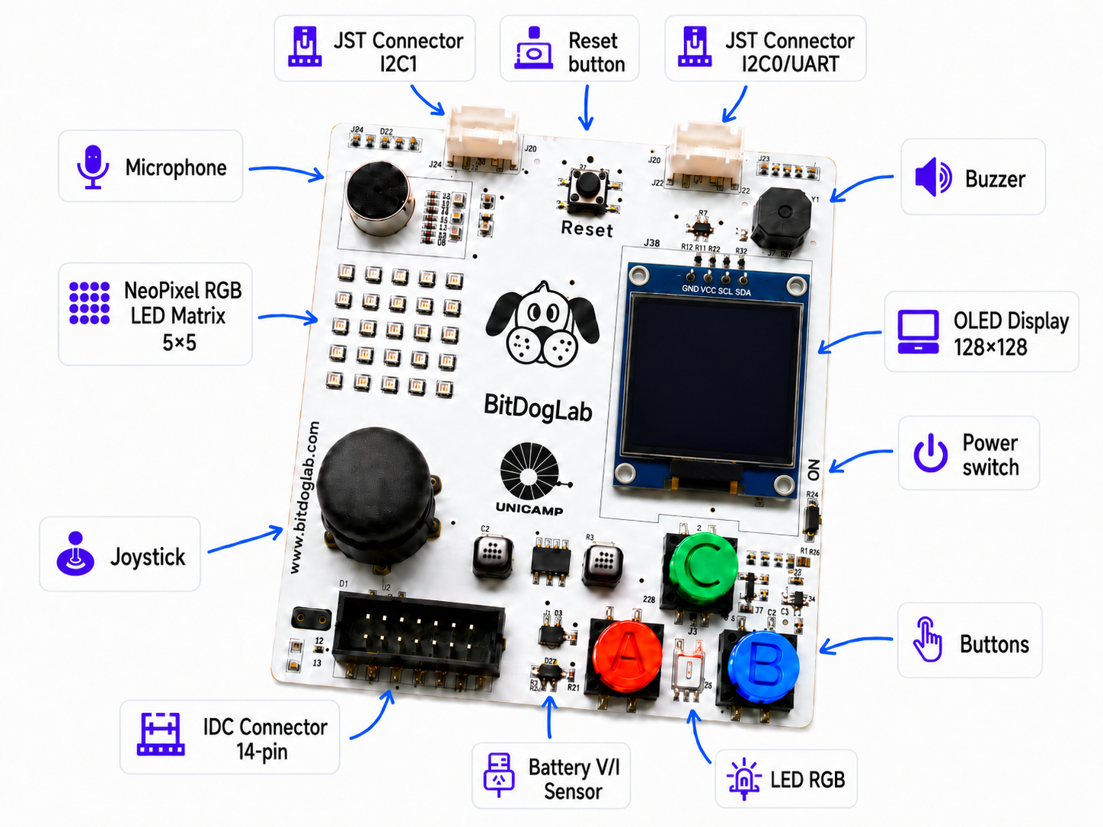
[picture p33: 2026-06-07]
images/bitdoglab figure.png

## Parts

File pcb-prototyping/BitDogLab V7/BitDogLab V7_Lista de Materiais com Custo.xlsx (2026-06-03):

Quantity | Description | Value | Fornecedor
1 | Placa BitDogLab V7 (SMD's soldados) | 120.47 | Omni Eletrônica
1 | Placa BitDogLab Placa B | ?
2 | BARRA DE PINOS - Barra de Pinos Header Fêmea SMD - 2,54mm - 20 pinos curta - Tipo 1 | 2.22 | Curto Circuito
1 | Bateria 18650 3,7V | 14.99 | Casa da Robótica
1 | Suporte para Bateria 18650 SMT - PCI | 20.55 | A.C. Compcell
1 | Múdulo de Carga Bateria | 36.67 | Nilson Benatto
1 | Joystick Analógico (Resistivo e de Efeito Hall) | 11.90 | Cinestec
1 | Raspberry Pi Pico Rp2040 | 30.00 | Mercado Livre
1 | Módulo de Microfone | 11.90 | Cinestec
1 | Display OLED '0.96" 128 X 64 | 19.90 | Cinestec
2 | Conector JST 4 Pinos | 0.80 | Cinestec
 | Total | 269.40

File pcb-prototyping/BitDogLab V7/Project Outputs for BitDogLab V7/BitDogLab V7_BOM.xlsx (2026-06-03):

Designator | Quantity | Comment | Description | Footprint | LibRef | LCSC Part Name
2 | 1 | Comment |  | logo bitDog 25mm | logo bitDog 25mm
B1 | 1 | Desliga | Botão Desliga Placa | CHAVE TÁCTIL SMD 90 | Push Buttom SMD 90 graus | C393942
B2 | 1 | RESET | Botão Reset | CHAVE TÁCTIL SMD | SW-PB | C7470150
B3 | 1 | BOTÃO A | CHAVE TÁCTIL 12mm - SMD | CHAVE TÁCTIL 12mm - SMD | SW-PB | C455234
B4 | 1 | BOTÃO B | CHAVE TÁCTIL 12mm - SMD | CHAVE TÁCTIL 12mm - SMD | SW-PB | C455234
B5 | 1 | BOTÃO C | CHAVE TÁCTIL 12mm - SMD | CHAVE TÁCTIL 12mm - SMD | SW-PB | C455234
BT1 | 1 | FP-1043P-MFG | Bateria 18650 3,7V | Bateria 18650 - SMD | Battery
BZ1 | 1 | MLT-8530 | Buzzer SMD | Buzzer SMD - MLT-8530 | Buzzer | C94599
C1, C2 | 2 | Capacitor Eletrolítico SMD,D6.3xL5.4mm | Capacitor Eletrolítico 100uF SMD 6.3 x 5.4 mm | Capacitor SMD - 6.3 x 5.4mm | Cap Pol1 | C7469977
C3, C4, C5, C6, C7, C9, C10, C11, C12, C13, C14, C15, C16, C17, C18, C19, C20, C21, C22, C23, C24, C25, C26, C27, C28 | 25 | Cap | Capacitor SMD 0402 | Capacitor SMD 0402 | Cap | C105883
C8 | 1 | Cap | Capacitor SMD 0402 | Capacitor SMD 0603 | Cap | C30926
D1 | 1 | BAT54S | Diodo Schottky SOT23 | FP-6_541-5014_01-4-MFG | CMP-02539-000028-1 | C47546
D2, D3, D4, D5, D6, D7, D8, D9, D10, D11, D13, D14, D15, D16, D17, D18, D19, D20, D21, D22, D23, D24, D25, D26, D27 | 25 | XINGLIGHT XL-1615RGBC-WS2812B | LED RGB Endereçável | LED RGB - XL-1615RGBC-WS2812B | LED RGB XL-1615RGBC-WS2812B | C5349954
D12 | 1 | HL-AF-5060H271BU46FU79GC-S1-THL | LED RGB 5050 | LED RGB SMD 5050 | LED_RGB_5050 - HL-AF-5060H271BU46FU79GC-S1-THL | C2843868
J1 | 1 | IP5306 Battery Charger | Múdulo de Carga Bateria | Charger Module IP5306 | Header 6
J2 | 1 | Conector IDC | Conector IDC 14 Pinos SMT | Conector IDC 14 Pinos | Header 7X2 | C601968
J3, J4 | 2 | Header 5 | Saídas de Expansão | HDR1X5 | Header 5
J5, J6 | 2 | Header 4 | Header, 4-Pin | Connector XH 1x4 | Header 4
J7 | 1 | KRE | Entrada Bateria Externa | HDR1X2 3D Macho | Header 2
J8 | 1 | Header 3 | Saída LED Endereçáveis | HDR1x3 3D Macho | Header 3
JP1 | 1 | Jumper | Liga Microfone | HDR1x3 3D Macho | Jumper
Q1, Q2, Q3 | 3 | DMG2305UX-7 | MOSFET P-CH 20V 4.2A SOT23 | FP-SOT23-IPC_B | CMP-1693-00002-4 | C150470
Q4 | 1 | BC817 | General Purpose Transistor, NPN Silicon, 3-Pin SOT-23, Pb-Free, Tape and Reel | ONSC-SOT-23-3-318-08_V | CMP-1048-00736-1 | C52801
R1, R6, R7, R8 | 4 | 10K | RES Thick Film, 10kΩ, 1%, 0.1W, 100ppm/°C, 0603 | FP-CRCW0603-e3-IPC_C | CMP-2000-03059-2 | C98220
R2 | 1 | 0R1 | RES 0.1 OHM 1% 1W 2512 | FP-RL2512-MFG | CMP-03412-013102-1 | C160587
R3, R4 | 2 | 100K | RES Thick Film, 100kΩ, 1%, 0.1W, 100ppm/°C, 0603 | FP-CRCW0603-e3-IPC_C | CMP-2000-03059-2 | C25803
R5 | 1 | 330R | RES Thick Film, 330Ω, 1%, 0.1W, 100ppm/°C, 0603 | FP-CRCW0603-e3-IPC_C | CMP-2000-03059-2 | C23138
R9, R10 | 2 | 220R | RES Thick Film, 220Ω, 1%, 0.1W, 100ppm/°C, 0603 | FP-CRCW0603-e3-IPC_C | CMP-2000-03059-2 | C2907014
R11 | 1 | 150R | RES Thick Film, 150Ω, 1%, 0.1W, 100ppm/°C, 0603 | FP-CRCW0603-e3-IPC_C | CMP-2000-03059-2 | C2907103
U1 | 1 | LM1117MP-3.3/NOPB | 800mA Low-Dropout Linear Regulator, 4-pin SOT-223, Pb-Free | DCY0004A_L | CMP-0062-01638-4 | C9662
U2 | 1 | INA226 - Power Meter I2C | Ultra-Precise I2C Output Current, Voltage, and Power Monitor | MSOP 10 Pinos | INA226 | C49851
U3 | 1 | JoyStick 2 Eixos COM-09032 | Joystick Analógico (Resistivo e de Efeito Hall) | JoyStick PCB - PS5 3.0 | JoyStick COM-09032
U4 | 1 | Raspberry Pi Pico | RP2040 Raspberry Pi Pico - ARMÂ® CortexÂ®-M0+ MCU 32-Bit Embedded Evaluation Board | Raspberry Pi Pico W - Header SMD Tipo 1 e 2 | Raspberry Pi Pico W
U5 | 1 | Mic MAX4466 | Módulo de Microfone | MAX4466 | MAX4466 - Módulo Microfone
U6 | 1 | SSD1306 | 0.96" 128 X 64 MONOCHROME GRAPHIC OLED DISPLAY MODULE - I2C | DISPLAY OLED 128x128 e 128x64 | SSD1306 - DISPLAY OLED

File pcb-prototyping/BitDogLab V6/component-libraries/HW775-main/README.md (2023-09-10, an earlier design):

# HW775
Item Type: Lipo Battery Module
Material: ABS + Chip
Input Voltage: DC 4.65V-5.5V
Overcharge Protection Voltage: 4.2V±1%
Overdischarge Protection Voltage: 3±1%V
Charging Current: 0-2.1A
Discharge Current: 0-2.4A
Output Voltage: 5V
Input Protection: Over Current, Over Voltage, Short Circuit Protection

https://fr.aliexpress.com/item/32986237635.html
3D files (STEP and Solidworks) + KICAD LIB/Footprint



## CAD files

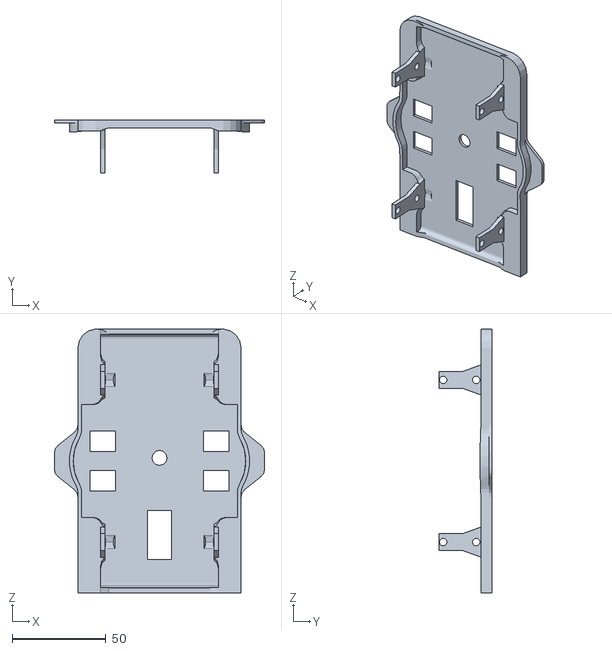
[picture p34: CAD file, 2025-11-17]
projects/hardware-expansion/RoboMovel/cad_impressao3d/ABS_1.0070_chassis_para_4x4_v4.STL
112.3 x 28.5 x 141.0

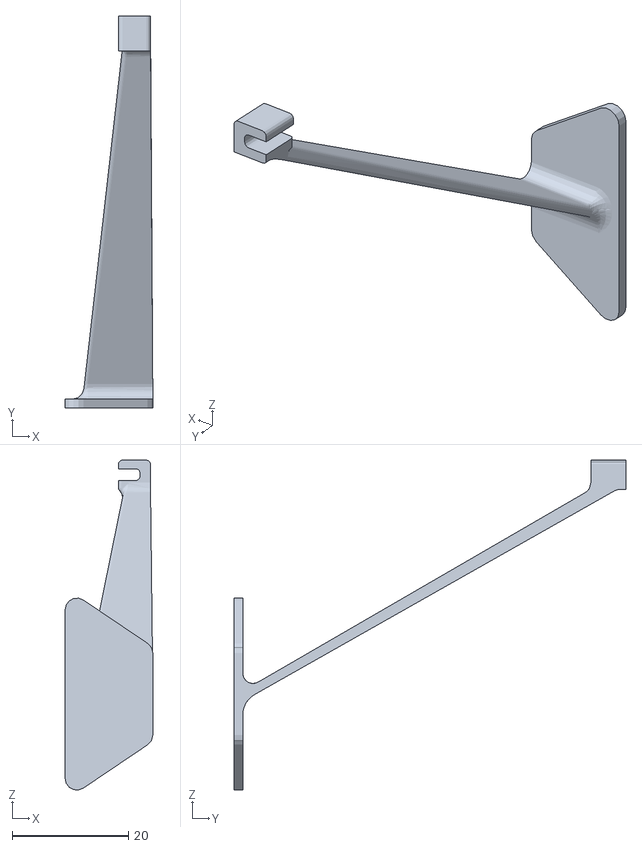
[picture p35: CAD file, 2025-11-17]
projects/hardware-expansion/RoboMovel/cad_impressao3d/suporteBitDog_MaoFrancesa_v3_ladoB.STL
15.1 x 67.5 x 56.8

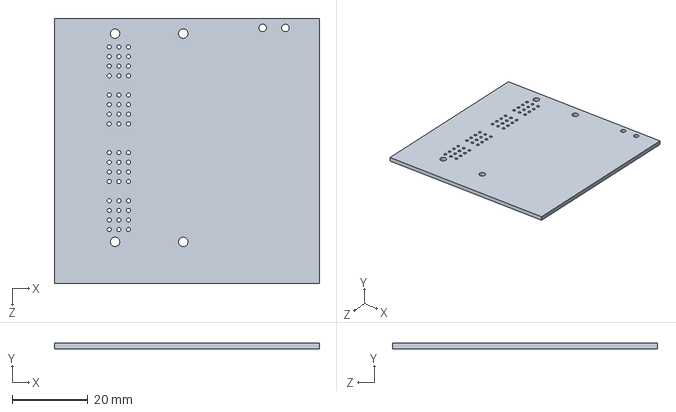
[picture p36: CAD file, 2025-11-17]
projects/hardware-expansion/RoboMovel/cad_impressao3d/PCB_4steer_Arthur.SLDPRT
70.0 x 1.50 x 70.0 mm

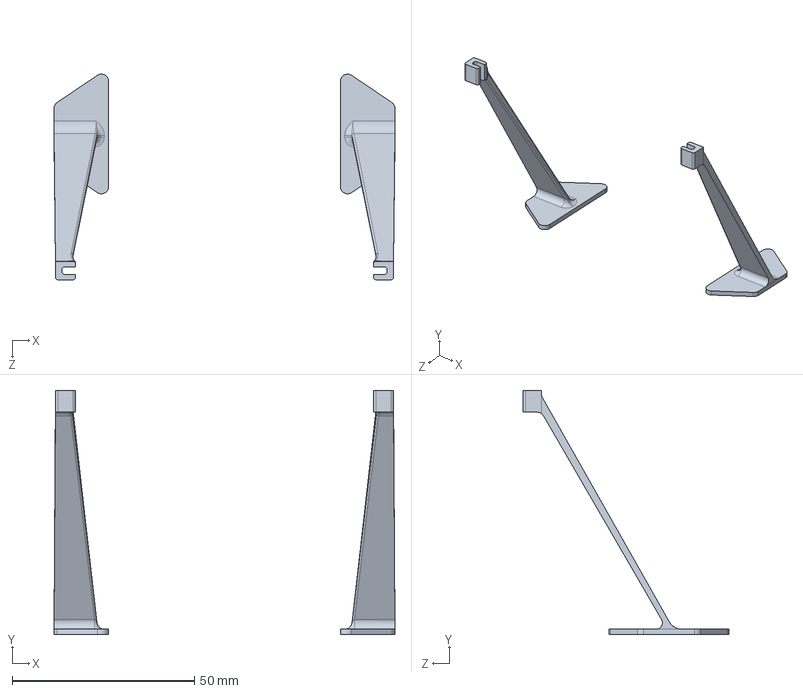
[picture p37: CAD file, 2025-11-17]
projects/hardware-expansion/RoboMovel/cad_impressao3d/suporteBitDog_MaoFrancesa_v3.SLDPRT
93.5 x 67.0 x 56.4 mm

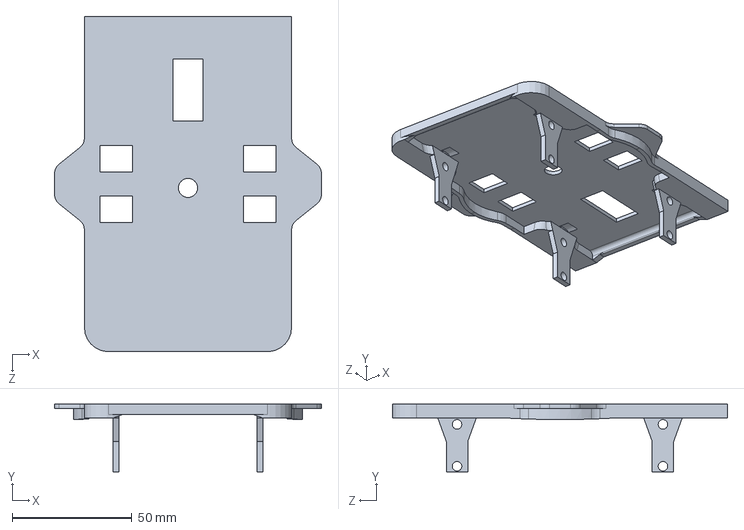
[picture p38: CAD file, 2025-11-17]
projects/hardware-expansion/RoboMovel/cad_impressao3d/chassis_para_4x4_v4.SLDPRT
111.5 x 28.3 x 140.0 mm

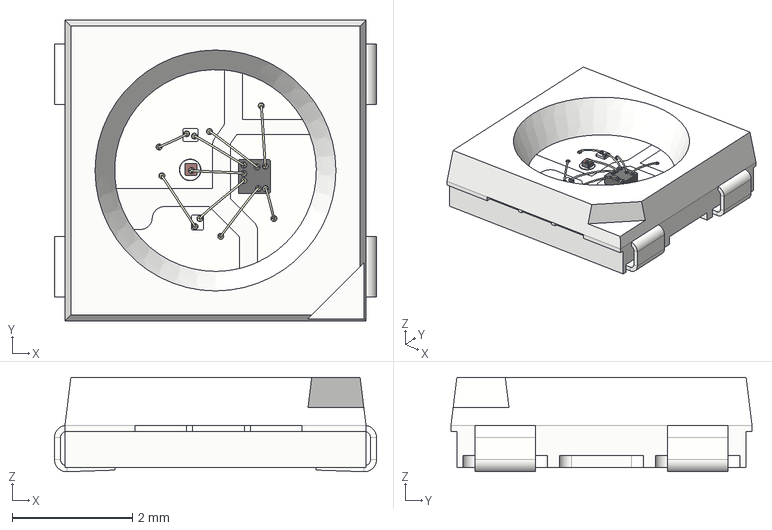
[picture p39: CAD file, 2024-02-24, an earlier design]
pcb-prototyping/BitDogLab V6/bitdoglab-smd/bitdoglab_main/3D/3D_1/WS2812B.step
5.35 x 5.00 x 1.57 mm

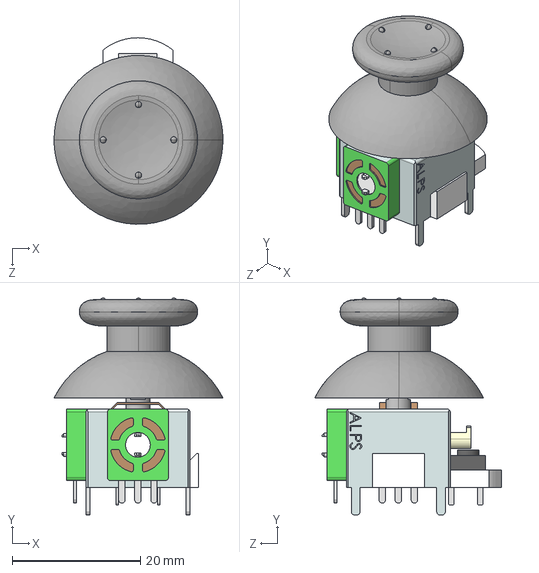
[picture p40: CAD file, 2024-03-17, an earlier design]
pcb-prototyping/BitDogLab V6/bitdoglab-smd/bitdoglab_main/3D/ALPS JOYSTICK.STEP
26.3 x 33.8 x 29.0 mm
User Library-Joystick_Asm_Left_Joystick_b
User Library-alps joystick module

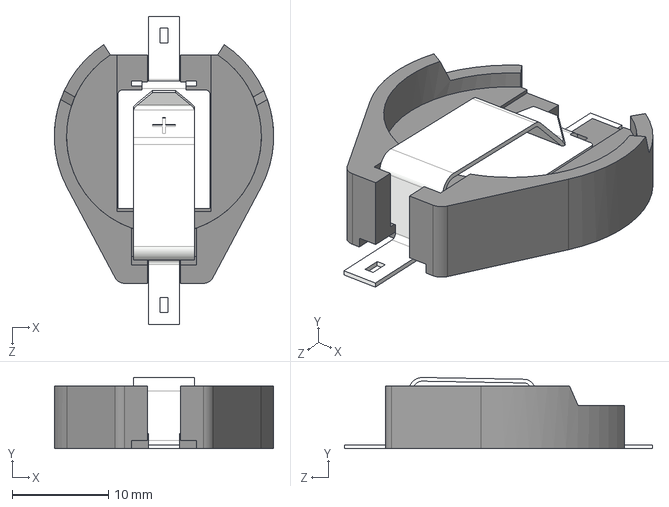
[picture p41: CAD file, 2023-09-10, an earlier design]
pcb-prototyping/BitDogLab V6/component-libraries/1063/1063.step
22.7 x 7.37 x 31.9 mm

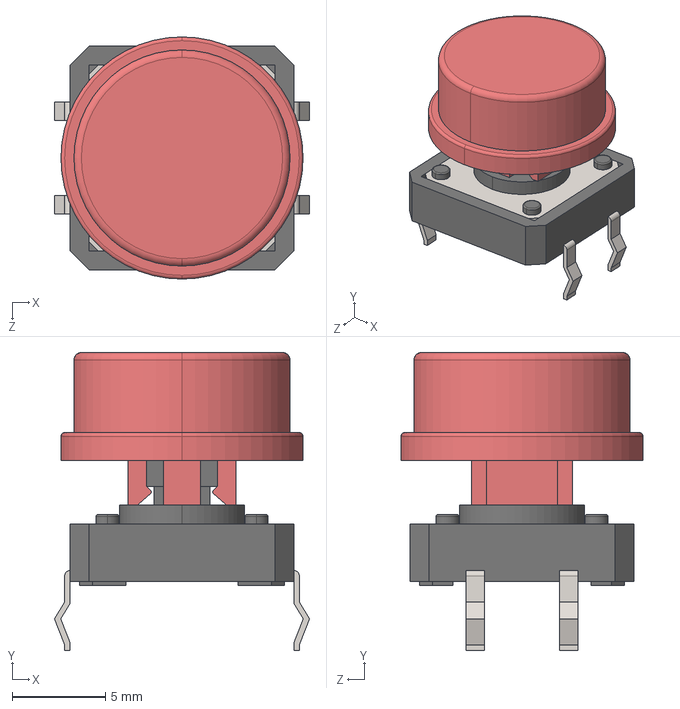
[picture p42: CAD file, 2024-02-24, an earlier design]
pcb-prototyping/BitDogLab V6/component-libraries/12mm Push Button with Cap.STEP
13.7 x 16.0 x 13.0 mm
12mm Push Button
12mm Push Button Cap

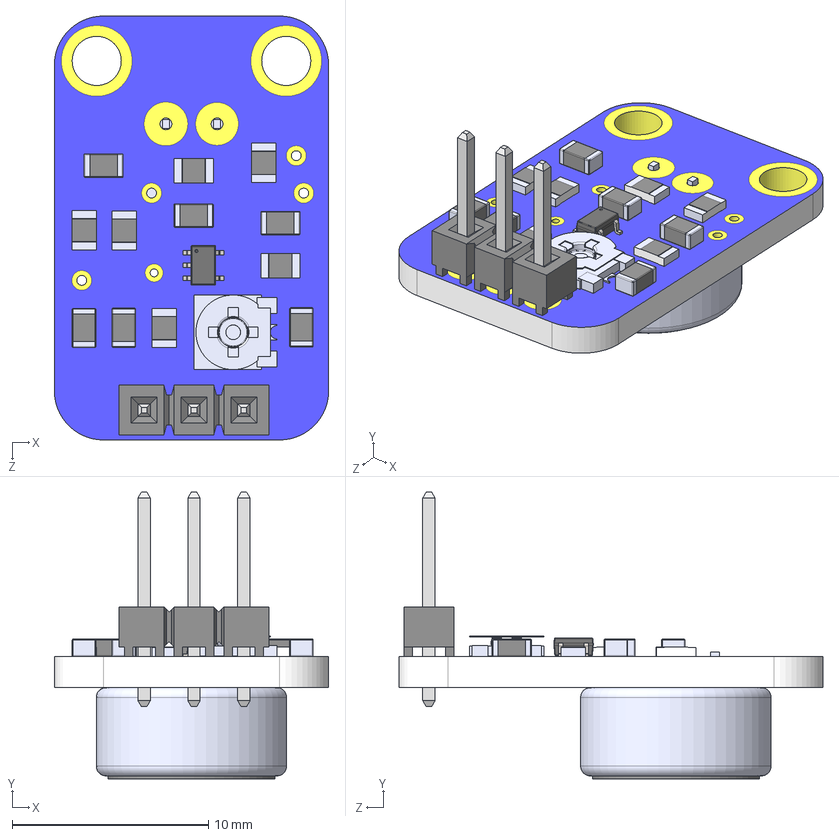
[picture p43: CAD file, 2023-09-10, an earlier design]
pcb-prototyping/BitDogLab V6/component-libraries/adafruit-max4466-module-1.snapshot.5/Max4466.STEP
14.0 x 14.6 x 21.6 mm

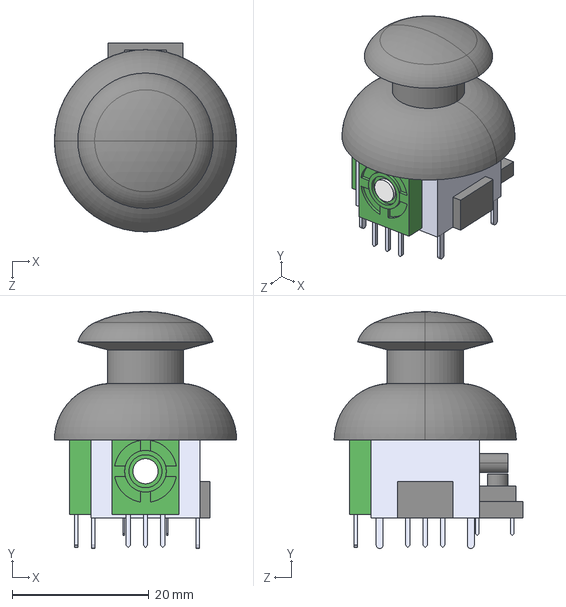
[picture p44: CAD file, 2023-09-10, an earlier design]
pcb-prototyping/BitDogLab V6/component-libraries/COM-09032/COM-09032.step
26.7 x 34.7 x 27.6 mm

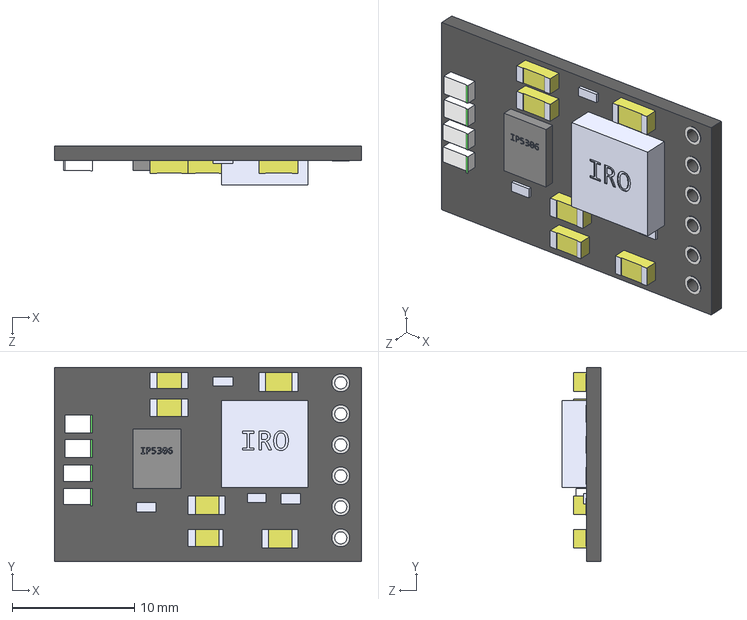
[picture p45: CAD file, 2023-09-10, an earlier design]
pcb-prototyping/BitDogLab V6/component-libraries/hw-775-lipo-module-1.snapshot.2/charger2ANewCS.STEP
25.2 x 15.9 x 3.20 mm

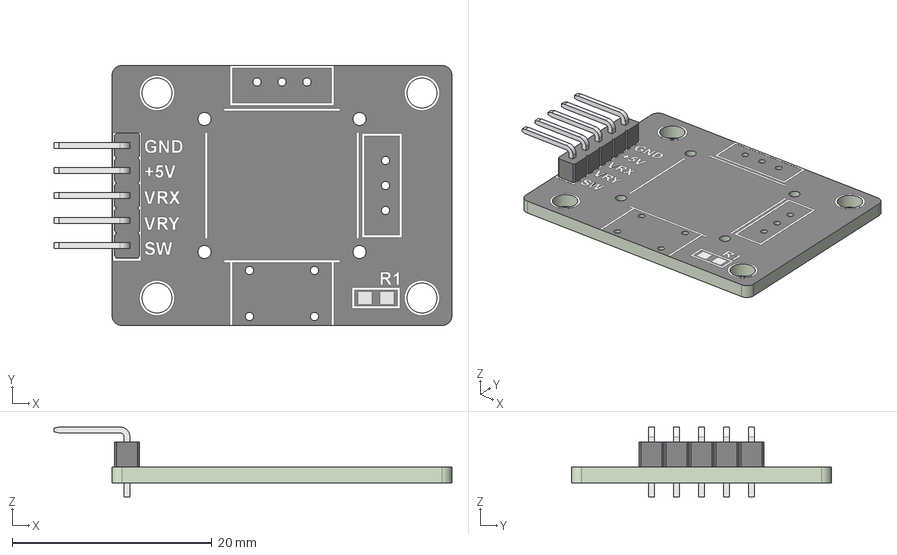
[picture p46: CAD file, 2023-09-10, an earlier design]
pcb-prototyping/BitDogLab V6/component-libraries/ky-023-joystick-module-1.snapshot.4/Base-Board.step
39.8 x 26.0 x 7.00 mm
PCB
5x_Ang_Conn

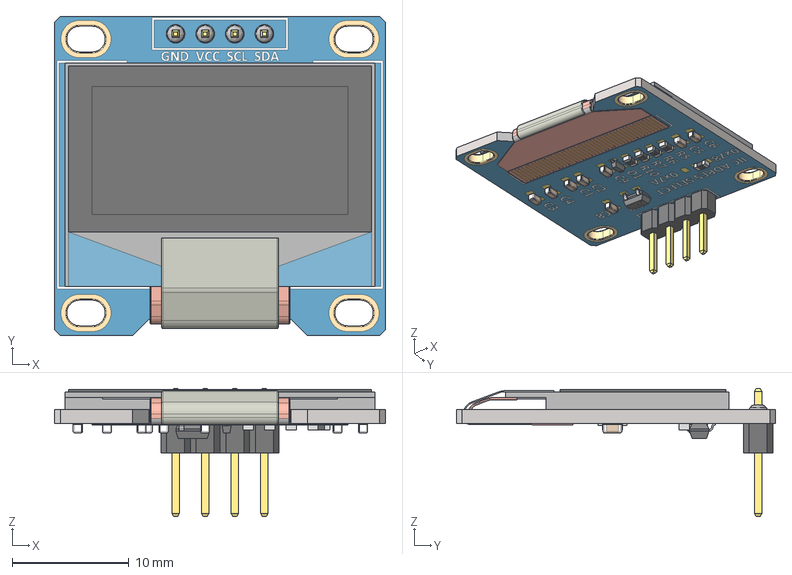
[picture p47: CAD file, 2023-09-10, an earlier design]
pcb-prototyping/BitDogLab V6/component-libraries/pantalla-oled-0-96-128x64-1.snapshot.7/Pantalla OLED 0.96'' 128x64.stp
28.4 x 27.4 x 11.0 mm
SOT-23_TOR
RES_CR16_MTK_1 x 4
RES_CR16_MTK
SOD323F_DIO

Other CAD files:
projects/hardware-expansion/RoboMovel/cad_impressao3d/suporteBitDog_MaoFrancesa_v3_ladoA.STL
pcb-prototyping/BitDogLab V6/component-libraries/HW775-main/charger2A.STEP
pcb-prototyping/BitDogLab V6/component-libraries/ws2812b-rgb-led-adafruit-neopixel-1.snapshot.9/WS2812_RGB_LED_updated.stp
pcb-prototyping/BitDogLab V6/bitdoglab-smd/bitdoglab_main/3D/3D_1/mypushbutton.stp
pcb-prototyping/BitDogLab V6/bitdoglab-smd/bitdoglab_main/3D/0603 Chip SMD LED (1.6x0.8mm).STEP
pcb-prototyping/BitDogLab V6/bitdoglab-smd/bitdoglab_main/3D/18650 Battery and Holder 02 v2.step
pcb-prototyping/BitDogLab V6/bitdoglab-smd/bitdoglab_main/3D/2x6 shrouded header v2.step
pcb-prototyping/BitDogLab V6/bitdoglab-smd/bitdoglab_main/3D/3D_1/0603 Chip SMD LED (1.6x0.8mm) - Copia.STEP
pcb-prototyping/BitDogLab V6/bitdoglab-smd/bitdoglab_main/3D/3D_1/0603 Chip SMD LED (1.6x0.8mm).STEP
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

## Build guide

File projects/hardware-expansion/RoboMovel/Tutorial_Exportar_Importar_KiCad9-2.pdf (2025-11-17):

# Tutorial: Exportar e Importar Projetos no KiCad 9 (Incluindo Bibliotecas)

Este tutorial ensina passo a passo como exportar e importar projetos no KiCad 9.0 de forma correta, garantindo que esquemáticos, PCBs, bibliotecas personalizadas e modelos 3D sejam transferidos entre computadores ou usuários sem problemas.

### 📤 1. EXPORTANDO O PROJETO (Máquina de origem)

Etapa 1: Organize seu projeto
1. Abra o projeto no KiCad 9.
2. Vá em Preferências → Configurar os caminhos e verifique se os caminhos relativos estão corretos.

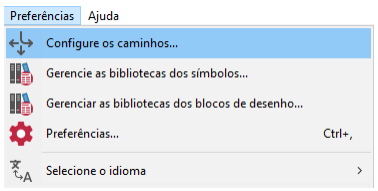
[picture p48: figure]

3. Se os caminhos não estiverem corretos, deixe nesse padrão, substituindo para as suas pastas de biblioteca:

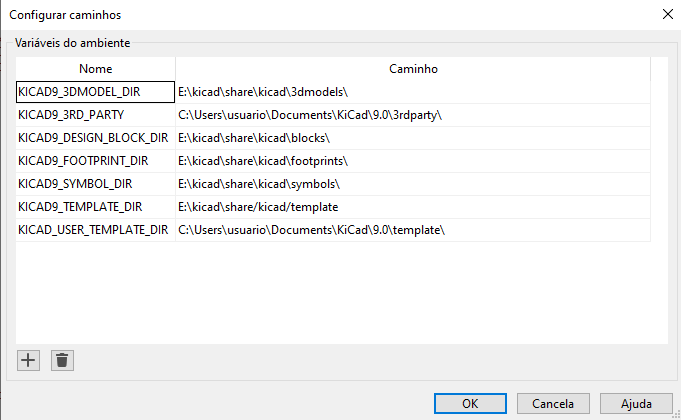
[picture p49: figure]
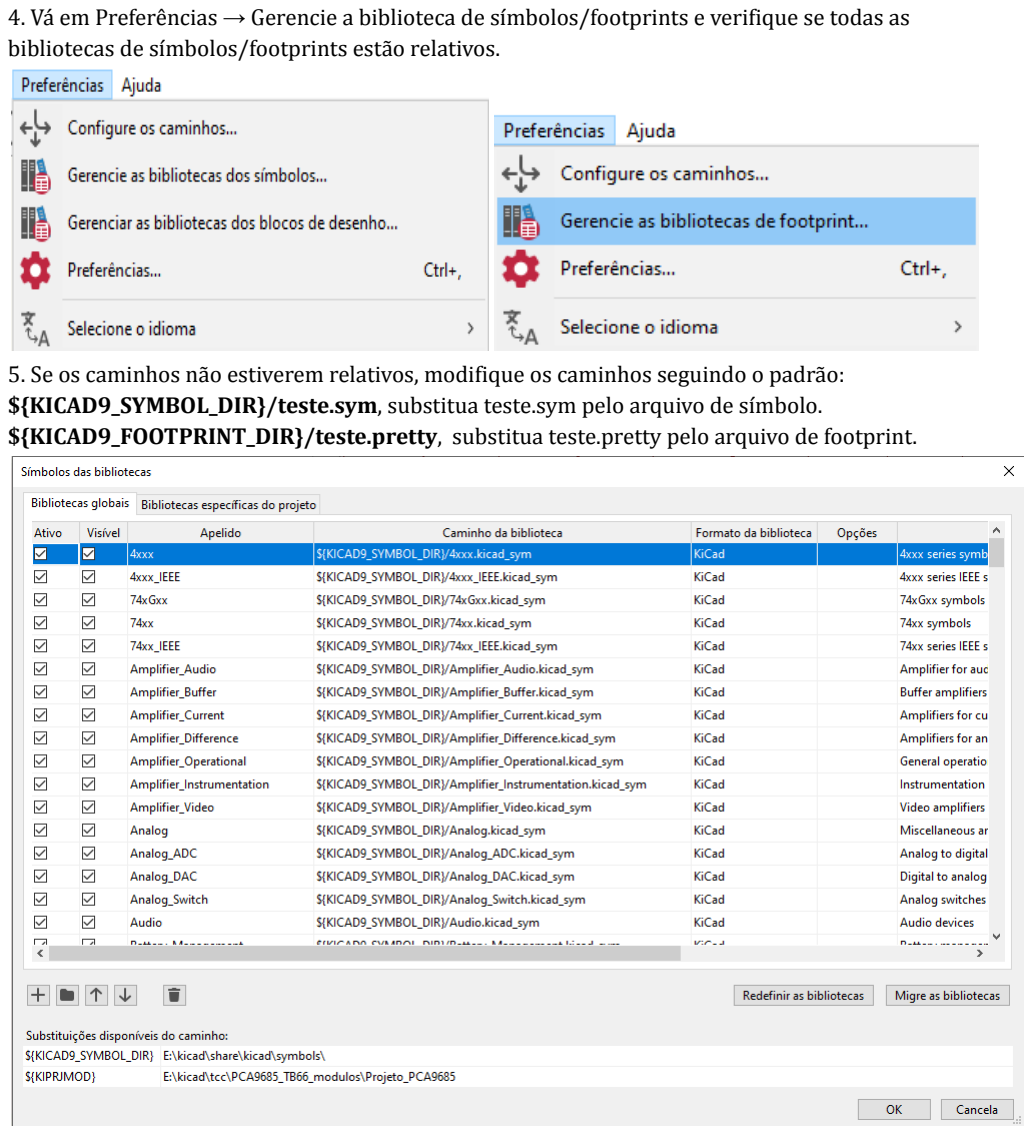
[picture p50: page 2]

4. Vá em Preferências → Gerencie a biblioteca de símbolos/footprints e verifique se todas as bibliotecas de símbolos/footprints estão relativos.
5. Se os caminhos não estiverem relativos, modifique os caminhos seguindo o padrão: ${KICAD9_SYMBOL_DIR}/teste.sym, substitua teste.sym pelo arquivo de símbolo. ${KICAD9_FOOTPRINT_DIR}/teste.pretty, substitua teste.pretty pelo arquivo de footprint.

6.. Copie todas as bibliotecas externas para dentro da pasta do projeto, por exemplo: MeuProjeto/
├─ MeuProjeto.kicad_pro
├─ schematic/
├─ pcb/
├─ libs/
│ ├─ simbolos.kicad_sym
│ ├─ footprints.pretty/
│ └─ 3dmodels/

Etapa 2: Inclua bibliotecas personalizadas
- Símbolos: Copie os arquivos .sym usados no projeto para a pasta libs.
- Footprints: Copie as pastas .pretty para libs.

Etapa 3: Compacte o projeto

1. Selecione a pasta do projeto
2. Clique com o botão direito e escolha 'Enviar para → Pasta compactada (.zip)'.
3. Coloque a pasta libs na pasta compactada.
4. O arquivo .zip gerado pode ser enviado para outra máquina.

📥 2. IMPORTANDO O PROJETO (Máquina de destino)

Etapa 1: Extraia o projeto
1. Copie o arquivo .zip para o novo computador.
2. Extraia para uma pasta local.
3. A estrutura de pastas deve permanecer organizada, incluindo libs.

Etapa 2: Ajuste biblioteca de símbolos
1. Coloque o arquivo .sym em kicad→share→kicad→symbols.
2. Abra o schematic no KiCad.
3. Vá na aba Preferências → Gerencie a biblioteca de símbolos.

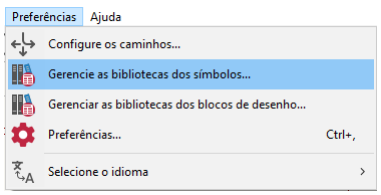
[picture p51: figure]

4. Adicione uma linha vazia à tabela, clicando no símbolo de mais no final da página.
5. Dê um apelido ao símbolo e indique o caminho relativo do .sym da biblioteca (adicione “${KICAD9_SYMBOL_DIR}/ “antes do nome do .sym) e confirme as alterações .

Etapa 3: Ajuste biblioteca de símbolos
1. Coloque o arquivo .pretty em kicad→share→kicad→footprints.
2. Abra o pcb no KiCad.
3. Vá na aba Preferências → Gerencie a biblioteca de footprint.

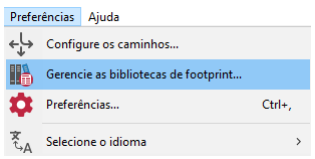
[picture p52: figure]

4. Adicione uma linha vazia à tabela, clicando no símbolo de mais no final da página.
5. Dê um apelido ao símbolo e indique o caminho relativo do .pretty da biblioteca (adicione “${KICAD9_FOOTPRINT_DIR}/ “antes do nome do .pretty) e confirme as alterações .

### 🧪 3. TESTE FINAL

1. Abra o esquemático e verifique se têm símbolos quebrados
2. Vá na aba Ferramentas→Atualize a PCI a partir do esquema

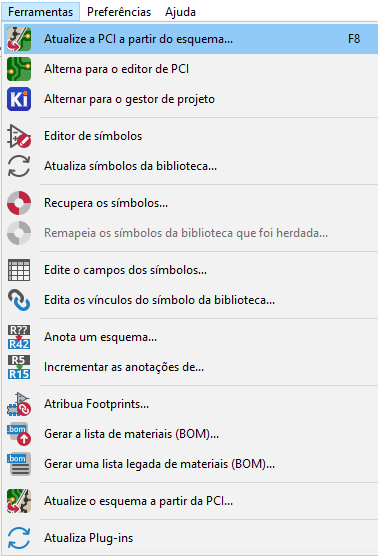
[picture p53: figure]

3. Verifique se não aparece erros e aperte o botão atualiza a PCI. Verifique se todos os componentes aparecem na PCI.
4. Se não aparecer o componente na PCI, verifique se o componente está com o footprint associado à ele no schematic.
5.Para verificar se o componente está associado à um componente, abra o schematic, clique com o botão direito sobre o componente e abra a aba propriedades

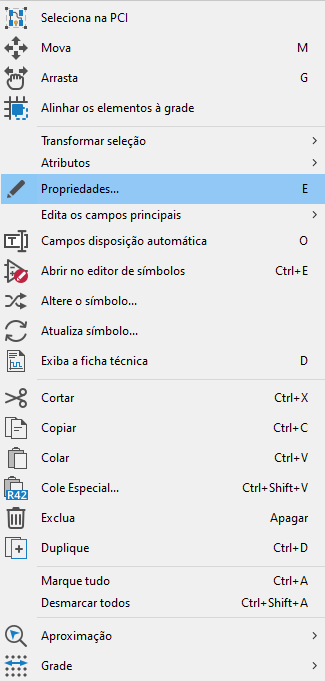
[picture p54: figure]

6. Na linha footprint, selecione o footprint do componente e salve as alterações.

### ✨ Dica Extra: Função “Archive Project”

O KiCad 9 possui a função Projeto → Archive Project, que cria um .zip com todos os arquivos e bibliotecas usadas automaticamente. Na máquina de destino, basta descompactar e abrir.

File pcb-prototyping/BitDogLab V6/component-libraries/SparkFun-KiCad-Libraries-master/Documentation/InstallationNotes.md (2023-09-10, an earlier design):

Installation Notes
----------------

* [The KiCad site](http://kicad.org/)

**KiCad installation**

* Uninstall previous versions of KiCad
* Download KiCad stable version 4.0.5 from [http://kicad.org/download/](http://kicad.org/download/windows/) and install
* After install, you'll be prompted to install "Wings 3D", check this box to be redirected to [http://www.wings3d.com/](http://www.wings3d.com/)
* Download and install the stable release 2.1.5

**Using the libraries**

* Create a local project (this is necessary because projects hold library path information)
* Open the "Schematic Library Editor"
* Prefrences -> Component Libraries
  * Remove all libraries from list
  * Add -> navigate to SparkFun-KiCad-Libraries -> select all .lib files -> open, then hit OK
  * Test by selecting an active library.  All sparkfun libraries should be displayed.  Close the library editor
* Open the "PCB Footprint Editor"
* Preferences -> Footprint Library Manager
  * Remove all (if any) libraries, hit OK
* Preferences -> Footprint Libraries Wizard
  * Next (files on my computer)
  * Navigate to SparkFun-KiCad-Libraries -> select all .mod files and hit ok
  * Next
  * Select for this project only
  * Next
  * Close the editor
* Save the project (Green arrow into extern HDD icon, no menu exists)

Now, this project is linked to the libraries.  Open a schematic and place components.  See KiCad enginursday post for converting from schematic into board (Note: You need to have nets for this to work... not just unconnected components)

**License Information**

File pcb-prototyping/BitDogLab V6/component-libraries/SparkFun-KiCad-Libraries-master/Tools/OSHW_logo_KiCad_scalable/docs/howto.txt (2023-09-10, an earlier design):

How to make your own:
---------------------

Watch / read this first:

* http://www.kicad.org/display/KICAD/Videos+by+zupnikal
  * PCB layout with KiCad => https://www.youtube.com/playlist?list=PL67B2290F4C62B5F2
    * KiCad #1 - Mounting hole clearance and cut-out zone in the copper pour
    * KiCad #2 - Solder mask clearance
    * KiCad #3 - Using 'FreeRoute' to create a simple board
    * KiCad #4 - Adding the OSHW logo to your layout
    * KiCad #5 - Using custom logos in your design

The last two videos should be helpful for how to create a custom .emp file from images.

* http://www.re-innovation.co.uk/web12/index.php/en/blog-75/230-adding-logo-to-kicad

If you use linux (which you should), you don't have to use the online-scaler. Just use the scripts!

---

* Create a folder to hold your new footprint library.
* Copy the scripts 'make_lib.sh' and 'scale.pl' into that folder.
* Make sure these files are executable (chmod u+x ...).
* Copy your custom .emp file into that foler.

* Run the 'make_lib.sh' script as follows:

./make_lib.sh input-file.emp lib-name.mod START END

START and END are placeholders for positive integer numbers (1,2,3...) that determine
the range of created footprint sizes. The units are metric (mm).

The 'lib-name.mod' file will show up in the 'lib' sub-folder. Add it to your pcbnew
library settings as usual.

Footprints that are created for back-layers are automagically mirrored horizontally.
To place them onto a back-layer, hover the mouse-pointer over them and press 'f' for 'flip'.

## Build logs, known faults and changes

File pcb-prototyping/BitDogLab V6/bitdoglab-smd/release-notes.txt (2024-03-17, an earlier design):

Atual V5.3
* Divido em 2 PCBs: painel e main
* Inclusão de resistor de carga (100 ohm) para evitar IP5306 entrando no modo auto standby para baixas cargas de consumo
* Adição do joystick direto na placa (invés do módulo como era antes)
* Incluso mais dois pinos guias para o componente joystick (necessário para bater footprint com componente real)
* Inversão do 3D dos conectores de sensores i2c
* Corrigido tamanho do furo do painel
* Preenchido com silkscreen embaixo da rapsberry pi pico (isolamento pré-solda)
* Adicionar um segundo footprint para o botão de reset para termos opção tanto pth quanto smd
* Aumentar diâmetro do furo do microfone de 0.5mm para 0.7mm
* Retirada metalização dos 2 furos guias das Chave Táctil Botão A e B

Futuro V5.4
* Trocar IP5306 por IP5306-I2C (i2c - RPi, sem leds, api com oled para mostrar status bateria)
* Trocar D3 de PTH para SMD
* Adicionar OLED direto na placa (flex pcb, res/cap/transistor)

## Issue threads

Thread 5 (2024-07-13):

Dúvidas sobre a bitdoglab [PT-BR] / Doubts about bitdoglab [ENG]

jrfo-hwit, 2024-07-13:
[PT-BR] Quaisquer dúvidas sobre o bitdoglab (hardware, firmware, software e sugestões) podem ser inseridas aqui para que a comunidade possa responder sobre.

[ENG] Any doubts about bitdoglab (hardware, firmware, software and suggestions) can be inserted here in order that the community could answer.

@Fruett @pedrodsk @samufraga @hbauer-wc @lroliver03 [PT-BR] e qualquer outro membro da comunidade podem responder e discutir sobre / [ENG] and any other community member could answer and discuss about it.

Aulo007, 2025-01-09:
Onde posso baixar os drivers dessa placa? Não aparece quando a conecto via usb no computador.

pedrodsk, 2025-01-09:
Olá, você baixou e instalou o firmware pelo método descrito aqui no github? Depois basta configurar o Thonny para iniciar a comunicação com a placa.

jrfo-hwit, 2025-01-09:
Se estiver usando MicroPython siga os passos desse link do GitHub: https://github.com/BitDogLab/BitDogLab/tree/main/doc#iniciando-com-micropython

Get Outlook for iOS<https://aka.ms/o0ukef>
________________________________
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

jrfo-hwit, 2025-01-09:
Adicionalmente, só vai aparecer o drive no computador se vc ligar o cabo segurando o botão de boot (esse passo é muito usado para gravar o firmware c/c++), segue o link: https://github.com/BitDogLab/BitDogLab/tree/main/doc#gravação-do-firmware

Get Outlook for iOS<https://aka.ms/o0ukef>
________________________________
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

jrfo-hwit, 2025-01-09:
Concluindo, não precisa de driver, tanto Windows, Linux e macos possuem esse driver nativamente, para aparecer o drive eh basicamente ligar com o botão de boot segurado como mostrado na mensagem anterior

Get Outlook for iOS<https://aka.ms/o0ukef>
________________________________
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

Aulo007, 2025-01-09:
Opa, boa noite! A minha dificuldade está sendo exatamente essa: eu seguro o botão de boot e, em seguida, conecto o cabo na placa, mas não aparece nada no meu computador. Por isso, tentei buscar uma forma de instalar esses drivers manualmente, pois estou participando de uma capacitação que utiliza uma placa dessas e o RPI-RP2 não aparece ao realizar o procedimento. Ela liga quando conecto o micro USB nela, mas, mesmo assim, não aparece nada, nem no gerenciador de dispositivos.

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

jrfo-hwit, 2025-01-09:
Que computador e sistema operacional estás usando? Se for Windows usamos a versão 11.

Get Outlook for iOS<https://aka.ms/o0ukef>
________________________________
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

Aulo007, 2025-01-09:
Estou usando o windows 10

jrfo-hwit, 2025-01-09:
Você consegue abrir o gerenciador de dispositivos e ver se tem algum dispositivo com esse ícone da janela abaixo?

Get Outlook for iOS<https://aka.ms/o0ukef>
________________________________
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

Aulo007, 2025-01-09:
Consigo

jrfo-hwit, 2025-01-09:
Você consegue tentar instalar o driver zadig desse tutorial? https://blog.iothook.com/2023/09/raspberry-pi-pico-w-windows-10-driver.html?m=1

Driver : https://github.com/pbatard/libwdi/releases/download/v1.5.0/zadig-2.8.exe

Get Outlook for iOS<https://aka.ms/o0ukef>
________________________________
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

jrfo-hwit, 2025-01-09:
Tinha esse ícone?

Get Outlook for iOS<https://aka.ms/o0ukef>
________________________________
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

Aulo007, 2025-01-09:
Não

Aulo007, 2025-01-09:
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

Aulo007, 2025-01-09:
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

jrfo-hwit, 2025-01-09:
Vc consegue instalar o driver zadig : https://github.com/pbatard/libwdi/releases/download/v1.5.1/zadig-2.9.exe

Get Outlook for iOS<https://aka.ms/o0ukef>
________________________________
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

jrfo-hwit, 2025-01-09:
Instala e tenta novamente o processo de ligar a bitdoglab com o botão de boot apertado.

https://github.com/pbatard/libwdi/releases/tag/v1.5.1

Get Outlook for iOS<https://aka.ms/o0ukef>
________________________________
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

Aulo007, 2025-01-09:
> Vc consegue instalar o driver zadig : https://github.com/pbatard/libwdi/releases/download/v1.5.1/zadig-2.9.exe Get Outlook for iOS<https://aka.ms/o0ukef>
> […](#)
> ________________________________ From: Aulo Cezar ***@***.***> Sent: Wednesday, January 8, 2025 8:15:43 PM To: BitDogLab/BitDogLab ***@***.***> Cc: Juliano Oliveira ***@***.***>; State change ***@***.***> Subject: Re: [BitDogLab/BitDogLab] Dúvidas sobre a bitdoglab [PT-BR] / Doubts about bitdoglab [ENG] (Issue #5) image.png (view on web)<https://github.com/user-attachments/assets/48b8f365-ee06-4573-a173-eb15273054d6> — Reply to this email directly, view it on GitHub<[#5 (comment)](https://github.com/BitDogLab/BitDogLab/issues/5#issuecomment-2579148274)>, or unsubscribe<https://github.com/notifications/unsubscribe-auth/BGFKCI5BDZA3A7GEPOFHKO32JXZW7AVCNFSM6AAAAABKZYDBS2VHI2DSMVQWIX3LMV43OSLTON2WKQ3PNVWWK3TUHMZDKNZZGE2DQMRXGQ>. You are receiving this because you modified the open/close state.Message ID: ***@***.***>

> Vc consegue instalar o driver zadig : https://github.com/pbatard/libwdi/releases/download/v1.5.1/zadig-2.9.exe Get Outlook for iOS<https://aka.ms/o0ukef>
> […](#)
> ________________________________ From: Aulo Cezar ***@***.***> Sent: Wednesday, January 8, 2025 8:15:43 PM To: BitDogLab/BitDogLab ***@***.***> Cc: Juliano Oliveira ***@***.***>; State change ***@***.***> Subject: Re: [BitDogLab/BitDogLab] Dúvidas sobre a bitdoglab [PT-BR] / Doubts about bitdoglab [ENG] (Issue #5) image.png (view on web)<https://github.com/user-attachments/assets/48b8f365-ee06-4573-a173-eb15273054d6> — Reply to this email directly, view it on GitHub<[#5 (comment)](https://github.com/BitDogLab/BitDogLab/issues/5#issuecomment-2579148274)>, or unsubscribe<https://github.com/notifications/unsubscribe-auth/BGFKCI5BDZA3A7GEPOFHKO32JXZW7AVCNFSM6AAAAABKZYDBS2VHI2DSMVQWIX3LMV43OSLTON2WKQ3PNVWWK3TUHMZDKNZZGE2DQMRXGQ>. You are receiving this because you modified the open/close state.Message ID: ***@***.***>

Não consigo, porque não aparece o RP2 boot interface 1 no zadig

jrfo-hwit, 2025-01-09:
Vc tentou trocar de porta USB?

Get Outlook for iOS<https://aka.ms/o0ukef>
________________________________
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

Aulo007, 2025-01-09:
Sim, tentei até mesmo um outro computador e o erro persistia

jrfo-hwit, 2025-01-09:
A sua bitdoglab chegou com um firmware de demonstração gravado certo (faz um barulho no buzzer, acende leds e lcd)?

Get Outlook for iOS<https://aka.ms/o0ukef>
________________________________
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

Aulo007, 2025-01-09:
Sim, ela chegou em perfeito estado, com todos os botões funcionais

jrfo-hwit, 2025-01-09:
Esse firmware não roda mais quando vc liga ela?

Get Outlook for iOS<https://aka.ms/o0ukef>
________________________________
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

Aulo007, 2025-01-09:
No caso o único problema até agora é que não apareceu o driver dela no gerenciador de dispositivos, e nem no zadig mesmo após sseguir as intruções de segurar o botão de boot e conectar o cabo na placa

jrfo-hwit, 2025-01-09:
Se vc não apertar o botão de boot e apenas ligar a placa, ela inicia rodando o firmware de demonstração?

Get Outlook for iOS<https://aka.ms/o0ukef>
________________________________
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

Aulo007, 2025-01-09:
Sim

jrfo-hwit, 2025-01-09:
O outro computado que vc testou era Windows 10 tbm? Tem algum pc com Windows 11 que consiga testar? Te falo isso pq todos os bitdoglab saem de fábrica gravados e para isso eles subiram o driver em um pc com Windows 11.

Get Outlook for iOS<https://aka.ms/o0ukef>
________________________________
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

Aulo007, 2025-01-09:
O outro computador que testei também era win 10, acho que pode ser isso, vou tentar atualizar a minha máquina ou procurar  uma com o windows 11 para fazer o devido teste. Obrigado pela ajuda.

jrfo-hwit, 2025-01-09:
Outro ponto, vc tá usando o cabo fornecido? Se tiver usando algum cabo diferente pode ser que esse esteja só alimentando e não com conexão de dados USB (isso ocorre bastante em cabos de carregadores de celular).

Get Outlook for iOS<https://aka.ms/o0ukef>
________________________________
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

Aulo007, 2025-01-09:
Estou usando o cabo fornecido, testei com outro por via das dúvidas, mas ocorreu o mesmo.

jrfo-hwit, 2025-01-09:
Então pode ser algum problema do Windows 10, vou procurar informações sobre, alguns institutos reportaram algo do tipo, talvez eles tenham a solução, se conseguir info relativo falo aqui. Em paralelo tenta testar em Windows 11.

Get Outlook for iOS<https://aka.ms/o0ukef>
________________________________
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

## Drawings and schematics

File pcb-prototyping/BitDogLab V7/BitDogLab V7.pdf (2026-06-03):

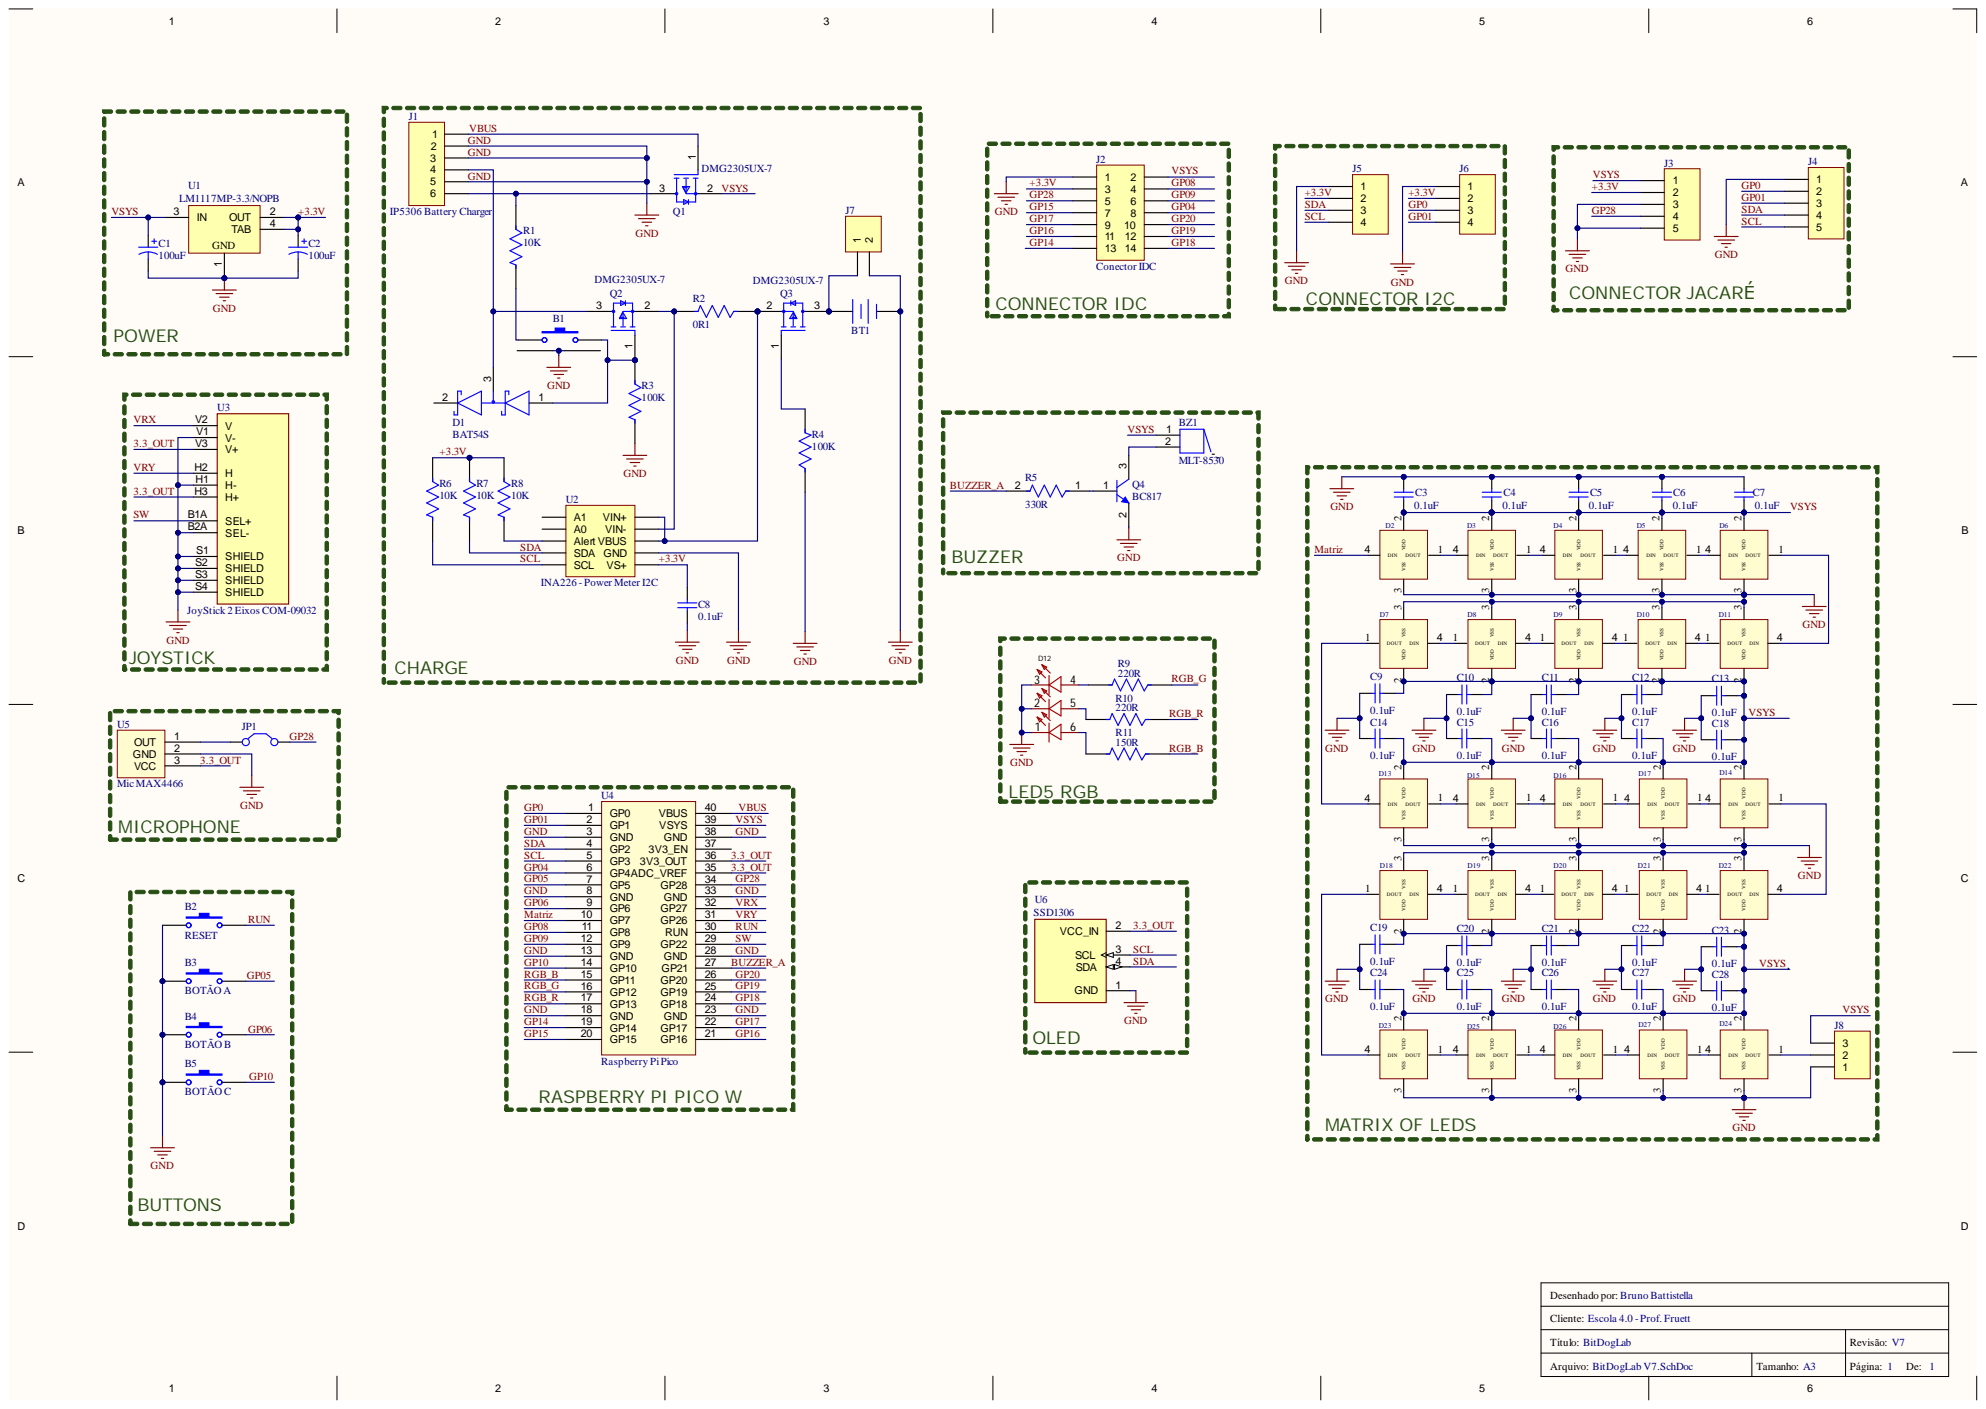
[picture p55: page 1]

GND

3.3_OUT

Título: BitDogLab | Revisão: V7

Arquivo: BitDogLab V7.SchDoc | Tamanho: A3 | Página: 1 De: 1

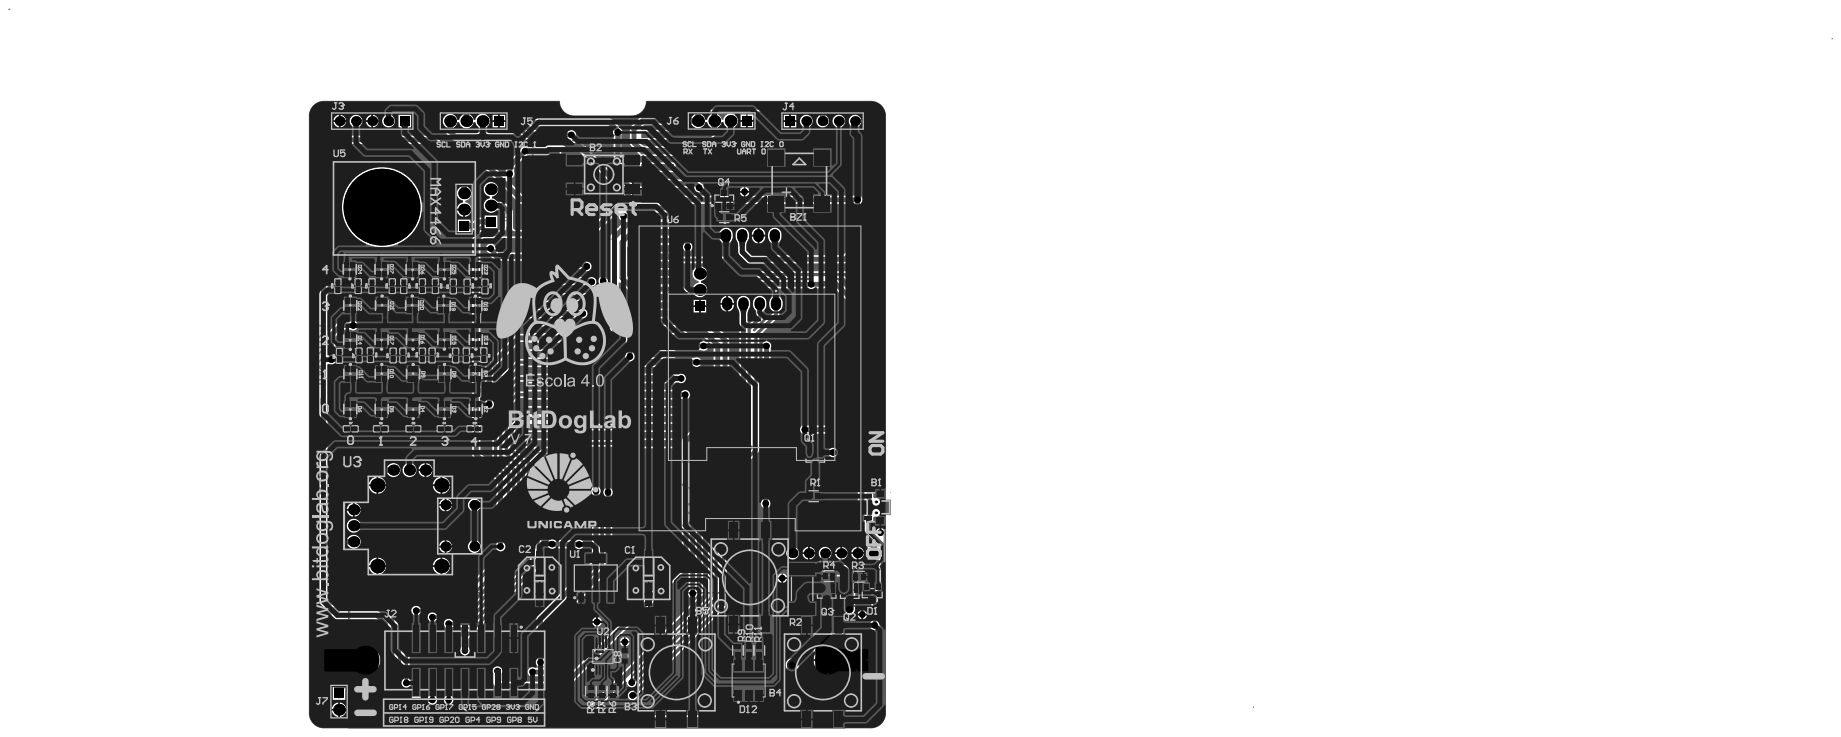
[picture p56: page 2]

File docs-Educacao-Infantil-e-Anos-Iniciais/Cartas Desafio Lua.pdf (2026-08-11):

# LUA

# LUA

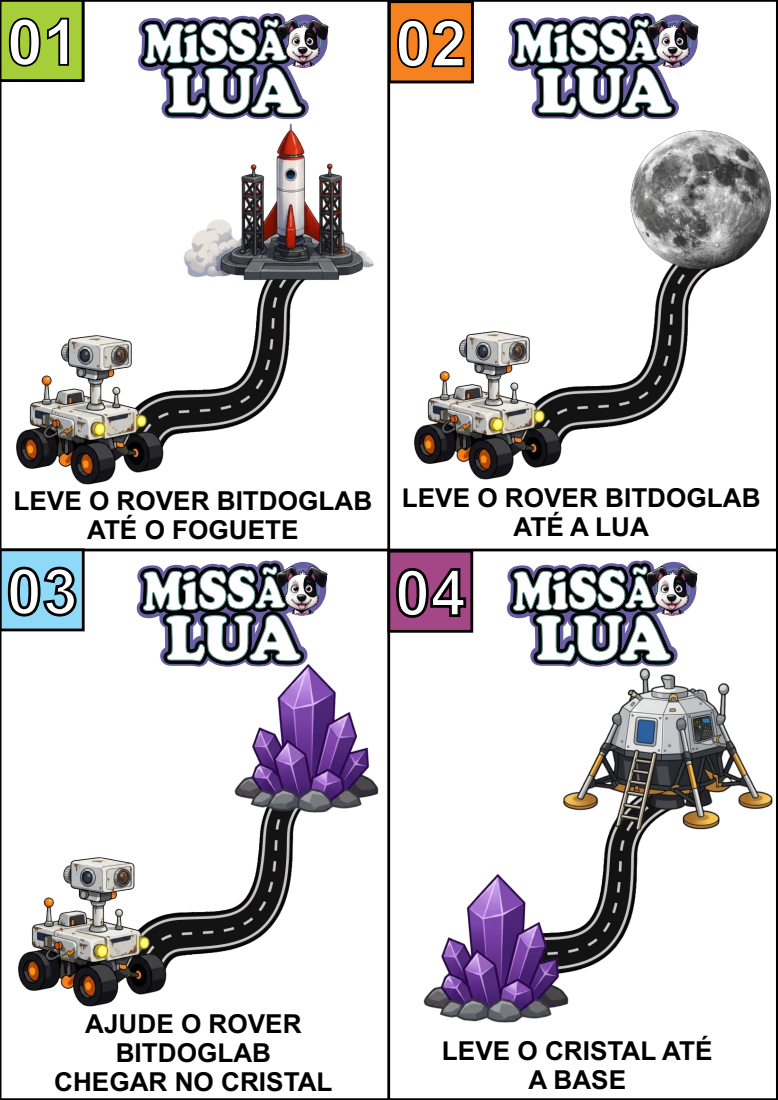
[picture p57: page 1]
ATÉ A LUA; MiSSÃO; A BASE; LUA

LEVE O ROVER BITDOGLAB
ATÉ O FOGUETE
03 04 LUA

AJUDE O ROVER
BITDOGLAB
CHEGAR NO CRISTAL

LEVE O CRISTAL ATÉ

# LUA

# LUA

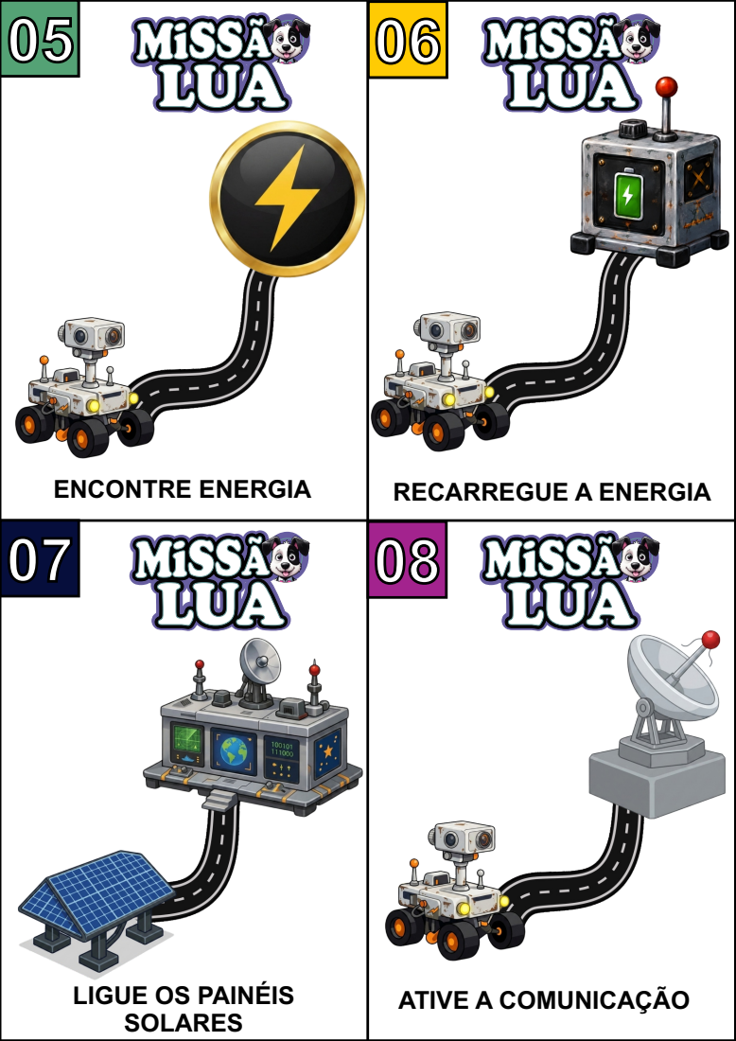
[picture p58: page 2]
ENCONTRE ENERGIA; RECARREGUE A ENERGIA; ATIVE A COMUNICAÇÃO; 07 08 LUA; MiSSÃO; LUA

LIGUE OS PAINÉIS
SOLARES

# LUA

# LUA

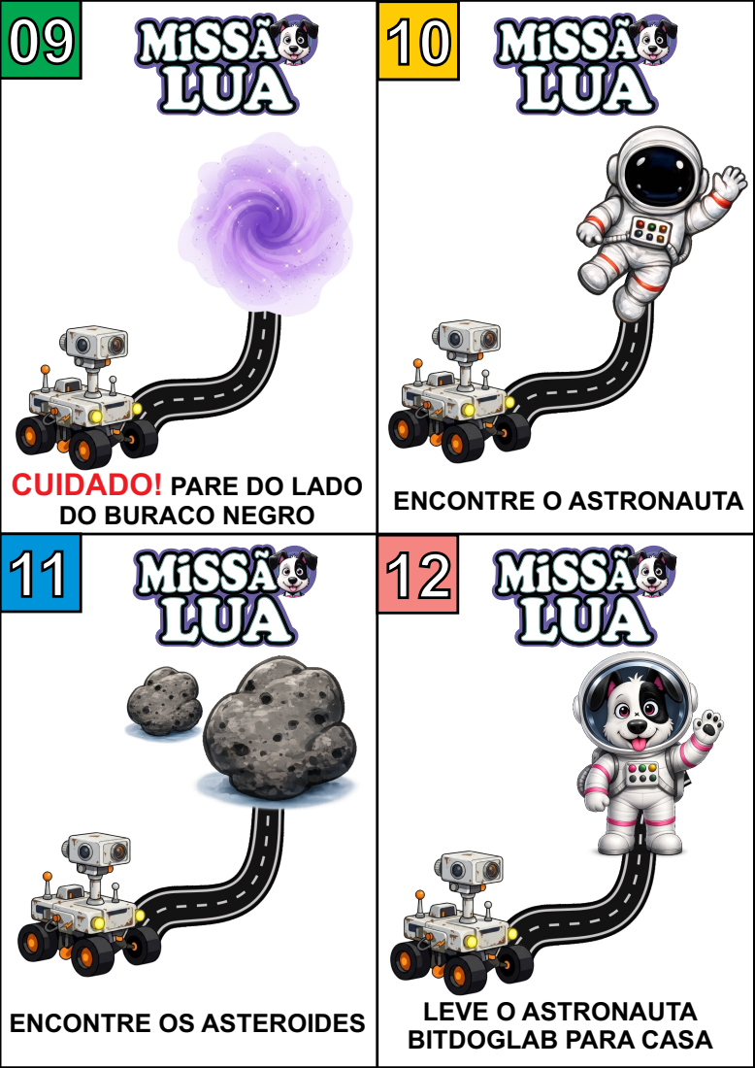
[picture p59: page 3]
ENCONTRE O ASTRONAUTA; ENCONTRE OS ASTEROIDES; LEVE O ASTRONAUTA; MiSSÃO; LUA

CUIDADO! PARE DO LADO
DO BURACO NEGRO
11 12 LUA

BITDOGLAB PARA CASA

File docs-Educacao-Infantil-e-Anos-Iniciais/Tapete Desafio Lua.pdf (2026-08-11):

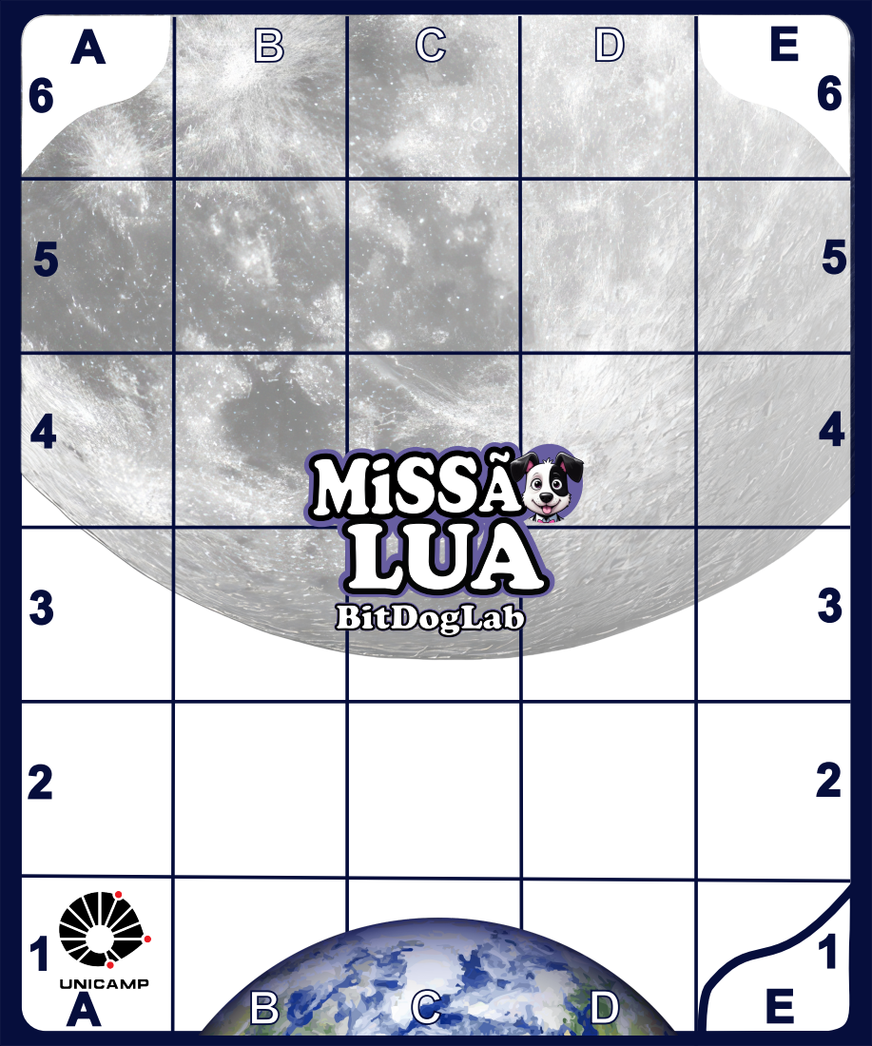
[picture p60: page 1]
LUA; MiSSÃO LUA; BitDogLab tDogLab

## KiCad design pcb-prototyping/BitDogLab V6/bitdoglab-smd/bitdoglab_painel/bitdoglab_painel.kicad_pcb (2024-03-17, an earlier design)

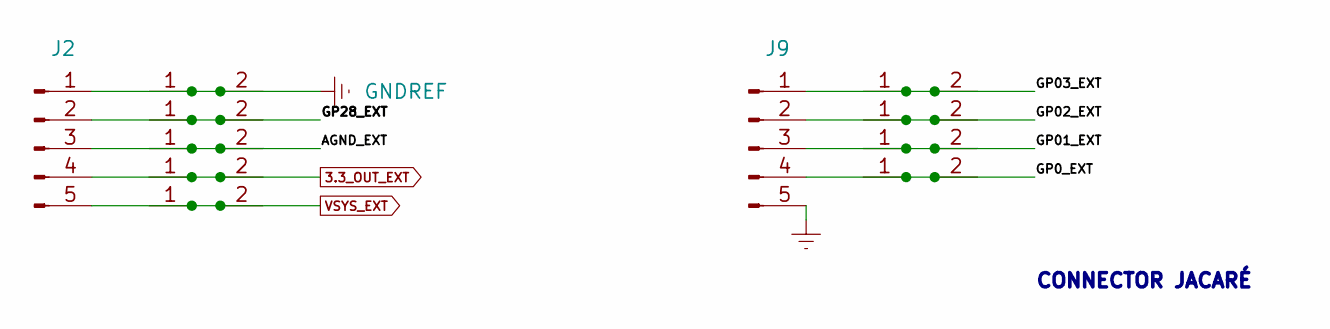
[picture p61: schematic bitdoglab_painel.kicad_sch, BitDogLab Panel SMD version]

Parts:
J2, J9: Conn_01x05_Pin; PinHeader_1x05_P2.54mm_Vertical
J3, J5: GND; SolderWire-2sqmm_1x02_P7.8mm_D2mm_OD3.9mm
J4: ANA-IN; SolderWire-2sqmm_1x02_P7.8mm_D2mm_OD3.9mm
J6: 3V3; SolderWire-2sqmm_1x02_P7.8mm_D2mm_OD3.9mm
J7: 5V-VSYS; SolderWire-2sqmm_1x02_P7.8mm_D2mm_OD3.9mm
J10: 0; SolderWire-2sqmm_1x02_P7.8mm_D2mm_OD3.9mm
J11: 1; SolderWire-2sqmm_1x02_P7.8mm_D2mm_OD3.9mm
J12: 2; SolderWire-2sqmm_1x02_P7.8mm_D2mm_OD3.9mm
J13: 3; SolderWire-2sqmm_1x02_P7.8mm_D2mm_OD3.9mm

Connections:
3.3_OUT_EXT: J2.4, J6.1, J6.2
/AGND_EXT: J2.3, J5.1, J5.2
/GP0_EXT: J9.4, J13.1, J13.2
/GP01_EXT: J9.3, J12.1, J12.2
/GP02_EXT: J9.2, J11.1, J11.2
/GP03_EXT: J9.1, J10.1, J10.2
/GP28_EXT: J2.2, J4.1, J4.2
GNDREF: J2.1, J3.1, J3.2, J9.5
VSYS_EXT: J2.5, J7.1, J7.2

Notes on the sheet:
CONNECTOR JACARÉ

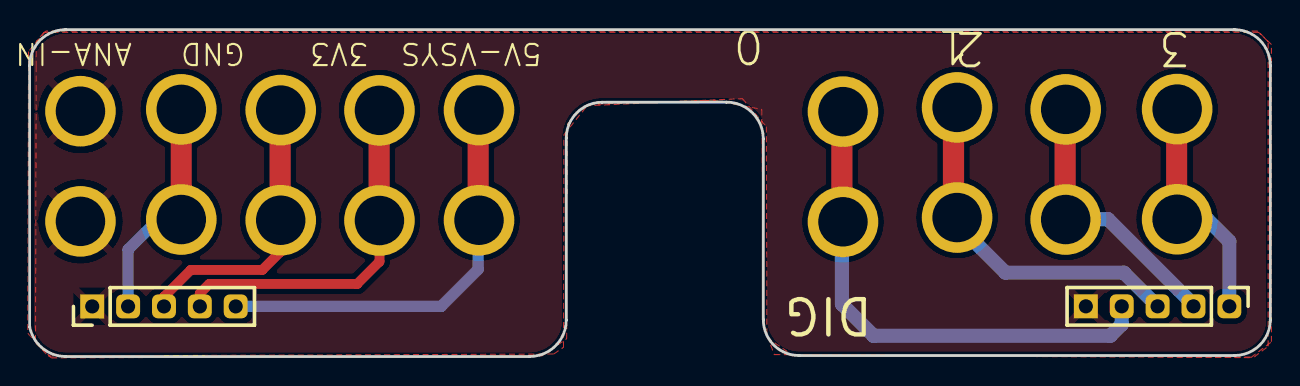
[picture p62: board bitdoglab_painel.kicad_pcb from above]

Board: 2 copper layers, 87.8 x 23.1 mm, 11 parts (0 on the bottom side), 9 nets.

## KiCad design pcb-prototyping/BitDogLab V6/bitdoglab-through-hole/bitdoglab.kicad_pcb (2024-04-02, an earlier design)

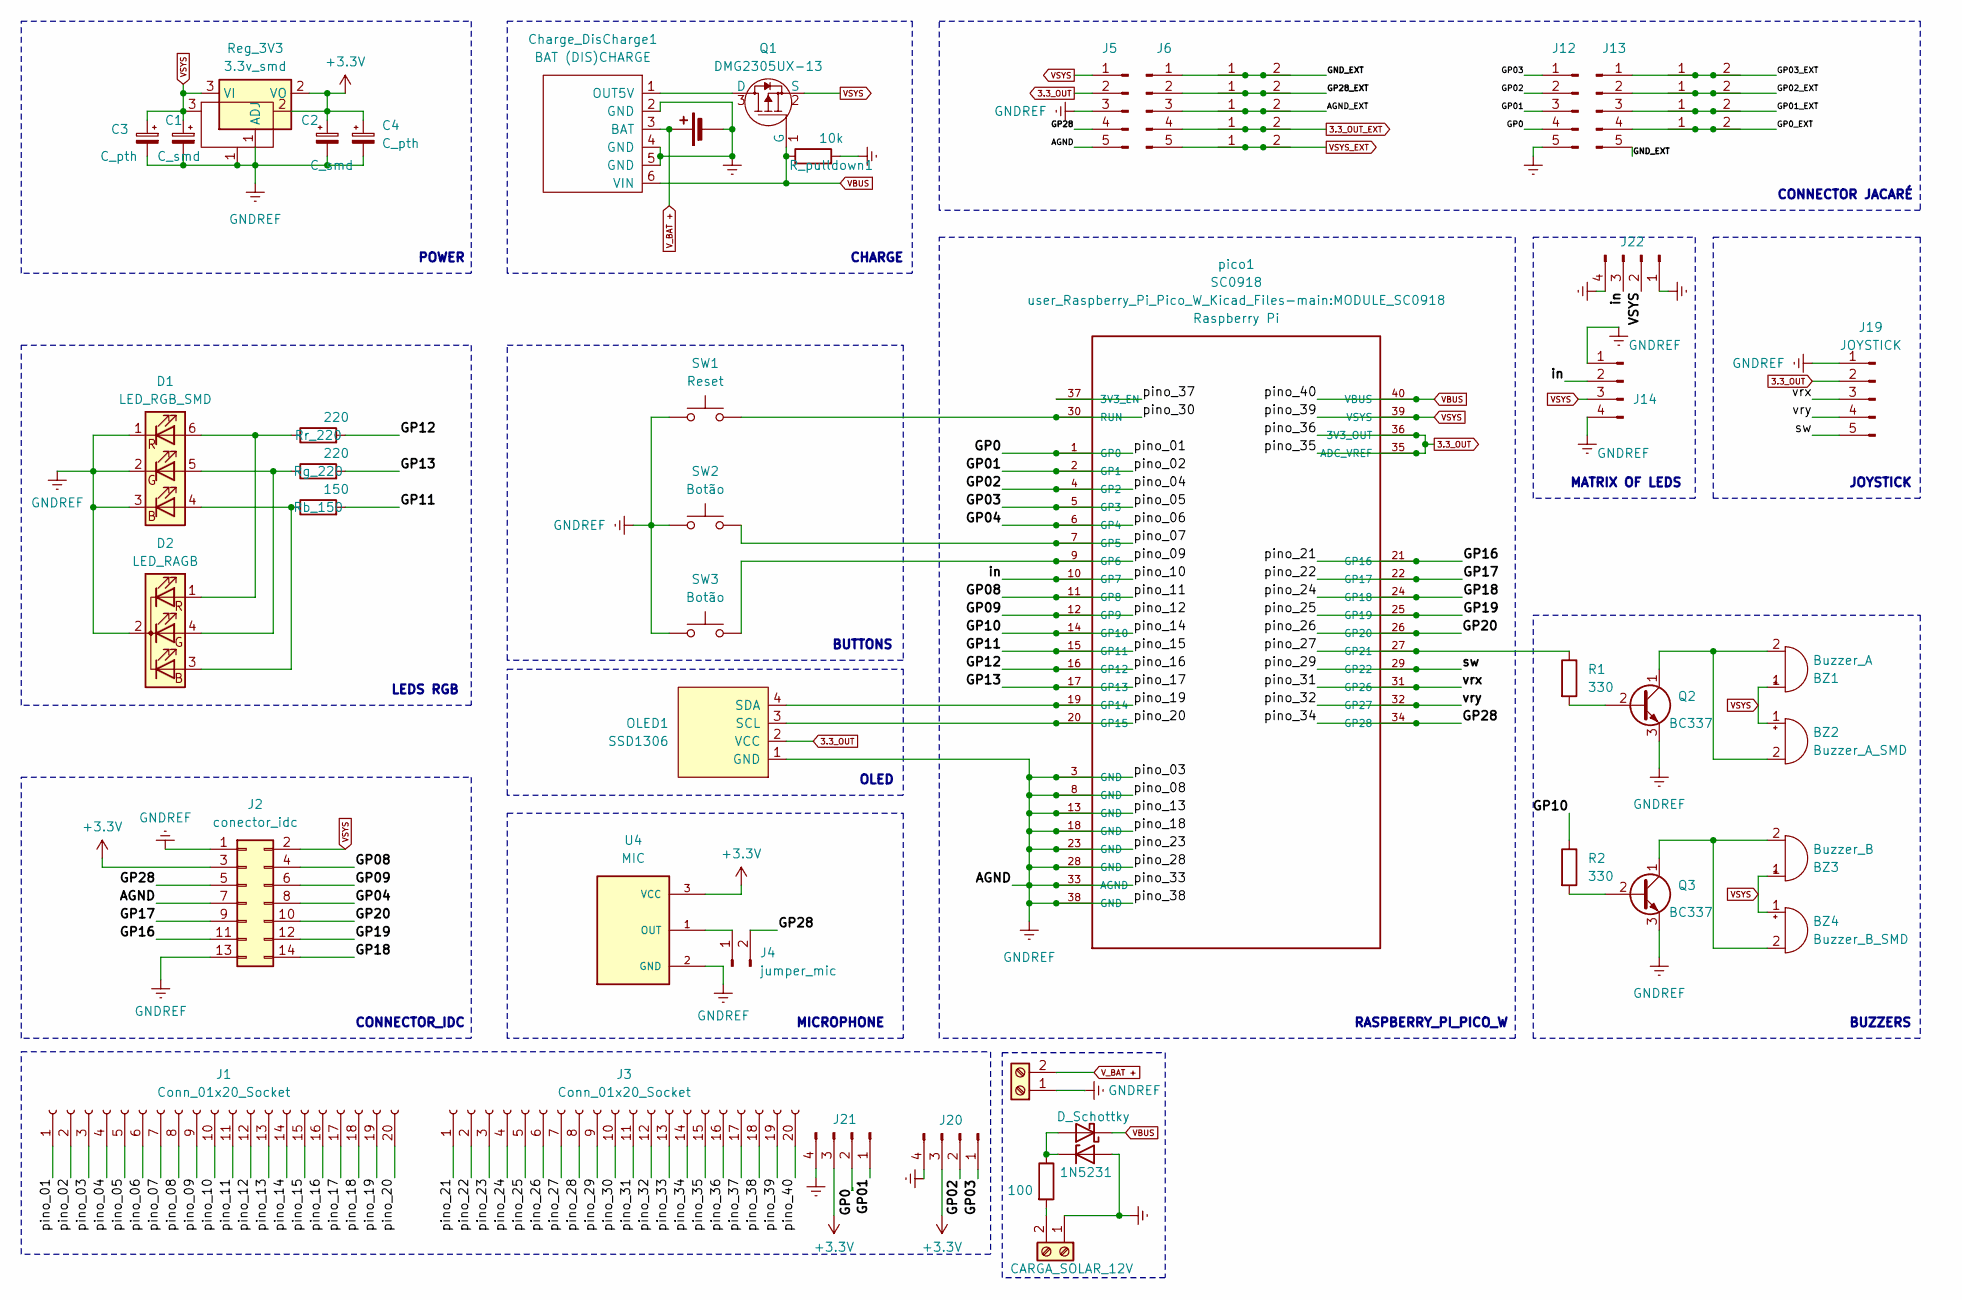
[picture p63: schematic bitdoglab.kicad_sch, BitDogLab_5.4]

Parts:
BT1: Battery_Cell; BatteryHolder_MPD_BH-18650-PC2
BZ1: Buzzer_A; Buzzer_12x9.5RM7.6
BZ2: Buzzer_A_SMD; MagneticBuzzer_CUI_CMT-8504-100-SMT
BZ3: Buzzer_B; Buzzer_12x9.5RM7.6
BZ4: Buzzer_B_SMD; MagneticBuzzer_CUI_CMT-8504-100-SMT
C1, C2: C_smd; CP_Elec_5x5.9
C3, C4: C_pth; CP_Radial_D5.0mm_P2.50mm
CARGA_SOLAR1: CARGA_SOLAR_12V; JST_EH_B2B-EH-A_1x02_P2.50mm_Vertical
Charge_DisCharge1: BAT (DIS)CHARGE; Charger2A
D1: LED_RGB_SMD; LED_RGB_5050-6
D2: LED_RAGB; LED_D5.0mm-4_RGB_Wide_Pins
D3: 1N5231; D_T-1_P5.08mm_Horizontal
D4: D_Schottky; D_DO-15_P3.81mm_Vertical_KathodeUp
J1, J3: Conn_01x20_Socket; PinHeader_1x20_P2.54mm_Vertical
J2: conector_idc; PinHeader_2x07_P2.54mm_Vertical
J4: jumper_mic; PinHeader_1x02_P2.54mm_Vertical
J5, J6, J12, J13: Conn_01x05_Pin; PinHeader_1x05_P2.54mm_Vertical
J7, J9: GND; SolderWire-2sqmm_1x02_P7.8mm_D2mm_OD3.9mm
J8: ANA-IN; SolderWire-2sqmm_1x02_P7.8mm_D2mm_OD3.9mm
J10: 3V3; SolderWire-2sqmm_1x02_P7.8mm_D2mm_OD3.9mm
J11: 5V-VSYS; SolderWire-2sqmm_1x02_P7.8mm_D2mm_OD3.9mm
J14: 5x5 Matrix led; Ws2812_led_5050_rgb_5x5
J15: 0; SolderWire-2sqmm_1x02_P7.8mm_D2mm_OD3.9mm
J16: 1; SolderWire-2sqmm_1x02_P7.8mm_D2mm_OD3.9mm
J17: 2; SolderWire-2sqmm_1x02_P7.8mm_D2mm_OD3.9mm
J18: 3; SolderWire-2sqmm_1x02_P7.8mm_D2mm_OD3.9mm
J19: JOYSTICK; ky-023
J20, J21, J22: Conn_01x04_Pin; JST_EH_B4B-EH-A_1x04_P2.50mm_Vertical
OLED1: SSD1306; 128x64OLED
Q1: DMG2305UX-13; SOT-23-3; MPN DMG2305UX-13; Digi-Key_PN DMG2305UX-13DICT-ND
Q2, Q3: BC337; TO-92
R1, R2: 330; R_Axial_DIN0207_L6.3mm_D2.5mm_P7.62mm_Horizontal
R_1W1: 100; R_Axial_DIN0411_L9.9mm_D3.6mm_P12.70mm_Horizontal
R_pulldown1: 10k; R_Axial_DIN0207_L6.3mm_D2.5mm_P7.62mm_Horizontal
Rb_150: 150; R_Axial_DIN0207_L6.3mm_D2.5mm_P7.62mm_Horizontal
Reg_3V3: 3.3v_smd; SOT-223
Rg_220: 220; R_Axial_DIN0207_L6.3mm_D2.5mm_P7.62mm_Horizontal
Rr_220: 220; R_Axial_DIN0207_L6.3mm_D2.5mm_P7.62mm_Horizontal
SW1: Reset; SW_PUSH_6mm
SW2, SW3: Botão; SW_PUSH-12mm
U1: 3.3v_tht; TO-220-3_Vertical; MPN LD1117V33
U4: MIC; MODULE_1063; PARTREV 1.0
V_BAT1: V_BAT; JST_EH_B2B-EH-A_1x02_P2.50mm_Vertical
pico1: SC0918; MODULE_SC0918; PARTREV 1.6

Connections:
3.3_OUT: J3.15, J3.16, J5.2, J19.2, OLED1.2 (VCC), pico1.35 (ADC_VREF), pico1.36 (3V3_OUT); also elsewhere on the board
3.3_OUT_EXT: J6.4, J10.1, J10.2
+3.3V: C2.1, C4.1, J2.3, J20.3, J21.3, Reg_3V3.2 (VO), U1.2, U4.3 (VCC)
/AGND_EXT: J6.3, J9.1, J9.2
/GND_EXT: J6.1, J7.1, J7.2, J13.5
/GP0: J1.1, J12.4, J21.2, pico1.1 (GP0)
/GP0_EXT: J13.4, J18.1, J18.2
/GP01: J1.2, J12.3, J21.1, pico1.2 (GP1)
/GP01_EXT: J13.3, J17.1, J17.2
/GP02: J1.4, J12.2, J20.2, pico1.4 (GP2)
/GP02_EXT: J13.2, J16.1, J16.2
/GP03: J1.5, J12.1, J20.1, pico1.5 (GP3)
/GP03_EXT: J13.1, J15.1, J15.2
/GP04: J1.6, J2.8, pico1.6 (GP4)
/GP08: J1.11, J2.4, pico1.11 (GP8)
/GP09: J1.12, J2.6, pico1.12 (GP9)
/GP10: J1.14, R2.1, pico1.14 (GP10)
/GP11: J1.15, Rb_150.2, pico1.15 (GP11)
/GP12: J1.16, Rr_220.2, pico1.16 (GP12)
/GP13: J1.17, Rg_220.2, pico1.17 (GP13)
/GP16: J2.11, J3.1, pico1.21 (GP16)
/GP17: J2.9, J3.2, pico1.22 (GP17)
/GP18: J2.14, J3.4, pico1.24 (GP18)
/GP19: J2.12, J3.5, pico1.25 (GP19)
/GP20: J2.10, J3.6, pico1.26 (GP20)
/GP28: J2.5, J3.14, J4.2, J5.4, pico1.34 (GP28)
/GP28_EXT: J6.2, J8.1, J8.2
/in: J1.10, J14.2, J22.3, pico1.10 (GP7)
/pino_07: J1.7, SW2.1, pico1.7 (GP5)
/pino_09: J1.9, SW3.1, pico1.9 (GP6)
/pino_19: J1.19, OLED1.4 (SDA), pico1.19 (GP14)
/pino_20: J1.20, OLED1.3 (SCL), pico1.20 (GP15)
/pino_27: J3.7, R1.1, pico1.27 (GP21)
/pino_29: J3.9, J19.5, pico1.29 (GP22); also elsewhere on the board
/pino_30: J3.10, SW1.1, pico1.30 (RUN)
/pino_31: J3.11, J19.3, pico1.31 (GP26); also elsewhere on the board
/pino_32: J3.12, J19.4, pico1.32 (GP27); also elsewhere on the board
/pino_37: J3.17, pico1.37 (3V3_EN)
GNDREF: BT1.2 (-), C1.2, C2.2, C3.2, C4.2, CARGA_SOLAR1.1, Charge_DisCharge1.2 (GND), Charge_DisCharge1.4 (GND), Charge_DisCharge1.5 (GND), D1.1 (RK), D1.2 (GK), D1.3 (BK), D2.2 (K), D3.2 (A), J1.3, J1.8, J1.13, J1.18, J2.1, J2.7, J2.13, J3.3, J3.8, J3.13, J3.18, J5.3, J5.5, J12.5, J14.1, J14.4, J19.1, J20.4, J21.4, J22.1, J22.4, OLED1.1 (GND), Q2.3 (E), Q3.3 (E), R_pulldown1.2, Reg_3V3.1 (ADJ), SW1.2, SW2.2, SW3.2, U1.1, U4.2 (GND), V_BAT1.1, pico1.3 (GND), pico1.8 (GND), pico1.13 (GND), pico1.18 (GND), pico1.23 (GND), pico1.28 (GND), pico1.33 (AGND), pico1.38 (GND); also elsewhere on the board
unnamed: BZ1.2 (+), BZ2.2 (+), Q2.1 (C)
unnamed: BZ3.2 (+), BZ4.2 (+), Q3.1 (C)
unnamed: CARGA_SOLAR1.2, R_1W1.2
unnamed: Charge_DisCharge1.1 (OUT5V), Q1.3 (D)
unnamed: D1.4 (BA), D2.3 (BA), Rb_150.1
unnamed: D1.5 (GA), D2.4 (GA), Rg_220.1
unnamed: D1.6 (RA), D2.1 (RA), Rr_220.1
unnamed: D3.1 (K), D4.2 (A), R_1W1.1
unnamed: J4.1, U4.1 (OUT)
unnamed: Q2.2 (B), R1.2
unnamed: Q3.2 (B), R2.2
VBUS: Charge_DisCharge1.6 (VIN), D4.1 (K), J3.20, Q1.1 (G), R_pulldown1.1, pico1.40 (VBUS)
VSYS: BZ1.1 (-), BZ2.1 (-), BZ3.1 (-), BZ4.1 (-), C1.1, C3.1, J2.2, J3.19, J5.1, J14.3, J22.2, Q1.2 (S), Reg_3V3.3 (VI), U1.3, pico1.39 (VSYS)
VSYS_EXT: J6.5, J11.1, J11.2
V_BAT +: BT1.1 (+), Charge_DisCharge1.3 (BAT), V_BAT1.2

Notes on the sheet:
POWER
OLED
BUZZERS
LEDS RGB
BUTTONS
MICROPHONE
CONNECTOR_IDC
CONNECTOR JACARÉ
CHARGE
MATRIX OF LEDS
RASPBERRY_PI_PICO_W
JOYSTICK

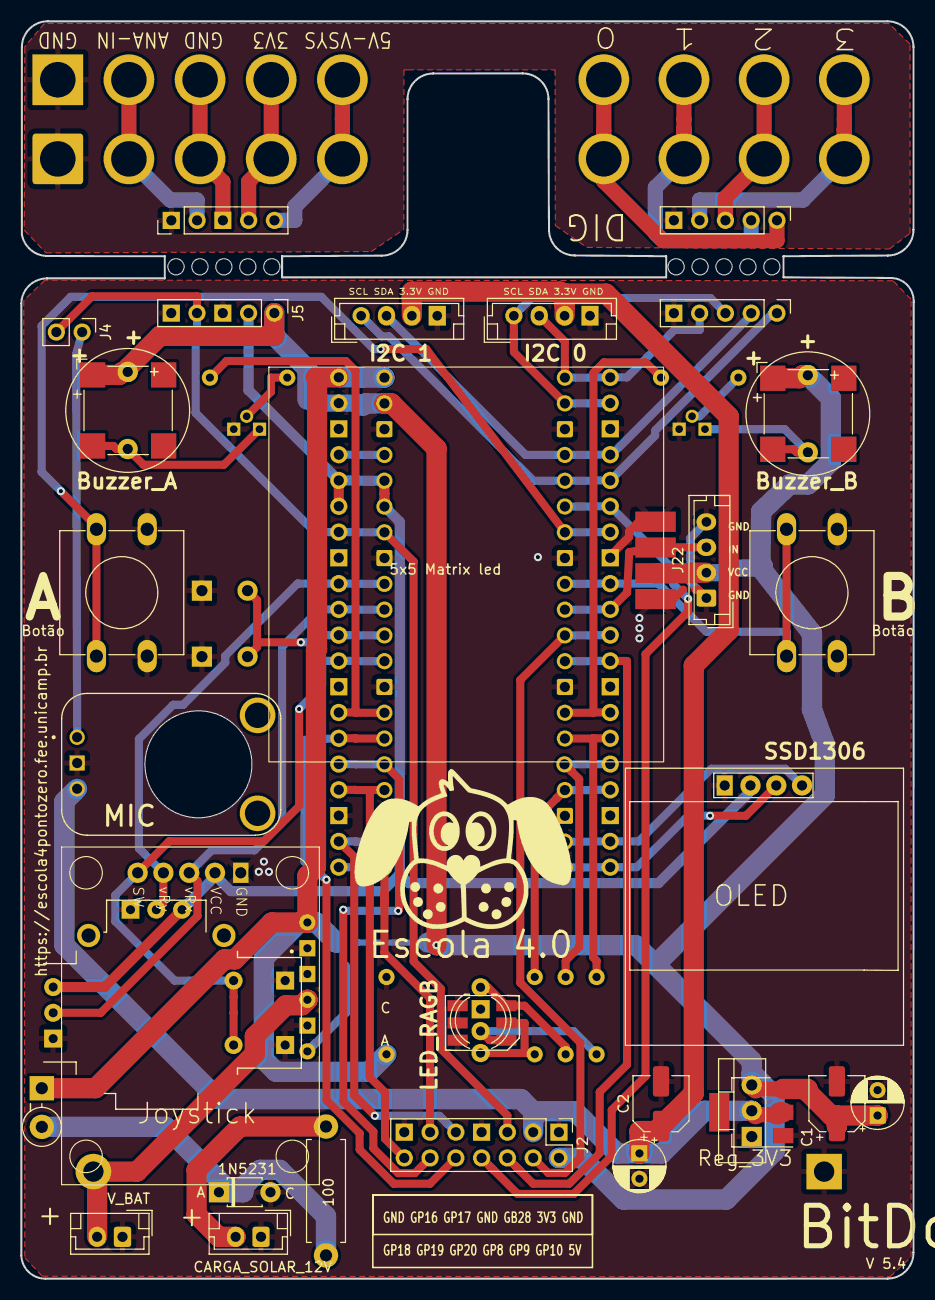
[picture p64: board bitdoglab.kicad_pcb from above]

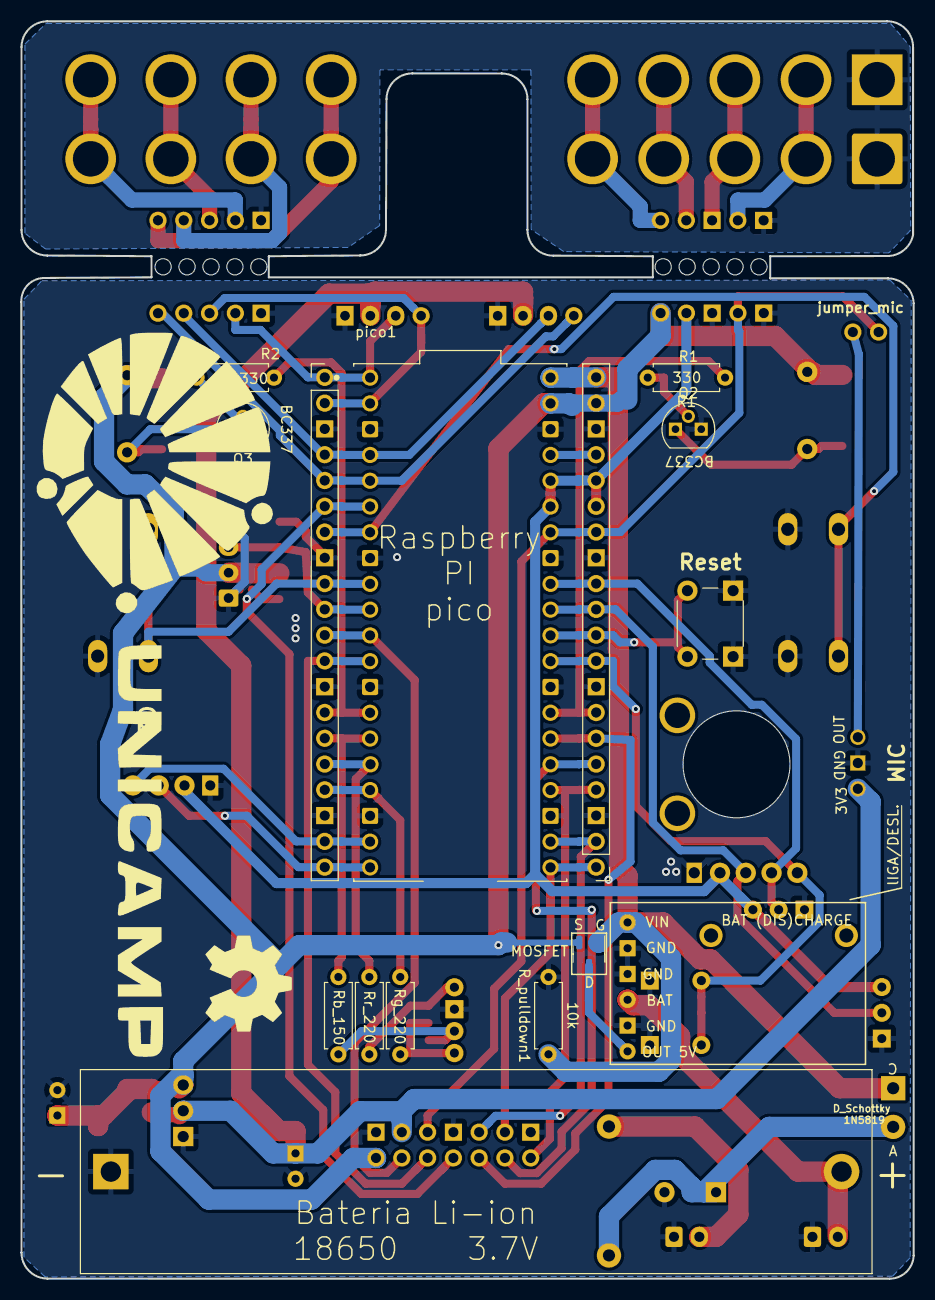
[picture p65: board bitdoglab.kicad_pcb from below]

Board: 2 copper layers, 87.9 x 123.9 mm, 60 parts (17 on the bottom side), 54 nets.

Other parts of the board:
G1: LOGO; logo bitDog 25mm
G2: LOGO; unicamp V2A
G3: LOGO
JOY1: JOYSTICK; XDCR_COM-09032

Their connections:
3.3_OUT: JOY1.H1, JOY1.V1; also elsewhere on the board
/pino_29: JOY1.B2A, JOY1.B2B; also elsewhere on the board
/pino_31: JOY1.H2; also elsewhere on the board
/pino_32: JOY1.V2; also elsewhere on the board
GNDREF: JOY1.B1A, JOY1.B1B, JOY1.H3, JOY1.V3; also elsewhere on the board

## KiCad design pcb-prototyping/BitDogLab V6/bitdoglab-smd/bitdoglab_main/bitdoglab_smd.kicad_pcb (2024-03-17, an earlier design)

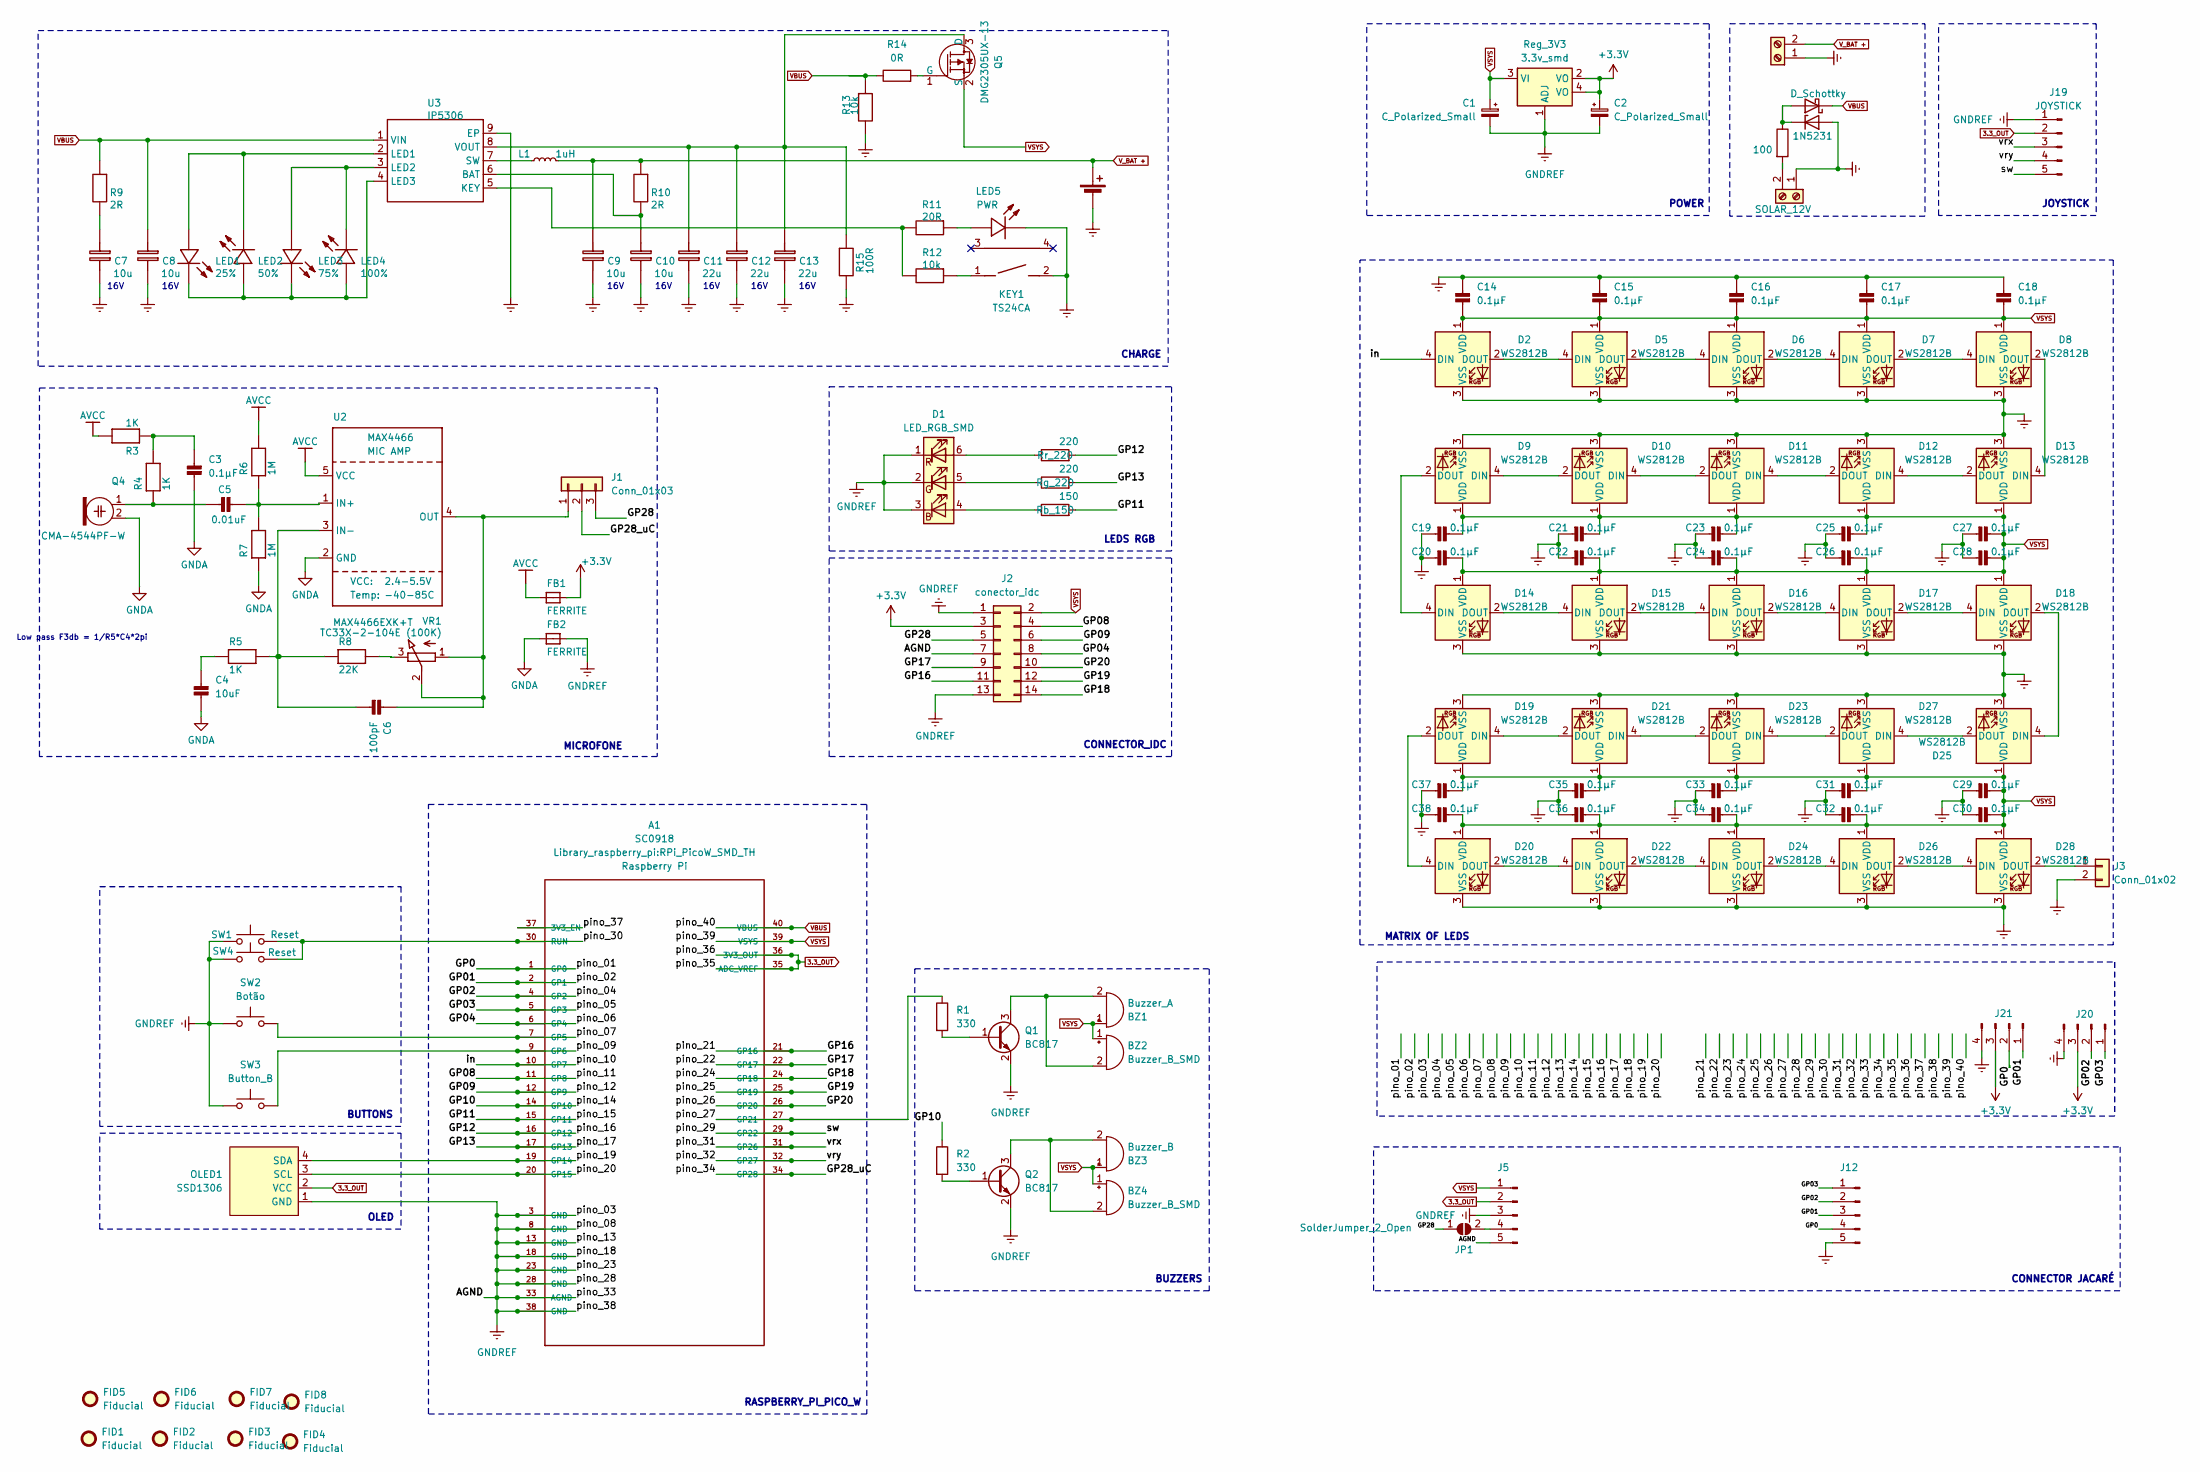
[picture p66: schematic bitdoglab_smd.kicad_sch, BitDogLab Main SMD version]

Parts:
A1: SC0918; RPi_PicoW_SMD_TH; PARTREV 1.6
BT1: Battery_Cell; BatteryHolder_MPD_BH-18650-PC2
BZ1: Buzzer_A; Buzzer_12x9.5RM7.6
BZ2, BZ4: Buzzer_B_SMD; MagneticBuzzer_CUI_CMT-8504-100-SMT
BZ3: Buzzer_B; Buzzer_12x9.5RM7.6
C1, C2: C_Polarized_Small; CP_Elec_5x5.9
C3, C14, C15, C16, C17, C18, C19, C20, C21, C22, C23, C24, C25, C26, C27, C28, C29, C30, C31, C32, C33, C34, C35, C36, C37, C38: 0.1µF; C_0402_1005Metric
C4: 10uF; C_0805_2012Metric
C5: 0.01uF; C_0402_1005Metric
C6: 100pF; C_0402_1005Metric
C7, C8, C9, C10: 10u; R_0805_2012Metric; MANUFACTURER PART CL21A106KAYNNNE
C11, C12, C13: 22u; R_0805_2012Metric; MANUFACTURER PART CL21A226MAQNNNE
CARGA_SOLAR1: SOLAR_12V; JST_EH_B2B-EH-A_1x02_P2.50mm_Vertical
D1: LED_RGB_SMD; LED_RGB_5050-6
D2, D5, D6, D7, D8, D9, D10, D11, D12, D13, D14, D15, D16, D17, D18, D19, D20, D21, D22, D23, D24, D25, D26, D27, D28: WS2812B; LED_WS2812B_PLCC4_5.0x5.0mm_P3.2mm
D3: 1N5231; D_T-1_P5.08mm_Horizontal
D4: D_Schottky; D_SOD-123
FB1, FB2: FERRITE; L_0603_1608Metric
FID1, FID2, FID3, FID4, FID5, FID6, FID7, FID8: Fiducial; Fiducial_1mm_Mask2mm
J1: Conn_01x03; PinHeader_1x03_P2.54mm_Vertical
J2: conector_idc; PinHeader_2x07_P2.54mm_Vertical
J3: Conn_01x02; PinHeader_1x02_P2.54mm_Vertical
J5, J12: Conn_01x05_Pin; PinHeader_1x05_P2.54mm_Vertical
J19: JOYSTICK; ky-023
J20, J21: Conn_01x04_Pin; JST_EH_B4B-EH-A_1x04_P2.50mm_Vertical
JP1: SolderJumper_2_Open; SolderJumper-2_P1.3mm_Open_TrianglePad1.0x1.5mm
KEY1: TS24CA; SW_SPST_CK_KMS2xxGP; MANUFACTURER PART TS24CA
L1: 1uH; L_Bourns_SRP7028A_7.3x6.6mm
LED1: 25%; LED_0805_2012Metric; MANUFACTURER PART FC-2012HRK-620D
LED2: 50%; LED_0805_2012Metric; MANUFACTURER PART 17-21SUYC/TR8
LED3: 75%; LED_0805_2012Metric; MANUFACTURER PART 17-21SUYC/TR8
LED4: 100%; LED_0805_2012Metric; MANUFACTURER PART 0805G (Green)
LED5: PWR; LED_0805_2012Metric; MANUFACTURER PART ORH-B35A
OLED1: SSD1306; 128x64OLED
Q1, Q2: BC817; SOT-23
Q4: CMA-4544PF-W; Buzzer_12x9.5RM7.6
Q5: DMG2305UX-13; SOT-23-3; MPN DMG2305UX-13; Digi-Key_PN DMG2305UX-13DICT-ND
R1, R2: 330; R_0603_1608Metric
R3, R4, R5: 1K; R_0603_1608Metric
R6, R7: 1M; R_0603_1608Metric
R8: 22K; R_0603_1608Metric
R9, R10: 2R; R_0603_1608Metric; MANUFACTURER PART RS-05L2R00FT
R11: 20R; R_0603_1608Metric; MANUFACTURER PART 0805W8F200JT5E
R12, R13: 10k; R_0603_1608Metric; MANUFACTURER PART 0805W8F1002T5E
R14: 0R; R_0603_1608Metric
R15: 100R; R_1210_3225Metric; MANUFACTURER PART RC1210FR-07100RL
R_1W1: 100; R_0603_1608Metric
Rb_150: 150; R_0603_1608Metric
Reg_3V3: 3.3v_smd; SOT-223
Rg_220: 220; R_0603_1608Metric
Rr_220: 220; R_0603_1608Metric
SW1: Reset; SW_PUSH_6mm
SW2: Botão; SW_PUSH_6mm_b
SW3: Button_B; SW_PUSH_6mm_b
SW4: Reset; SW_Push_1P1T_NO_6x6mm_H9.5mm
U2: MAX4466EXK+T; SOT-353_SC-70-5
U3: IP5306; SOP-8_5.28x5.23mm_P1.27mm; MANUFACTURER PART IP5306_4.35V
VR1: TC33X-2-104E (100K); Potentiometer_Bourns_TC33X_Vertical
V_BAT1: V_BAT; JST_EH_B2B-EH-A_1x02_P2.50mm_Vertical

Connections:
3.3_OUT: A1.35 (ADC_VREF), A1.36 (3V3_OUT), J5.2, J19.2, OLED1.2 (VCC)
+3.3V: C2.1, FB1.2, J2.3, J20.3, J21.3, Reg_3V3.2 (VO), Reg_3V3.4 (VO)
/GP0: A1.1 (GP0), J12.4, J21.2
/GP01: A1.2 (GP1), J12.3, J21.1
/GP02: A1.4 (GP2), J12.2, J20.2
/GP03: A1.5 (GP3), J12.1, J20.1
/GP04: A1.6 (GP4), J2.8
/GP08: A1.11 (GP8), J2.4
/GP09: A1.12 (GP9), J2.6
/GP10: A1.14 (GP10), R2.1
/GP11: A1.15 (GP11), Rb_150.2
/GP12: A1.16 (GP12), Rr_220.2
/GP13: A1.17 (GP13), Rg_220.2
/GP16: A1.21 (GP16), J2.11
/GP17: A1.22 (GP17), J2.9
/GP18: A1.24 (GP18), J2.14
/GP19: A1.25 (GP19), J2.12
/GP20: A1.26 (GP20), J2.10
/GP28: J1.3, J2.5, JP1.1 (A)
/GP28_uC: A1.34 (GP28), J1.2
/in: A1.10 (GP7), D2.4 (DIN)
/pino_07: A1.7 (GP5), SW2.1
/pino_09: A1.9 (GP6), SW3.1
/pino_19: A1.19 (GP14), OLED1.4 (SDA)
/pino_20: A1.20 (GP15), OLED1.3 (SCL)
/pino_27: A1.27 (GP21), R1.1
/pino_29: A1.29 (GP22), J19.5
/pino_30: A1.30 (RUN), SW1.1, SW4.1
/pino_31: A1.31 (GP26), J19.3
/pino_32: A1.32 (GP27), J19.4
/pino_37: A1.37 (3V3_EN)
AVCC: FB1.1, R3.2, R6.2, U2.5 (VCC)
GNDA: C3.2, C4.2, FB2.1, Q4.2 (+), R7.1, U2.2 (GND)
GNDREF: A1.3 (GND), A1.8 (GND), A1.13 (GND), A1.18 (GND), A1.23 (GND), A1.28 (GND), A1.33 (AGND), A1.38 (GND), BT1.2 (-), C1.2, C2.2, C7.2, C8.2, C9.2, C10.2, C11.2, C12.2, C13.2, C14.1, C15.1, C16.1, C17.1, C18.1, C19.1, C20.1, C21.1, C22.1, C23.1, C24.1, C25.1, C26.1, C27.1, C28.1, C29.1, C30.1, C31.1, C32.1, C33.1, C34.1, C35.1, C36.1, C37.1, C38.1, CARGA_SOLAR1.1, D1.1 (RK), D1.2 (GK), D1.3 (BK), D2.3 (VSS), D3.2 (A), D5.3 (VSS), D6.3 (VSS), D7.3 (VSS), D8.3 (VSS), D9.3 (VSS), D10.3 (VSS), D11.3 (VSS), D12.3 (VSS), D13.3 (VSS), D14.3 (VSS), D15.3 (VSS), D16.3 (VSS), D17.3 (VSS), D18.3 (VSS), D19.3 (VSS), D20.3 (VSS), D21.3 (VSS), D22.3 (VSS), D23.3 (VSS), D24.3 (VSS), D25.3 (VSS), D26.3 (VSS), D27.3 (VSS), D28.3 (VSS), FB2.2, J2.1, J2.7, J2.13, J3.2, J5.3, J5.5, J12.5, J19.1, J20.4, J21.4, KEY1.2, LED5.2 (K), OLED1.1 (GND), Q1.2 (E), Q2.2 (E), R13.2, R15.2, Reg_3V3.1 (ADJ), SW1.2, SW2.2, SW3.2, SW4.2, U3.9 (EP), V_BAT1.1
unnamed: BZ1.2 (+), BZ2.2 (+), Q1.3 (C)
unnamed: BZ3.2 (+), BZ4.2 (+), Q2.3 (C)
unnamed: C3.1, R3.1, R4.2
unnamed: C4.1, R5.1
unnamed: C5.1, Q4.1 (-), R4.1
unnamed: C5.2, R6.1, R7.2, U2.1 (IN+)
unnamed: C6.1, J1.1, U2.4 (OUT), VR1.1 (A), VR1.2 (S)
unnamed: C6.2, R5.2, R8.1, U2.3 (IN-)
unnamed: C7.1, R9.1
unnamed: CARGA_SOLAR1.2, R_1W1.2
unnamed: D1.4 (BA), Rb_150.1
unnamed: D1.5 (GA), Rg_220.1
unnamed: D1.6 (RA), Rr_220.1
unnamed: D2.2 (DOUT), D5.4 (DIN)
unnamed: D3.1 (K), D4.2 (A), R_1W1.1
unnamed: D5.2 (DOUT), D6.4 (DIN)
unnamed: D6.2 (DOUT), D7.4 (DIN)
unnamed: D7.2 (DOUT), D8.4 (DIN)
unnamed: D10.4 (DIN), D11.2 (DOUT)
unnamed: D9.4 (DIN), D10.2 (DOUT)
unnamed: D11.4 (DIN), D12.2 (DOUT)
unnamed: D12.4 (DIN), D13.2 (DOUT)
unnamed: D8.2 (DOUT), D13.4 (DIN)
unnamed: D9.2 (DOUT), D14.4 (DIN)
unnamed: D14.2 (DOUT), D15.4 (DIN)
unnamed: D15.2 (DOUT), D16.4 (DIN)
unnamed: D16.2 (DOUT), D17.4 (DIN)
unnamed: D17.2 (DOUT), D18.4 (DIN)
unnamed: D18.2 (DOUT), D25.4 (DIN)
unnamed: D19.4 (DIN), D21.2 (DOUT)
unnamed: D19.2 (DOUT), D20.4 (DIN)
unnamed: D20.2 (DOUT), D22.4 (DIN)
unnamed: D21.4 (DIN), D23.2 (DOUT)
unnamed: D22.2 (DOUT), D24.4 (DIN)
unnamed: D23.4 (DIN), D27.2 (DOUT)
unnamed: D24.2 (DOUT), D26.4 (DIN)
unnamed: D25.2 (DOUT), D27.4 (DIN)
unnamed: D26.2 (DOUT), D28.4 (DIN)
unnamed: D28.2 (DOUT), J3.1
unnamed: J5.4, JP1.2 (B)
unnamed: KEY1.1, R12.1
unnamed: LED1.1 (A), LED2.2 (K), U3.2 (LED1)
unnamed: LED1.2 (K), LED2.1 (A), LED3.2 (K), LED4.1 (A), U3.4 (LED3)
unnamed: LED3.1 (A), LED4.2 (K), U3.3 (LED2)
unnamed: LED5.1 (A), R11.1
unnamed: Q1.1 (B), R1.2
unnamed: Q2.1 (B), R2.2
unnamed: C11.1, C12.1, C13.1, Q5.3 (D), R15.1, U3.8 (VOUT)
unnamed: Q5.1 (G), R14.2
unnamed: C10.1, R10.1, U3.6 (BAT)
unnamed: R11.2, R12.2, U3.5 (KEY)
unnamed: L1.1, U3.7 (SW)
unnamed: R8.2, VR1.3 (E)
VBUS: A1.40 (VBUS), C8.1, D4.1 (K), R9.2, R13.1, R14.1, U3.1 (VIN)
VSYS: A1.39 (VSYS), BZ1.1 (-), BZ2.1 (-), BZ3.1 (-), BZ4.1 (-), C1.1, C14.2, C15.2, C16.2, C17.2, C18.2, C19.2, C20.2, C21.2, C22.2, C23.2, C24.2, C25.2, C26.2, C27.2, C28.2, C29.2, C30.2, C31.2, C32.2, C33.2, C34.2, C35.2, C36.2, C37.2, C38.2, D2.1 (VDD), D5.1 (VDD), D6.1 (VDD), D7.1 (VDD), D8.1 (VDD), D9.1 (VDD), D10.1 (VDD), D11.1 (VDD), D12.1 (VDD), D13.1 (VDD), D14.1 (VDD), D15.1 (VDD), D16.1 (VDD), D17.1 (VDD), D18.1 (VDD), D19.1 (VDD), D20.1 (VDD), D21.1 (VDD), D22.1 (VDD), D23.1 (VDD), D24.1 (VDD), D25.1 (VDD), D26.1 (VDD), D27.1 (VDD), D28.1 (VDD), J2.2, J5.1, Q5.2 (S), Reg_3V3.3 (VI)
V_BAT +: BT1.1 (+), C9.1, L1.2, R10.2, V_BAT1.2

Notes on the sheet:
POWER
OLED
BUZZERS
LEDS RGB
BUTTONS
16V
CONNECTOR_IDC
CONNECTOR JACARÉ
Low pass F3db = 1/R5*C4*2pi
CHARGE
MICROFONE
MATRIX OF LEDS
RASPBERRY_PI_PICO_W
JOYSTICK

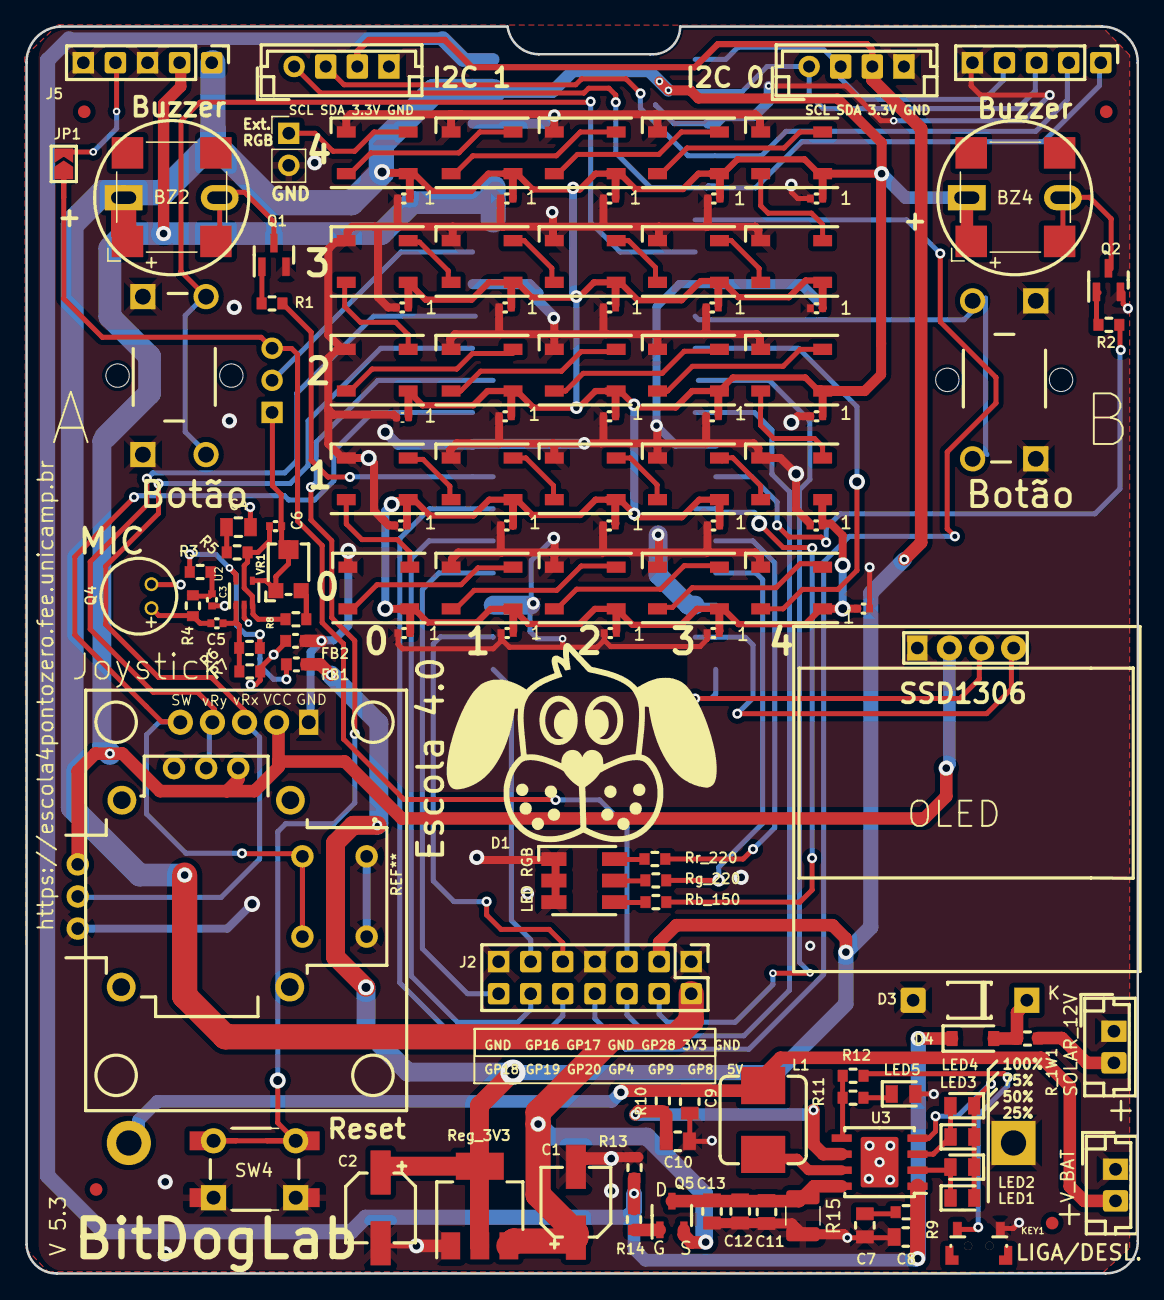
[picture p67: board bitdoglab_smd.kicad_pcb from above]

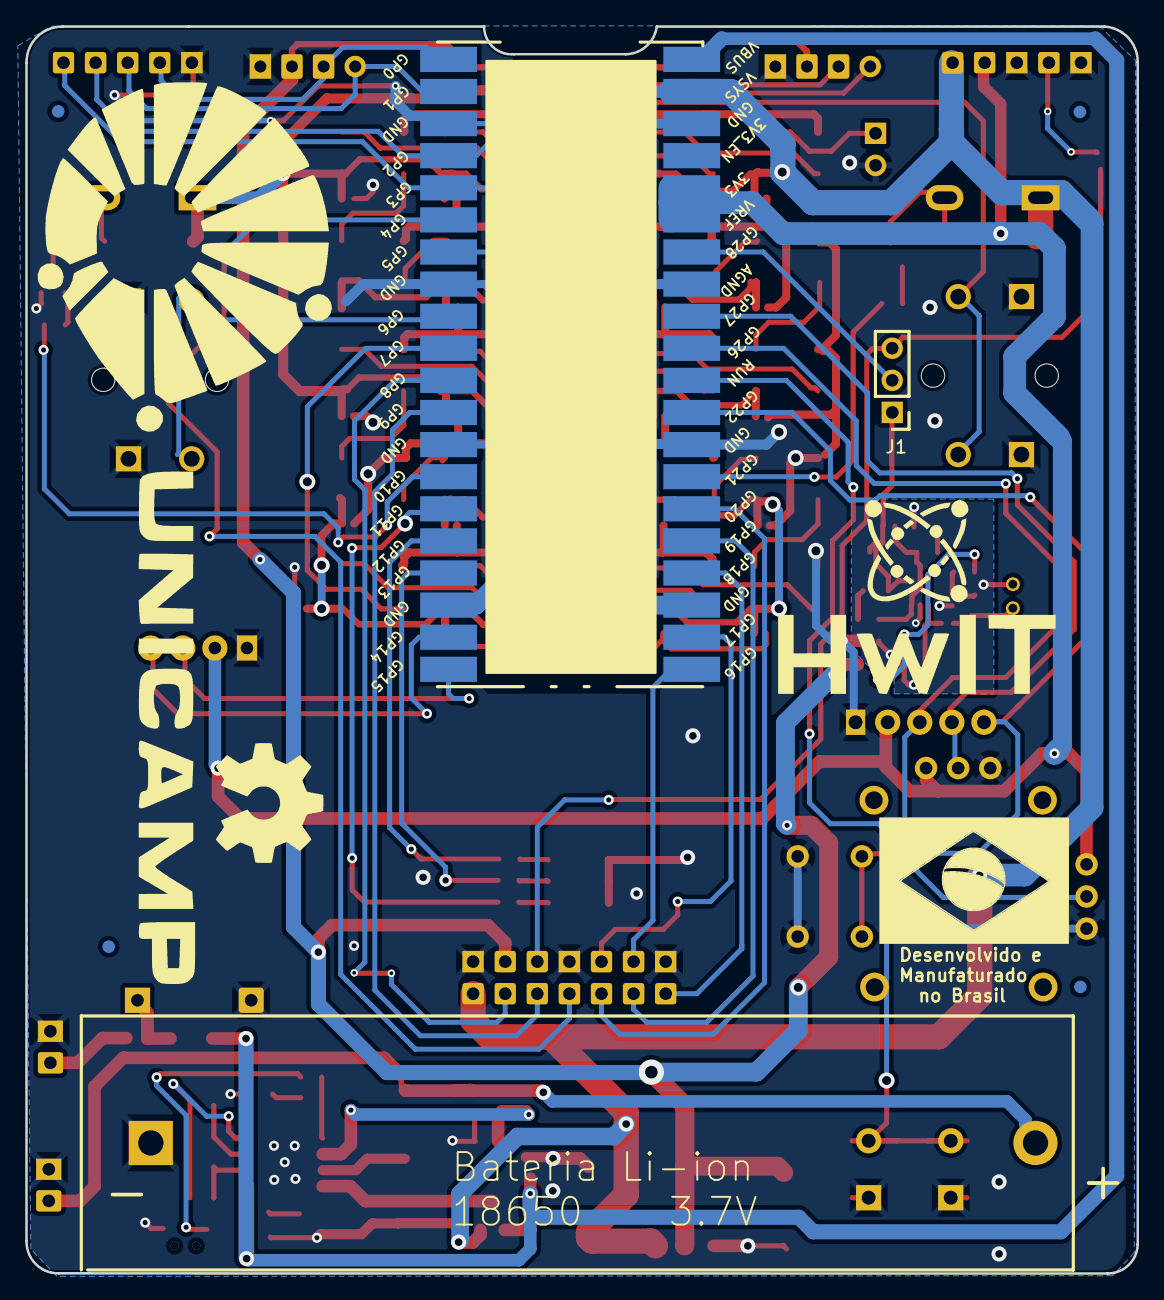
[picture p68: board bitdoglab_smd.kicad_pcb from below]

Board: 2 copper layers, 87.9 x 98.7 mm, 137 parts (11 on the bottom side), 89 nets.

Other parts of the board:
.: LOGO; Brasil_4
.#2: LOGO; 1Logo
.#3: LOGO; unicamp V2A
G1: LOGO; logo bitDog 25mm
G3: LOGO

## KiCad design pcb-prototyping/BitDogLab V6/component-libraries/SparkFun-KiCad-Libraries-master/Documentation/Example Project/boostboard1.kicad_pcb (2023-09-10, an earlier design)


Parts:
C1, C2, C3: 22UF-0805-6.3V-20%; 0805
D1: LED-RED0603; LED-0603
FD1, FD2: FIDUCIAL1X2; FIDUCIAL-1X2
H1: STAND-OFF
J1, J3: CONN_02; 1X02
J2: CONN_01; 1X01
JP1: JUMPER-SMT_2_NO; SMT-JUMPER_2_NO_SILK
L1: INDUCTOR-CDRH-4.7UH; INDUCTOR_2.2UH
LOGO1: SFE_LOGO_NAME_FLAME.1_INCH; SFE_LOGO_NAME_FLAME_.1
LOGO2: OSHW-LOGOS; OSHW-LOGO-S
R1: 10KOHM-0603-1_10W-1%; 0603
R2, R4: 100KOHM-0603-1_10W-1%; 0603
R3, R5: 820KOHM-0603-1_10W-1%; 0603
R6: 4.7KOHM-0603-1_10W-1%; 0603
U1: PAM2401; MSOP8

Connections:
/EN: J2.1, R1.2, U1.2 (EN)
/FB: JP1.2, R3.1, R4.2, U1.5 (FB)
/GND: C1.2, C2.2, C3.2, J1.1, J3.1, R2.2, R4.1, R6.1, U1.4 (AGND), U1.8 (PGND)
/LX: L1.P$2 (2), U1.1 (LX)
/RSET: R2.1, U1.6 (RSET)
/VBATT: C1.1, J1.2, L1.P$1 (1), R1.1, U1.3 (VIN)
/VCC: C2.1, C3.1, D1.A, J3.2, R3.2, R5.2, U1.7 (OUT)
unnamed: D1.C, R6.2
unnamed: JP1.1, R5.1

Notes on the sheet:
1A Booster
Jumper: Open for 5.0V operation Closed for 3.3V operation
Input
Output
Input Range: 0.9 to 4.75V For full output capacity, upwards of 3A may be required. For max operation, calculate with P=IV, using 6 watts. At 3.7V, Iin = 1.62A



Board: 2 copper layers, 15.2 x 15.2 mm, 21 parts (3 on the bottom side), 9 nets.

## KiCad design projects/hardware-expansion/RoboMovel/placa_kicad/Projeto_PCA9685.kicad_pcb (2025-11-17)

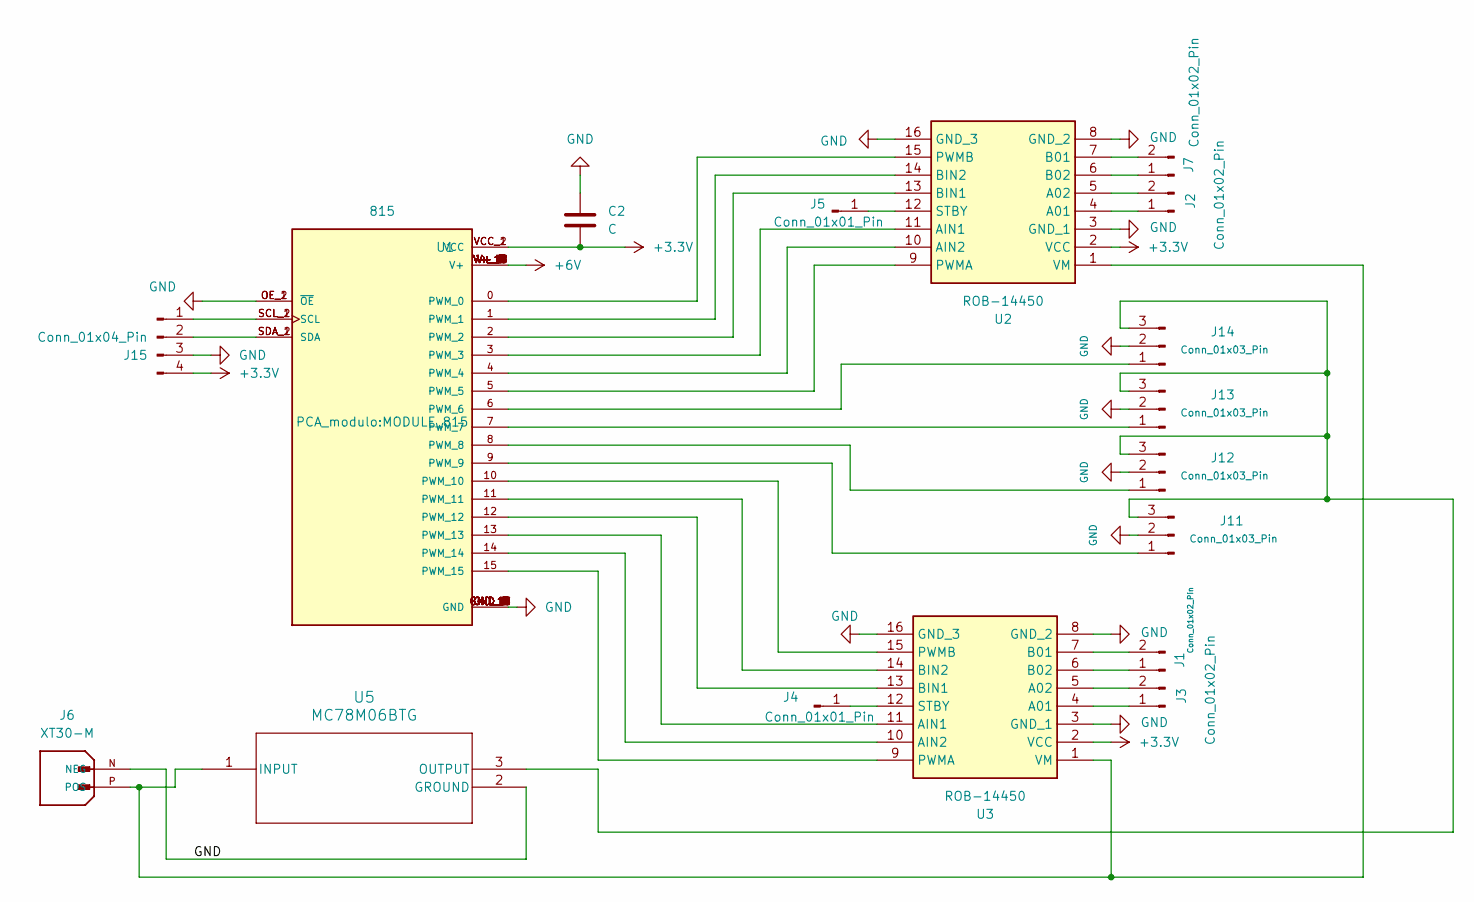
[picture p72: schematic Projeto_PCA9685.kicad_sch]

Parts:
C2: C; C_Radial_D6.3mm_H11.0mm_P2.50mm
J1, J2, J3, J7: Conn_01x02_Pin; JST_XH_B2B-XH-A_1x02_P2.50mm_Vertical
J4, J5: Conn_01x01_Pin; PinHeader_1x01_P2.54mm_Vertical
J6: XT30-M; AMASS_XT30PW-M; PARTREV V1.2
J11, J12, J13, J14: Conn_01x03_Pin; JST_XH_B3B-XH-A_1x03_P2.50mm_Vertical
J15: Conn_01x04_Pin; JST_XH_B4B-XH-A_1x04_P2.50mm_Vertical
U1: 815; MODULE_815; PARTREV C
U2, U3: ROB-14450; ROB14450; Manufacturer_Part_Number ROB-14450; Mouser Part Number 474-ROB-14450
U5: MC78M06BTG; TO220-3_ONS

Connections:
+3.3V: C2.2, J15.4, U1.VCC_1 (VCC), U1.VCC_2 (VCC), U2.2 (VCC), U3.2 (VCC)
+6V: U1.V+_1 (V+), U1.V+_2 (V+), U1.V+_3 (V+), U1.V+_4 (V+), U1.V+_5 (V+), U1.V+_6 (V+), U1.V+_7 (V+), U1.V+_8 (V+), U1.V+_9 (V+), U1.V+_10 (V+), U1.V+_11 (V+), U1.V+_12 (V+), U1.V+_13 (V+), U1.V+_14 (V+), U1.V+_15 (V+), U1.V+_16 (V+), U1.V+_17 (V+), U1.V+_18 (V+)
GND: C2.1, J6.N (NEG), J11.2, J12.2, J13.2, J14.2, J15.3, U1.GND_1 (GND), U1.GND_2 (GND), U1.GND_3 (GND), U1.GND_4 (GND), U1.GND_5 (GND), U1.GND_6 (GND), U1.GND_7 (GND), U1.GND_8 (GND), U1.GND_9 (GND), U1.GND_10 (GND), U1.GND_11 (GND), U1.GND_12 (GND), U1.GND_13 (GND), U1.GND_14 (GND), U1.GND_15 (GND), U1.GND_16 (GND), U1.GND_17 (GND), U1.GND_18 (GND), U1.OE_1 (~OE), U1.OE_2 (~OE), U2.3 (GND_1), U2.8 (GND_2), U2.16 (GND_3), U3.3 (GND_1), U3.8 (GND_2), U3.16 (GND_3), U5.2 (GROUND)
unnamed: J1.1, U3.6 (B02)
unnamed: J1.2, U3.7 (B01)
unnamed: J2.1, U2.4 (A01)
unnamed: J2.2, U2.5 (A02)
unnamed: J3.1, U3.4 (A01)
unnamed: J3.2, U3.5 (A02)
unnamed: J4.1, U3.12 (STBY)
unnamed: J5.1, U2.12 (STBY)
unnamed: J6.P (POS), U2.1 (VM), U3.1 (VM), U5.1 (INPUT)
unnamed: J7.1, U2.6 (B02)
unnamed: J7.2, U2.7 (B01)
unnamed: J11.1, U1.9 (PWM_9)
unnamed: J11.3, J12.3, J13.3, J14.3, U5.3 (OUTPUT)
unnamed: J12.1, U1.8 (PWM_8)
unnamed: J13.1, U1.7 (PWM_7)
unnamed: J14.1, U1.6 (PWM_6)
unnamed: J15.1, U1.SCL_1 (SCL), U1.SCL_2 (SCL)
unnamed: J15.2, U1.SDA_1 (SDA), U1.SDA_2 (SDA)
unnamed: U1.0 (PWM_0), U2.15 (PWMB)
unnamed: U1.1 (PWM_1), U2.14 (BIN2)
unnamed: U1.2 (PWM_2), U2.13 (BIN1)
unnamed: U1.3 (PWM_3), U2.11 (AIN1)
unnamed: U1.4 (PWM_4), U2.10 (AIN2)
unnamed: U1.5 (PWM_5), U2.9 (PWMA)
unnamed: U1.10 (PWM_10), U3.15 (PWMB)
unnamed: U1.11 (PWM_11), U3.14 (BIN2)
unnamed: U1.12 (PWM_12), U3.13 (BIN1)
unnamed: U1.13 (PWM_13), U3.11 (AIN1)
unnamed: U1.14 (PWM_14), U3.10 (AIN2)
unnamed: U1.15 (PWM_15), U3.9 (PWMA)


Board: 2 copper layers, 70.0 x 70.0 mm, 17 parts (0 on the bottom side), 33 nets.

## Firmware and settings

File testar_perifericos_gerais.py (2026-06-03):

import machine
from machine import PWM, Pin
import neopixel
import time
import random
from machine import Pin, SoftI2C, ADC
from ssd1306 import SSD1306_I2C
import math

# Configuração do OLED na BitDogLab v7
i2c = SoftI2C(scl=Pin(3), sda=Pin(2))
oled = SSD1306_I2C(128, 64, i2c)

joystick_button = Pin(22, Pin.IN, Pin.PULL_UP) 
#______________________________________________



# Número de LEDs na sua matriz 5x5
NUM_LEDS = 25

# Inicializar a matriz de NeoPixels no GPIO7
np = neopixel.NeoPixel(Pin(7), NUM_LEDS)

# Definindo a matriz de LEDs
LED_MATRIX = [
    [24, 23, 22, 21, 20],
    [15, 16, 17, 18, 19],
    [14, 13, 12, 11, 10],
    [5, 6, 7, 8, 9],
    [4, 3, 2, 1, 0]
]

# Inicializar ADC para os pinos VRx (GPIO27) e VRy (GPIO26)
adc_vrx = ADC(Pin(27))
adc_vry = ADC(Pin(26))

def map_value(value, in_min, in_max, out_min, out_max):
    return (value - in_min) * (out_max - out_min) // (in_max - in_min) + out_min




#_______________________________________________
def update_oled(lines):
    oled.fill(0)
    for i, line in enumerate(lines):
        oled.text(line, 0, i * 8)
    oled.show()


# Configurando o LED RGB
led_r = PWM(Pin(13))
led_g = PWM(Pin(11))
led_b = PWM(Pin(12))

led_r.freq(1000)
led_g.freq(1000)
led_b.freq(1000)

# Configuração do NeoPixel
NUM_LEDS = 25
np = neopixel.NeoPixel(Pin(7), NUM_LEDS)

# Configuração dos botões
button_a = Pin(5, Pin.IN, Pin.PULL_UP)
button_b = Pin(6, Pin.IN, Pin.PULL_UP)

# definir cores para os LEDs
RED = (50, 0, 0)
GREEN = (0, 50, 0)
BLUE = (0, 0, 50)
YELLOW = (30, 30, 0)
MAGENTA = (30, 0, 30)
CYAN = (0, 30, 30)
WHITE = (25, 25, 25)
BLACK = (0, 0, 0)

# Configuração do Buzzer
buzzer = PWM(Pin(21))
buzzer.freq(50)  # Frequência inicial grave

def gradual_light_sound(duration=2):
    step_duration = duration / 100
    for i in range(101):
        duty_cycle = (i * 65535) // 200  # Calcular o ciclo de trabalho atual

        # Ajustar o LED para a intensidade atual
        led_r.duty_u16(duty_cycle)
        led_g.duty_u16(duty_cycle)
        led_b.duty_u16(duty_cycle)

        # Ajustar a frequência do buzzer
        buzzer.freq(50 + i * 2)  # Ajustar a frequência do buzzer
        
        # Ajustar o volume do buzzer
        buzzer.duty_u16(duty_cycle // 4)  # Reduzir o volume para 25% do máximo
        
        time.sleep(step_duration)

    # Desligar o LED e o buzzer no final
    led_r.duty_u16(0)
    led_g.duty_u16(0)
    led_b.duty_u16(0)
    buzzer.duty_u16(0)

def beep(freq=1000, duration=0.2):
    ''' Toca um beep com a frequência e duração especificadas '''
    buzzer.freq(freq)
    buzzer.duty_u16(5000)  # Intensidade média
    time.sleep(duration)
    buzzer.duty_u16(0)  # Desliga o buzzer
    
def star_trek_beep():
    buzzer = PWM(Pin(21))  # Buzzer A conectado ao GPIO21
    
    # Primeiro tom
    buzzer.freq(1000)
    buzzer.duty_u16(40000)
    time.sleep(0.1)
    buzzer.duty_u16(0)
    
    # Pequena pausa
    time.sleep(0.05)
    
    # Segundo tom
    buzzer.freq(1500)
    buzzer.duty_u16(40000)
    time.sleep(0.1)
    buzzer.duty_u16(0)

    # Pequena pausa
    time.sleep(0.05)

    # Terceiro tom
    buzzer.freq(2000)
    buzzer.duty_u16(40000)
    time.sleep(0.1)
    buzzer.duty_u16(0)



def dim_leds(led_sequence, current_index):
    # Define o fator de diminuição de intensidade baseado no índice atual do LED
    dim_factor = 255 // (len(led_sequence) - current_index)
    for idx, led in enumerate(led_sequence):
        if idx < current_index:
            r, g, b = np[led]
            r = max(r - dim_factor, 0)
            np[led] = (r, g, b)

    
# apagar todos os LEDs
def clear_all():
    for i in range(len(np)):
        np[i] = BLACK
    np.write()

def heartbeat_effect(sequence):
    initial_delay = 0.3  # tempo inicial entre LEDs
    decrement = 0.05  # valor a ser decrementado a cada LED
    
    # Limpa todos os LEDs
    clear_all()

    for idx, led in enumerate(sequence):
        np[led] = (255, 0, 0)  # Acende o LED vermelho
        dim_leds(sequence, idx)  # Diminui o brilho dos LEDs na sequência
        np.write()
        time.sleep(initial_delay - idx * decrement)
        
    # Toca o beep no buzzer
    beep()
    
    # Aguarda um pouco e depois desliga todos os LEDs
    time.sleep(0.3)
    clear_all()

def heart():
    """Acende um coração grande na matriz de LEDs."""
    # Primeiro, desligamos todos os LEDs para garantir que começa "limpo"
    clear_all()
    
    # Lista dos LEDs que devem ser acesos para o coração
    heart_leds = [2, 6, 14, 15, 23, 17, 21, 19, 10, 8]
    
    # Acendendo os LEDs em vermelho
    for led in heart_leds:
        np[led] = (255, 0, 0)  # RED
    
    np.write()
    
# Define O CÓDIGO DE ACENDER OS LEDs DO CORAÇÃO ALEATORIAMENTE
def random_color(dim_factor=1):
    """Gera uma cor aleatória."""
    return (int(random.randint(0, 255) * dim_factor), 
            int(random.randint(0, 255) * dim_factor), 
            int(random.randint(0, 255) * dim_factor))

#efeito de som usada na piscadinha direita
def door_swish():
    for freq in range(1000, 2000, 50):
        buzzer.freq(freq)
        buzzer.duty_u16(40000)
        time.sleep(0.005)
    for freq in range(2000, 1000, -50):
        buzzer.freq(freq)
        buzzer.duty_u16(40000)
        time.sleep(0.005)
    buzzer.duty_u16(0)

def l3_37_sound_and_lights():
    border_heart_leds = [2, 6, 14, 15, 23, 17, 21, 19, 10, 8]
    inner_heart_leds = [7, 13, 12, 11, 16, 18]
    already_illuminated = []

    for freq in [440, 392, 440, 392]:  # Notas: A, G
        random_led = random.choice([led for led in border_heart_leds + inner_heart_leds if led not in already_illuminated])
        already_illuminated.append(random_led)
        color_intensity = 0.5 if random_led in inner_heart_leds else 1  
        np[random_led] = random_color(color_intensity)
        np.write()
        buzzer.freq(freq)
        buzzer.duty_u16(5000)
        time.sleep(0.1)

    for freq in [587, 493, 587, 523]:  # Notas: D, B, D, C
        random_led = random.choice([led for led in border_heart_leds + inner_heart_leds if led not in already_illuminated])
        already_illuminated.append(random_led)
        color_intensity = 0.5 if random_led in inner_heart_leds else 1  
        np[random_led] = random_color(color_intensity)
        np.write()
        buzzer.freq(freq)
        buzzer.duty_u16(5000)
        time.sleep(0.10)

    for led in [l for l in border_heart_leds + inner_heart_leds if l not in already_illuminated]:
        color_intensity = 0.5 if led in inner_heart_leds else 1 
        np[led] = random_color(color_intensity)
        np.write()
        time.sleep(0.1)

        buzzer.duty_u16(0)

def smile_face():
    # Definindo a sequência de cores
    colors = [
        BLACK, BLUE, BLUE, BLUE, BLACK,
        BLUE, BLACK, BLACK, BLACK, BLUE,
        BLACK, BLACK, BLACK, BLACK, BLACK,
        BLACK, CYAN, BLACK, CYAN, BLACK,
        BLACK, BLACK, BLACK, BLACK, BLACK
    ]
    
    # Atribuindo as cores à matriz np
    for i, color in enumerate(colors):
        np[i] = color
    
    np.write()
    
def blink_right_eye():
    np[0] = BLACK
    np[1] = BLUE
    np[2] = BLUE
    np[3] = BLUE
    np[4] = BLACK
    np[5] = BLUE
    np[6] = BLACK
    np[7] = BLACK
    np[8] = BLACK
    np[9] = BLUE
    np[10] = BLACK
    np[11] = BLACK
    np[12] = BLACK
    np[13] = BLACK
    np[14] = BLACK
    np[15] = BLACK
    np[16] = CYAN
    np[17] = BLACK
    np[18] = BLACK
    np[19] = BLACK
    np[20] = BLACK
    np[21] = BLACK
    np[22] = BLACK
    np[23] = BLACK
    np[24] = BLACK

    np.write()
    door_swish()

    # aguardar e retorna a cor azul do olho direito
    time.sleep(.2)
    np[18] = CYAN
    np.write()
    
#define função de som sincronizada com o led da boca piscando
def colour_mouth():


    def r2d2_beep():
        # Primeiro bipe
        buzzer.freq(4000)
        buzzer.duty_u16(30000)
        time.sleep(0.1)
        buzzer.duty_u16(0)
        np[2] = RED
        np.write()
        time.sleep(0.2)
    
        # Segundo bipe
        buzzer.freq(5000)
        buzzer.duty_u16(30000)
        time.sleep(0.15)
        buzzer.duty_u16(0)
        np[2] = CYAN
        np[3] = CYAN
        np[1] = CYAN
        np.write()
        time.sleep(0.2)
    
        # Terceiro bipe
        buzzer.freq(4500)
        buzzer.duty_u16(30000)
        time.sleep(0.12)
        buzzer.duty_u16(0)
        np[2] = RED
        np[3] = RED
        np[1] = RED
        np.write()
        time.sleep(0.2)


    r2d2_beep()

    np[2] = BLUE
    np[3] = BLUE
    np[1] = BLUE
    np.write()
    
def triple_zero_sound():
    # Sequência inicial educada
    for freq in [440, 554, 660]:  # Notas: A, C#, E
        buzzer.freq(freq)
        buzzer.duty_u16(5000)
        time.sleep(0.1)
        
        np[16] = BLACK
        np[18] = BLACK
        np.write()

    # Transição sinistra e abrupta
    for freq in range(660, 880, 5):
        buzzer.freq(freq)
        buzzer.duty_u16(5000)
        time.sleep(0.005)
    
    # Parada súbita
    buzzer.freq(880)
    time.sleep(0.3)
    
    np[16] = CYAN 
    np[18] = CYAN
    np.write()
    # Desliga o buzzer ao final
    buzzer.duty_u16(0)
    
def seta_Direita():
    np[0] = BLACK
    np[1] = BLACK
    np[2] = YELLOW
    np[3] = BLACK
    np[4] = BLACK
    np[5] = BLACK
    np[6] = BLACK
    np[7] = BLACK
    np[8] = YELLOW
    np[9] = BLACK
    np[10] = YELLOW
    np[11] = YELLOW
    np[12] = YELLOW
    np[13] = YELLOW
    np[14] = YELLOW
    np[15] = BLACK
    np[16] = BLACK
    np[17] = BLACK
    np[18] = YELLOW
    np[19] = BLACK
    np[20] = BLACK
    np[21] = BLACK
    np[22] = YELLOW
    np[23] = BLACK
    np[24] = BLACK
    np.write()
    # Desliga o buzzer ao final
    buzzer.duty_u16(0)
    
def seta_Esquerda():
    np[0] = BLACK
    np[1] = BLACK
    np[2] = YELLOW
    np[3] = BLACK
    np[4] = BLACK
    np[5] = BLACK
    np[6] = YELLOW
    np[7] = BLACK
    np[8] = BLACK
    np[9] = BLACK
    np[10] = YELLOW
    np[11] = YELLOW
    np[12] = YELLOW
    np[13] = YELLOW
    np[14] = YELLOW
    np[15] = BLACK
    np[16] = YELLOW
    np[17] = BLACK
    np[18] = BLACK
    np[19] = BLACK
    np[20] = BLACK
    np[21] = BLACK
    np[22] = YELLOW
    np[23] = BLACK
    np[24] = BLACK
    np.write()
    # Desliga o buzzer ao final
    buzzer.duty_u16(0)
    
    
def xplosion():
    # Definindo a sequência de cores
    colors = [
        BLACK, BLACK, BLACK, BLACK, BLACK,
        BLACK, BLACK, BLACK, BLACK, BLACK,
        BLACK, BLACK, RED, BLACK, BLACK,
        BLACK, BLACK, BLACK, BLACK, BLACK,
        BLACK, BLACK, BLACK, BLACK, BLACK
    ]
    
    # Atribuindo as cores à matriz np
    for i, color in enumerate(colors):
        np[i] = color
    
    np.write()
    
    time.sleep(.1)
    
    # Som forte e abrupto
    for freq in range(2000, 50, -50):
        buzzer.freq(freq)
        buzzer.duty_u16(32767)  # 50% de duty cycle
        time.sleep(0.005)
    
    
    colors = [
        BLACK, BLACK, BLACK, BLACK, BLACK,
        BLACK, BLACK, RED, BLACK, BLACK,
        BLACK, RED, BLUE, RED, BLACK,
        BLACK, BLACK, RED, BLACK, BLACK,
        BLACK, BLACK, BLACK, BLACK, BLACK
    ]
    
    # Atribuindo as cores à matriz np
    for i, color in enumerate(colors):
        np[i] = color
    
    np.write()
    
    time.sleep(.2)
    
        
    colors = [
        BLACK, BLACK, RED, BLACK, BLACK,
        BLACK, RED, BLUE, RED, BLACK,
        RED, BLUE, WHITE, BLUE, RED,
        BLACK, RED, BLUE, RED, BLACK,
        BLACK, BLACK, RED, BLACK, BLACK
    ]
    
    # Atribuindo as cores à matriz np
    for i, color in enumerate(colors):
        np[i] = color
    
    np.write()
    
    time.sleep(.2)
    
    colors = [
        BLACK, RED, RED, RED, BLACK,
        RED, BLUE, WHITE, BLUE, RED,
        RED, WHITE, WHITE, WHITE, RED,
        RED, BLUE, WHITE, BLUE, RED,
        BLACK, RED, RED, RED, BLACK
    ]
    
    # Atribuindo as cores à matriz np
    for i, color in enumerate(colors):
        np[i] = color
    
    np.write()
    
    time.sleep(.2)
    
    colors = [
        BLACK, WHITE, WHITE, WHITE, BLACK,
        WHITE, WHITE, WHITE, WHITE, WHITE,
        WHITE, WHITE, BLACK, WHITE, WHITE,
        WHITE, WHITE, WHITE, WHITE, WHITE,
        BLACK, WHITE, WHITE, WHITE, BLACK
    ]
    
    # Atribuindo as cores à matriz np
    for i, color in enumerate(colors):
        np[i] = color
    
    np.write()
    
        
    time.sleep(.1)
    
    colors = [
        BLACK, WHITE, WHITE, WHITE, BLACK,
        WHITE, BLACK, BLACK, BLACK, WHITE,
        WHITE, BLACK, BLACK, BLACK, WHITE,
        WHITE, BLACK, BLACK, BLACK, WHITE,
        BLACK, WHITE, WHITE, WHITE, BLACK
    ]
    
    # Atribuindo as cores à matriz np
    for i, color in enumerate(colors):
        np[i] = color
    
    np.write()
    
    time.sleep(.2)
    
    colors = [
        BLACK, WHITE, BLACK, WHITE, BLACK,
        WHITE, BLACK, BLACK, BLACK, WHITE,
        BLACK, BLACK, BLACK, BLACK, BLACK,
        WHITE, BLACK, BLACK, BLACK, WHITE,
        BLACK, WHITE, BLACK, WHITE, BLACK
    ]
    
    # Atribuindo as cores à matriz np
    for i, color in enumerate(colors):
        np[i] = color
    
    np.write()
    
    
    clear_all()
    time.sleep(.2)
    
    colors = [
        BLACK, WHITE, BLACK, WHITE, BLACK,
        WHITE, BLACK, BLACK, BLACK, WHITE,
        BLACK, BLACK, BLACK, BLACK, BLACK,
        WHITE, BLACK, BLACK, BLACK, WHITE,
        BLACK, WHITE, BLACK, WHITE, BLACK
    ]
    
    # Atribuindo as cores à matriz np
    for i, color in enumerate(colors):
        np[i] = color
    
    np.write()
    
    # Reverberações ou ecos mais suaves
    for _ in range(5):
        buzzer.duty_u16(16383)  # 25% de duty cycle
        time.sleep(0.1)
        buzzer.duty_u16(0)  # Desliga
        time.sleep(0.1)

    buzzer.duty_u16(0)  # Certifique-se de que o buzzer esteja desligado
    
# Inicialização do Neopixel e ADC para o microfone
#np = neopixel.NeoPixel(machine.Pin(PIN_NUM), NUM_LEDS)
adc = machine.ADC(machine.Pin(28))  # GP28 para o microfone

OFFSET = int(1.65 / 3.3 * 65536)  # Valor ADC correspondente a 1,65V

# Definição dos patamares
patamares = [
    [2],
    [1, 2, 3],
    [7, 1, 2, 3],
    [12, 6, 7, 8, 0, 1, 2, 3, 4],
    [12, 6, 7, 8, 0, 1, 2, 3, 4, 11, 13, 17, 5, 9],
    [12, 6, 7, 8, 0, 1, 2, 3, 4, 11, 13, 17, 5, 9, 22, 16, 18, 10, 14],
    [12, 6, 7, 8, 0, 1, 2, 3, 4, 11, 13, 17, 5, 9, 22, 16, 18, 10, 14, 15, 19],
    [12, 6, 7, 8, 0, 1, 2, 3, 4, 11, 13, 17, 5, 9, 22, 16, 18, 10, 14, 15, 19, 20, 21, 23, 24]
] * 2

def determinar_cor(patamar_index):
    if patamar_index < len(patamares) / 3.5:
        return (0, 0, 85)  # Azul
    else:
        return (105, 0, 0)  # Vermelho

def acender_leds(patamar_index):
    cor = determinar_cor(patamar_index)
    
    # Primeiro, desligamos todos os LEDs
    for i in range(NUM_LEDS):
        np[i] = (0, 0, 0)

    # Depois, acendemos os LEDs do patamar atual
    for i in patamares[patamar_index]:
        np[i] = cor
        
    np.write()

def acender_por_valor(ratio):
    max_patamares = len(patamares)
    patamar_index = int(ratio * max_patamares)
    patamar_index = min(patamar_index, max_patamares - 1)  # Evitar índices fora da faixa

    # Se o ratio estiver abaixo de um limiar, desliga todos os LEDs
    if ratio < 0.05:
        for i in range(NUM_LEDS):
            np[i] = (0, 0, 0)
        np.write()
    else:
        acender_leds(patamar_index)


def vu_meter(adc_value):
    volume = max(0, (adc_value - OFFSET)*2)  # Subtrai o offset e garante que o valor seja positivo
    volume_ratio = volume / 65536.0
    normalized_ratio = math.pow(volume_ratio, 0.5)  # Ajustando a sensibilidade

    acender_por_valor(normalized_ratio)

    
        
#------------------------
clear_all()
# Chamar a função
gradual_light_sound()

# Sequência de LEDs para simular o pulso cardíaco
sequence = [14, 6, 12, 17, 21, 10]

# Especifica o número de repetições desejado
num_repetitions = 3
for _ in range(num_repetitions):
    heartbeat_effect(sequence)
    # Exibe o coração grande
    heart()
    time.sleep(0.2)

l3_37_sound_and_lights()
time.sleep(1.5)


#update_oled("OLA HUMANO!")
messages = [
    "           ",
    "           ",
    "  OLA  HUMANO!",
    "           "
    "           ",
    "           ",
    "           ",
    "           "
]
update_oled(messages)


# Primeiro, desligamos todos os LEDs para garantir que começa "limpo"
clear_all()
time.sleep(1.5)

smile_face()
time.sleep(1)

blink_right_eye()
time.sleep(1)

colour_mouth()
time.sleep(2.2)

triple_zero_sound()
time.sleep(2)

clear_all()


# Defina as cores que você deseja alternar
cores = [(255, 0, 0), (0, 255, 0), (0, 0, 255)]  # vermelho, verde, azul
indice_cor = 0  # Índice da cor atual na lista de cores

while True:
    # Primeira parte: Seta esquerda e espera pelo botão A
    seta_Esquerda()
    time.sleep(.5)
    clear_all()
    time.sleep(.2)
    seta_Esquerda()
    time.sleep(.3)
    clear_all()
    time.sleep(.3)
    seta_Esquerda()
    

    
    messages = [
    "           ",
    "           ",
    "    APERTE  ",
    "           ",
    "       A     ",
    "           ",
    "           ",
    "           "
    ]
    update_oled(messages)
    
    # Aguarde até o Botão A ser pressionado
    while button_a.value():
        time.sleep(0.1)  # Adicione um delay para debounce
    
    clear_all()
    xplosion()
    
    # Segunda parte: Seta direita e espera pelo botão B
    seta_Direita()
    time.sleep(.5)
    clear_all()
    time.sleep(.2)
    seta_Direita()
    time.sleep(.3)
    clear_all()
    time.sleep(.3)
    seta_Direita()
       

    messages = [
    "           ",
    "           ",
    "    APERTE  ",
    "           ",
    "       B     ",
    "           ",
    "           ",
    "           "
    ]
    update_oled(messages)
    
    # Aguarde até o Botão B ser pressionado
    while button_b.value():
        time.sleep(0.1)  # Adicione um delay para debounce
    
    clear_all()
    xplosion()
    
    update_oled("             ")
    update_oled("Mova Joystick")
    
    messages = [
    "           ",
    " Mova Joystick ",
    "           ",
    "           ",
    "           ",
    "           ",
    "           ",
    "           ",
    ]
    update_oled(messages)
    
    time.sleep(1)   
    colors = [
        GREEN, GREEN, GREEN, GREEN, BLACK,
        BLACK, GREEN, GREEN, BLACK, BLACK,
        BLACK, BLACK,  GREEN, GREEN, BLACK,
        BLACK, GREEN, BLACK, GREEN, BLACK,
        GREEN, BLACK, BLACK, GREEN, BLACK
    ]
    
    
    # Atribuindo as cores à matriz np
    for i, color in enumerate(colors):
        np[i] = color
    
    np.write()
    time.sleep(2)
    

    messages = [
    "           ",
    " Mova Joystick ",
    "           ",
    "           ",
    "           ",
    "           ",
    "           ",
    "           ",
    ]
    update_oled(messages)
    
    # Agora entre no modo de controle do joystick
    while True:
        vrx_value = adc_vrx.read_u16()
        vry_value = adc_vry.read_u16()
    
        messages = [
            "           ",
            "           ",
            "   APERTE  ",
            "           ",
            "     B     ",
            "      para   ",
            "           ",
            "    SAIR   ",
        ]
        update_oled(messages)
    
        offsetx = 0
        offsety = 400
        row = map_value(vrx_value - offsetx, 240, 65279, 0, 4)
        col = map_value(vry_value - offsety, 65278, 240, 0, 4)
        
        for i in range(NUM_LEDS):
            np[i] = (0, 0, 0)
        
        led_index = LED_MATRIX[row][col]
        #beep(50, 4000)  # Toca um beep rápido
        np[led_index] = cores[indice_cor]  # Use a cor atual
        np.write()
        
        # Verifica se o botão do joystick está pressionado
        if not joystick_button.value():
            indice_cor = (indice_cor + 1) % len(cores)  # Atualiza o índice da cor
            star_trek_beep()
            print("Botão do joystick pressionado. Mudando a cor.")
        
        # Verifica se o botão B está pressionado
        if not button_b.value():
            print("Botão B pressionado. Saindo do modo de controle do joystick.")
            update_oled("                ")
            break  # Sai do loop se o botão B estiver pressionado
        
        time.sleep(0.1)

    
    
   

    # Aguarde até que o botão B seja liberado
    while not button_b.value():
        time.sleep(0.1)
       
    update_oled("             ")
    update_oled("Escutando")
    
    messages = [
    "  Escutando ",
    "           ",
    "   APERTE  ",
    "           ",
    "     B     ",
    "      para   ",
    "           ",
    "    SAIR     ",
    ]
    update_oled(messages)
    
      

    # Modo VU Meter 
    while True:  
        if button_b.value():
            adc_value = adc.read_u16()  # Lendo o valor do ADC do microfone
            vu_meter(adc_value)  # Atualizando o VU meter com base no valor do ADC
            time.sleep(0.02)  # Um pequeno atraso para tornar o loop manejável
        else:
            print("Botão B pressionado. Saindo do modo VU Meter.")
            break  # Sai do loop se o botão B estiver pressionado
            update_oled("             ")
            update_oled(" OLA EHUMANO")
                
            messages = [
            "           ",
            "           ",
            "   OLA EHUMANO  ",
            "           ",
            "           ",
            "           ",
            "           ",
            "           ",
            ]
            update_oled(messages)
    
            

time.sleep(0.1)

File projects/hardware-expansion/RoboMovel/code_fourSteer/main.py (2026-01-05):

from machine import Pin, PWM, UART
from time import sleep

uart = UART(0, baudrate=9600, tx=Pin(0), rx=Pin(1))

STBY = Pin(20, Pin.OUT)
STBY.value(1)

LEFT_FWD = Pin(4, Pin.OUT)
LEFT_BWD = Pin(9, Pin.OUT)
LEFT_PWM = PWM(Pin(8))

RIGHT_FWD = Pin(19, Pin.OUT)
RIGHT_BWD = Pin(18, Pin.OUT)
RIGHT_PWM = PWM(Pin(16))

buzPin = Pin(21, Pin.OUT)
ledPin = Pin(22, Pin.OUT)

LEFT_PWM.freq(1000)
RIGHT_PWM.freq(1000)
valSpeed = 40000

def set_speed(duty):
    global valSpeed
    valSpeed = duty
    LEFT_PWM.duty_u16(valSpeed)
    RIGHT_PWM.duty_u16(valSpeed)

def stop_all():
    LEFT_FWD.value(0); LEFT_BWD.value(0); LEFT_PWM.duty_u16(0)
    RIGHT_FWD.value(0); RIGHT_BWD.value(0); RIGHT_PWM.duty_u16(0)

def forward():
    LEFT_FWD.value(1); LEFT_BWD.value(0); LEFT_PWM.duty_u16(valSpeed)
    RIGHT_FWD.value(1); RIGHT_BWD.value(0); RIGHT_PWM.duty_u16(valSpeed)

def backward():
    LEFT_FWD.value(0); LEFT_BWD.value(1); LEFT_PWM.duty_u16(valSpeed)
    RIGHT_FWD.value(0); RIGHT_BWD.value(1); RIGHT_PWM.duty_u16(valSpeed)

def left():
    LEFT_FWD.value(1); LEFT_BWD.value(0); LEFT_PWM.duty_u16(valSpeed)
    RIGHT_FWD.value(0); RIGHT_BWD.value(1); RIGHT_PWM.duty_u16(valSpeed)

def right():
    LEFT_FWD.value(0); LEFT_BWD.value(1); LEFT_PWM.duty_u16(valSpeed)
    RIGHT_FWD.value(1); RIGHT_BWD.value(0); RIGHT_PWM.duty_u16(valSpeed)

print("Controle pronto! Aguardando HC-05 (UART0 GP0/GP1)...")

while True:
    if uart.any():
        b = uart.read(1)
        if not b:
            continue
        try:
            command = b.decode('utf-8').strip().upper()
        except:
            continue
        if command == "":
            continue
        print("Recebido:", command)
        cmd = command[0]
        if cmd == 'F':
            forward(); print("-> Frente")
        elif cmd == 'B':
            backward(); print("-> Trás")
        elif cmd == 'L':
            left(); print("-> Esquerda")
        elif cmd == 'R':
            right(); print("-> Direita")
        elif cmd == 'S':
            stop_all(); print("-> Parar")
        elif cmd == 'Y':
            buzPin.value(1); sleep(0.2); buzPin.value(0); print("-> Buzina")
        elif cmd == 'X':
            ledPin.value(1); print("-> LED ON")
        elif cmd == 'x':
            ledPin.value(0); print("-> LED OFF")
        elif cmd in '0123456789':
            scale = int(cmd)
            set_speed(int(65535 * scale / 9))
            print("-> Velocidade ajustada:", scale)

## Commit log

2023-05-24 Add files via upload
    KiCad file for PCI colaborative design
    [Placa Base Xplorer Raspberry pi pico V3B.kicad_pcb]
2023-07-24 Draft do esquematico da bitdoglab 2.0
    [1063.step, 2D-Analog-Thumb-Joystick.step, Base-Board.step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]
2023-07-30 Começo da construção do layout
    [Pantalla OLED 0.96'' 128x64.stp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]
2023-07-30 Finalizacao do placement dos componentes
    [bitdoglab_v1b.kicad_pcb, bitdoglab_v1b.kicad_sch]
2023-07-31 roteamento e apagando backups
    [bitdoglab_v1b.kicad_pcb, bitdoglab_v1b.kicad_sch, freerouting.dsn]
2023-08-01 Ajustes no roteamento
    [bitdoglab_v1b.kicad_pcb, bitdoglab_v1b.kicad_sch, freerouting.dsn]
2023-08-02 Modificações no layout do professor e envio para confeccao
    [bitdoglab_v1b.kicad_pcb]
2023-08-02 mudança da versão do projeto para 3.0a e 3d da matrix de leds
    [WS2812_RGB_LED_Updated.igs, WS2812_RGB_LED_updated.stp, WS2812b Updated.prt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]
2023-08-02 V3A mudanca do socket da barra de pinos
    [bitdoglab_v3a.kicad_pcb]
2023-08-31 versao 4.1 diretamente no layout
    [COM-09032.step, bitdoglab_v3a.kicad_pcb, bitdoglab_v41.kicad_pcb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]
2023-09-03 Mudar VBUS para VSYS no IDC e JACARE
    [Placa Base Xplorer Raspberry pi pico V3B.kicad_pcb, bitdoglab_v41.kicad_pcb, bitdoglab_v41.kicad_sch]
2023-09-10 Atualizacao do 3D da matriz de leds
    [bitdoglab_v41.kicad_pcb]
2023-09-10 Adição dos gerbers da versão 4.1
    [bitdoglab_v41-B_Cu.gbr, bitdoglab_v41-B_Mask.gbr, bitdoglab_v41-B_Paste.gbr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]
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2023-10-15 Add files via upload
    BOM (Bill of Material)
    https://docs.google.com/spreadsheets/d/10G9U2lKZ8DwIemRyy8-OiIrZH5e2oOeCSGOkK32-5-8/edit?usp=sharing
2023-10-25 inicio da sincronizacao do esquematico da versão 5.0
    [bitdoglab_v41-B_Cu.gbr, bitdoglab_v41-B_Mask.gbr, bitdoglab_v41-B_Paste.gbr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]
2023-10-25 Sincronizar layout com esquematico - parte 1
    [bitdoglab_v5.kicad_pcb, bitdoglab_v5.kicad_sch]
2023-10-26 Sincronizar layout com esquematico - parte 2
    [bitdoglab_v5.kicad_pcb, bitdoglab_v5.kicad_sch]
2023-10-30 Sincronizar layout com esquematico - parte 3
    [bitdoglab_v5.kicad_pcb, bitdoglab_v5.kicad_sch]
2024-02-04 Pacotes de libs e json para o mip install da BitDogLab 5.0
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2024-02-24 Moved all files from kicad hardware folder to bitdoglab folder (modularized version), created a new folder for bitdoglabsmd (surface mount version) and upload all kicad project files for the smd vers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
    [0603 Chip SMD LED (1.6x0.8mm) - Copia.STEP, 0603 Chip SMD LED (1.6x0.8mm).STEP, 1063.step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]
2024-02-24 Inserted informations at README.md about the SMD v5.1 released version.
2024-02-24 Corrections of BOM spreadsheet and CSV files for version 5.1
2024-02-27 BitDogLab SMD version 5.2
    [SMT-microinterruptor momentяneo.SLDPRT, bitdoglab_smd.kicad_sch, bitdoglab_smd_BOM_5v1.csv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]
2024-03-17 BitDogLab V5.3 - see release notes inside kicad/bitdoglabsmd folder
    [0603 Chip SMD LED (1.6x0.8mm) - Copia.STEP, 0603 Chip SMD LED (1.6x0.8mm).STEP, 12mm Push Button with Cap.STEP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]
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2024-04-01 Sincronizacao da placa com o esquemático
    [bitdoglab_v5.kicad_pcb, bitdoglab_v5.kicad_sch, freerouting.dsn]
2024-04-02 versao 5.4
    [bitdoglab.kicad_pcb, bitdoglab.kicad_sch, bitdoglab_v5.kicad_pcb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]
2024-04-02 removendo a versao 4.2
    [1063.step, 2D-Analog-Thumb-Joystick.step, Base-Board.step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]
2024-04-02 change buttons footprints for 12mm
    [bitdoglab.kicad_pcb, bitdoglab.kicad_sch]
2024-04-26 joystick works on smd version and tests with timers
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2024-05-03 adding templates for flask app
    [dados.csv]
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2024-06-27 Add files via upload
    esse arquivo é usado no projeto Mais Verde Mais Vida para comandar as válvulas solenoides na maquete úmida do projeto de irrigação
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2024-10-30 Biblioteca em MicroPython dedicada para placa expansora de canais PWM e saídas lógicas da Escola 4.0.
2025-07-10 feat: README e arquivos de fabricação do módulo WIreless
    [V1A-B_Cu.gbr, V1A-B_Mask.gbr, V1A-B_Paste.gbr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]
2025-11-17 adicao de arquivos TCC Arthur
    [ABS_1.0070_chassis_para_4x4_v4.STL, PCB_4steer_Arthur.SLDPRT, Projeto_PCA9685.kicad_pcb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]
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2026-06-03 chore: reorganize software folders
    [ABS_1.0070_chassis_para_4x4_v4.STL, PCB_4steer_Arthur.SLDPRT, Projeto_PCA9685.kicad_pcb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]
2026-06-03 chore: move software projects to root projects folder
    [ABS_1.0070_chassis_para_4x4_v4.STL, PCB_4steer_Arthur.SLDPRT, Projeto_PCA9685.kicad_pcb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]
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2026-06-03 reorganize PCB prototyping files and document V6 V7 hardware sources
    [0603 Chip SMD LED (1.6x0.8mm) - Copia.STEP, 0603 Chip SMD LED (1.6x0.8mm).STEP, 1063.step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]
2026-07-01 Description BitDogLab Fluxcode App
    Expanded the description of the BitDogLab FluxCode application, detailing its features, requirements, installation process, and common issues. Added sections on how to use the application, including capturing flowcharts and executing code.
2026-07-09 Enhance README Pt with new content and structure
    Updated the README file to include new sections on learning flow, programming projects, and hardware details.
2026-10-03 Change image for BitDogLab board in README
    Updated the image reference for the BitDogLab board.
2026-10-10 Implement SH1107 driver for OLED display
    Add SH1107 driver for MicroPython with I2C interface.
    sh1107_bitdoglab.py
    # versão: outubro de 2026 - Fruett
    # Driver MicroPython para OLED SH1107 128x128
    # BitDogLab

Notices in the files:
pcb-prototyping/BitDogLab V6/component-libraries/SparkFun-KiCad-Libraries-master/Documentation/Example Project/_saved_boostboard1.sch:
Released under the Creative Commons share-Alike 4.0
